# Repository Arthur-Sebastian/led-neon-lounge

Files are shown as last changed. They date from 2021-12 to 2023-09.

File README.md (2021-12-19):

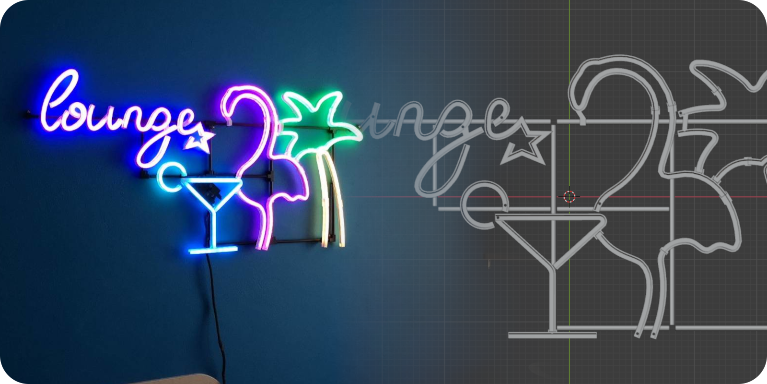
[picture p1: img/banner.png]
Banner image

# LED Lounge Neon!
An RGB LED neon project using 3d printed parts and custom AVR-based controller board with included software.

## PCB
Printed circuit board design (one-layer) files can be found inside ['/pcb'](/pcb). It was created in KiCad open-source
EDA.
The design includes all the parts names,
package formats, and source schematic. It can all be found by opening ['pcb.pro'](/pcb/pcb.pro). file.

## AVR source code and binary
The controller board uses a popular MCU, an ATmega168p. Software source can be found inside ['/src'](/src).
Compile using the included shell script, or create a makefile for yourself. The binary file ['/src/bin/out.bin'](/src/bin/out.bin)
can be directly uploaded to a matching MCU by using the 'upload.sh' script - it assumes your serial-usb converter is connected to
/dev/ttyUSB0 and that your MCU has a USART capable bootloader. Modify if needed.

## 3D Models for printing
Can be found inside ['/resource_3d'](/resource_3d). Those are all Blender files. 
All necessary STL exports are already made and contained within stl_* folders. 
Slice using your favourite tool, and print! 
(All models are optimised to fit a PRUSA Mini or bigger - min. work area of 175 x 175 x 175mm).

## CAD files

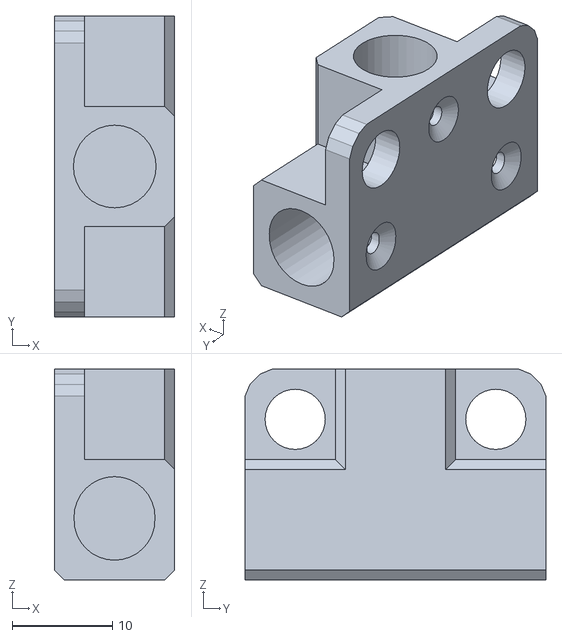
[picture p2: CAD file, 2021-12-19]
resource_3d/stl_framing/frame_T.stl
12.0 x 30.0 x 21.0

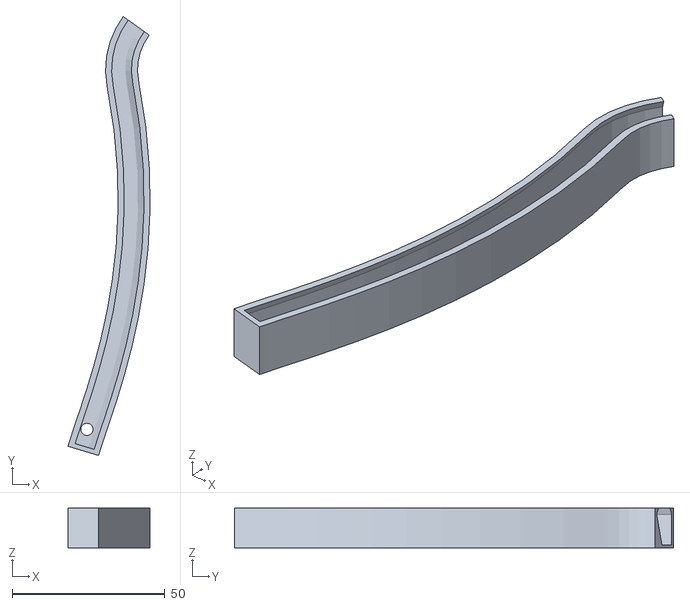
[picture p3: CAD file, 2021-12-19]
resource_3d/stl_shapes/flamingo_5.stl
26.9 x 143.9 x 13.0

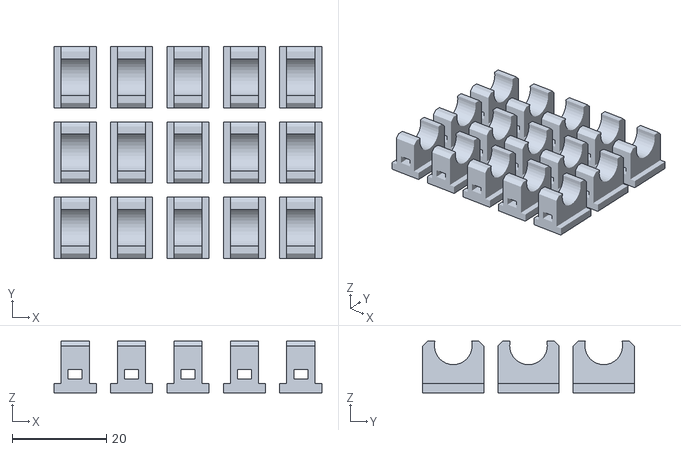
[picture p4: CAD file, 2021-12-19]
resource_3d/stl_framing/clamp.stl
57.0 x 45.0 x 11.0

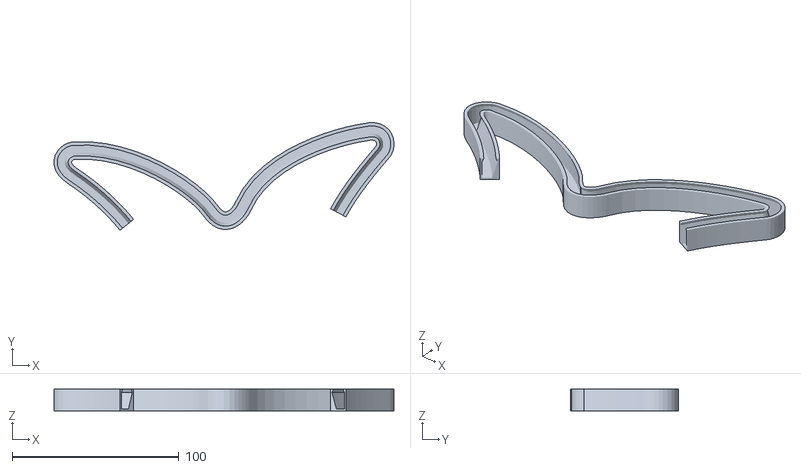
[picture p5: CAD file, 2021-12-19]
resource_3d/stl_shapes/palm_2.stl
204.1 x 64.6 x 13.0

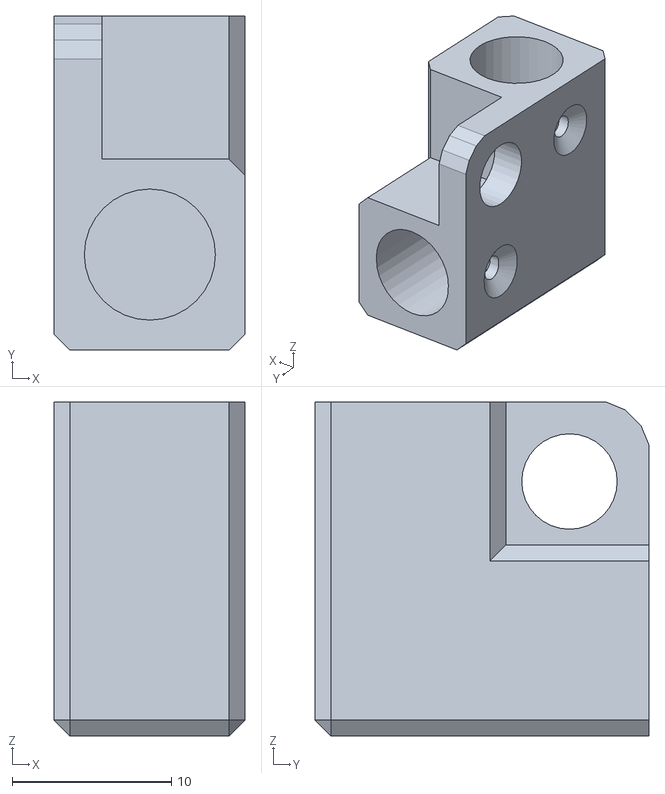
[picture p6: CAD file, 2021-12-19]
resource_3d/stl_framing/frame_L.stl
12.0 x 21.0 x 21.0

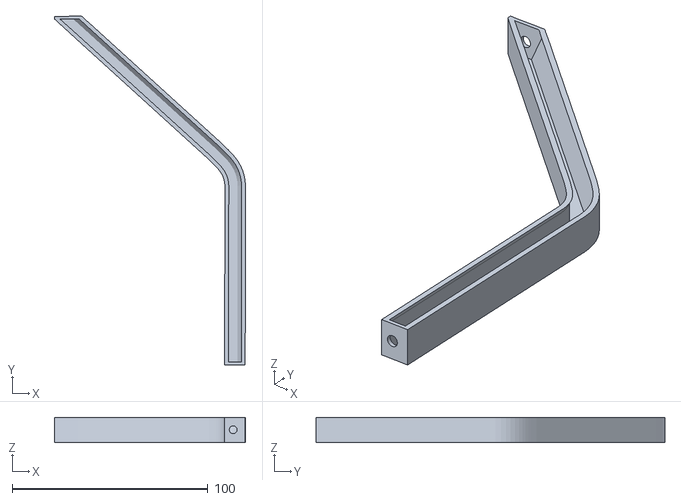
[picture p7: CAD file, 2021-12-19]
resource_3d/stl_shapes/glass_2.stl
97.5 x 178.0 x 13.0

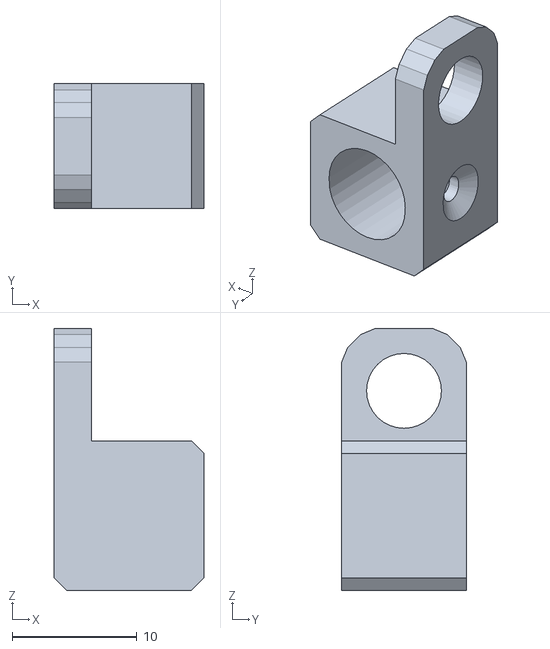
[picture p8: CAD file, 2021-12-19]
resource_3d/stl_framing/frame_E.stl
12.0 x 10.0 x 21.0

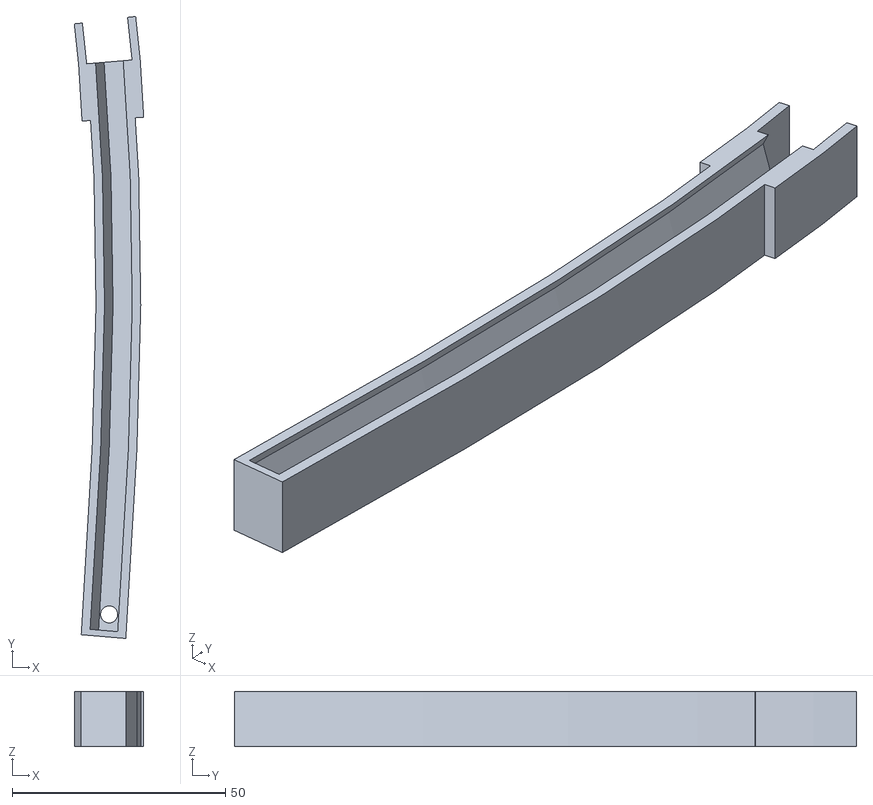
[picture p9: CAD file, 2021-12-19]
resource_3d/stl_shapes/palm_5.stl
16.3 x 145.9 x 13.0

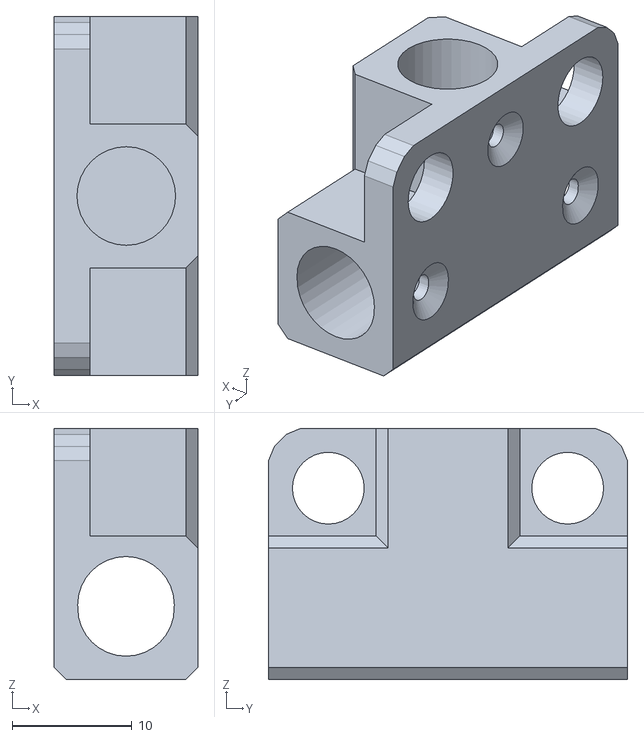
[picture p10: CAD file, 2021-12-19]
resource_3d/stl_framing/frame_P.stl
12.0 x 30.0 x 21.0

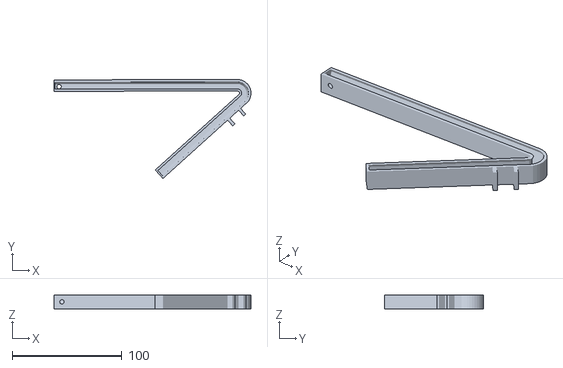
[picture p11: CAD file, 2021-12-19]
resource_3d/stl_shapes/glass_1.stl
179.5 x 90.2 x 13.0

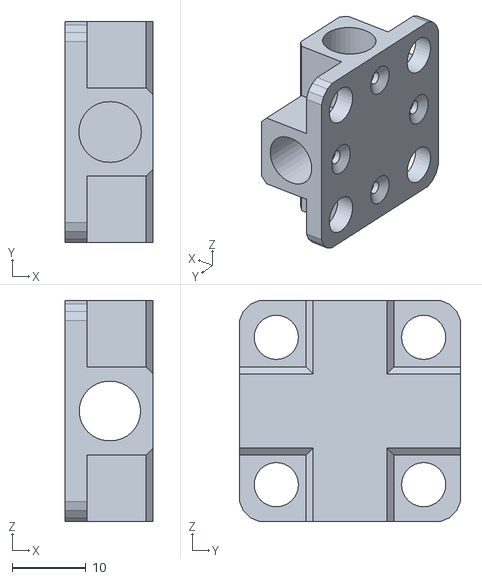
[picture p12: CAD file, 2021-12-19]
resource_3d/stl_framing/frame_X.stl
12.0 x 30.0 x 30.0

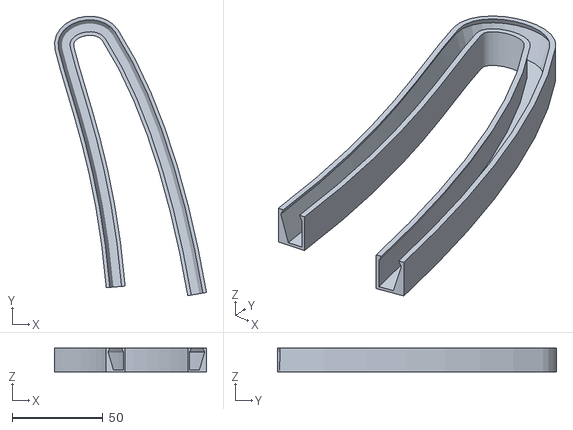
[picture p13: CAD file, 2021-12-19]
resource_3d/stl_shapes/palm_4.stl
83.9 x 154.2 x 13.0

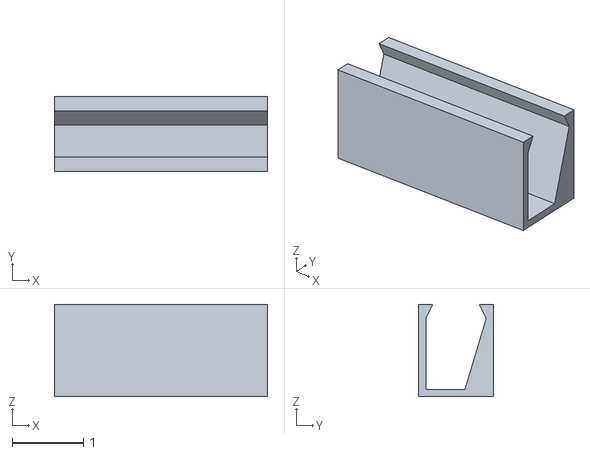
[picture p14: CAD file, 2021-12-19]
resource_3d/stl_framing/frametest.stl
3.00 x 1.05 x 1.30

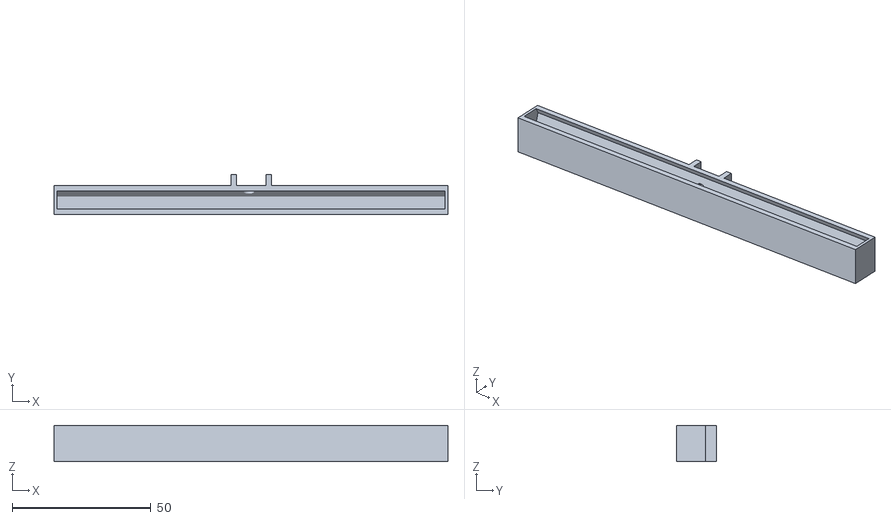
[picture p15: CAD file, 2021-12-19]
resource_3d/stl_shapes/glass_3.stl
142.0 x 14.5 x 13.0

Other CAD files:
resource_3d/stl_shapes/flamingo_2.stl
resource_3d/stl_shapes/garnish_1.stl
resource_3d/stl_shapes/flamingo_1.stl
resource_3d/stl_shapes/palm_3.stl
resource_3d/mainmodel.blend
resource_3d/stl_shapes/flamingo_3.stl
resource_3d/stl_shapes/flamingo_4.stl
resource_3d/stl_shapes/flamingo_6.stl
resource_3d/stl_shapes/lounge_1.stl
resource_3d/stl_shapes/lounge_2.stl
resource_3d/stl_shapes/lounge_3.stl
resource_3d/stl_shapes/lounge_4.stl
resource_3d/stl_shapes/palm_1.stl
resource_3d/stl_shapes/palm_6.stl

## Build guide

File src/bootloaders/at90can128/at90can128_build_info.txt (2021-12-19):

Optiboot_flash build output for at90can128 
https://github.com/MCUdude/optiboot_flash 
Build date and time: 15.05.2019 23:29 
Compiler: avr-gcc 5.4.0
 
F_CPU:		UART NUMBER:	LED PIN:	LED FLASHES:	EEPROM SUPPORT:	FLASH PG COPY:	DESIRED BAUD:	ACTUAL BAUD:	ERROR:	COMPILED SIZE:	OUTPUT FILE:
24000000L	UART0		B5		2		Yes		No		1000000		1000000		0.0%	636 bytes	optiboot_flash_at90can128_UART0_1000000_24000000L_BIGBOOT.hex
24000000L	UART0		B5		2		Yes		No		500000		500000		0.0%	636 bytes	optiboot_flash_at90can128_UART0_500000_24000000L_BIGBOOT.hex
24000000L	UART0		B5		2		Yes		No		250000		250000		0.0%	638 bytes	optiboot_flash_at90can128_UART0_250000_24000000L_BIGBOOT.hex
24000000L	UART0		B5		2		Yes		No		230400		230769		0.1%	638 bytes	optiboot_flash_at90can128_UART0_230400_24000000L_BIGBOOT.hex
24000000L	UART0		B5		2		Yes		No		115200		115384		0.1%	638 bytes	optiboot_flash_at90can128_UART0_115200_24000000L_BIGBOOT.hex
24000000L	UART0		B5		2		Yes		No		57600		57692		0.1%	638 bytes	optiboot_flash_at90can128_UART0_57600_24000000L_BIGBOOT.hex
24000000L	UART0		B5		2		Yes		No		38400		38461		0.1%	638 bytes	optiboot_flash_at90can128_UART0_38400_24000000L_BIGBOOT.hex
24000000L	UART0		B5		2		Yes		No		19200		19230		0.1%	638 bytes	optiboot_flash_at90can128_UART0_19200_24000000L_BIGBOOT.hex
20000000L	UART0		B5		2		Yes		No		500000		500000		0.0%	638 bytes	optiboot_flash_at90can128_UART0_500000_20000000L_BIGBOOT.hex
20000000L	UART0		B5		2		Yes		No		250000		250000		0.0%	638 bytes	optiboot_flash_at90can128_UART0_250000_20000000L_BIGBOOT.hex
20000000L	UART0		B5		2		Yes		No		115200		113636		-1.3%	638 bytes	optiboot_flash_at90can128_UART0_115200_20000000L_BIGBOOT.hex
20000000L	UART0		B5		2		Yes		No		19200		19230		0.1%	638 bytes	optiboot_flash_at90can128_UART0_19200_20000000L_BIGBOOT.hex
18432000L	UART0		B5		2		Yes		No		230400		230400		0.0%	638 bytes	optiboot_flash_at90can128_UART0_230400_18432000L_BIGBOOT.hex
18432000L	UART0		B5		2		Yes		No		115200		115200		0.0%	638 bytes	optiboot_flash_at90can128_UART0_115200_18432000L_BIGBOOT.hex
18432000L	UART0		B5		2		Yes		No		57600		57600		0.0%	638 bytes	optiboot_flash_at90can128_UART0_57600_18432000L_BIGBOOT.hex
18432000L	UART0		B5		2		Yes		No		38400		38400		0.0%	638 bytes	optiboot_flash_at90can128_UART0_38400_18432000L_BIGBOOT.hex
18432000L	UART0		B5		2		Yes		No		19200		19200		0.0%	638 bytes	optiboot_flash_at90can128_UART0_19200_18432000L_BIGBOOT.hex
18432000L	UART0		B5		2		Yes		No		9600		9600		0.0%	638 bytes	optiboot_flash_at90can128_UART0_9600_18432000L_BIGBOOT.hex
16000000L	UART0		B5		2		Yes		No		1000000		1000000		0.0%	638 bytes	optiboot_flash_at90can128_UART0_1000000_16000000L_BIGBOOT.hex
16000000L	UART0		B5		2		Yes		No		500000		500000		0.0%	638 bytes	optiboot_flash_at90can128_UART0_500000_16000000L_BIGBOOT.hex
16000000L	UART0		B5		2		Yes		No		250000		250000		0.0%	638 bytes	optiboot_flash_at90can128_UART0_250000_16000000L_BIGBOOT.hex
16000000L	UART0		B5		2		Yes		No		115200		117647		2.1%	638 bytes	optiboot_flash_at90can128_UART0_115200_16000000L_BIGBOOT.hex
16000000L	UART0		B5		2		Yes		No		38400		38461		0.1%	638 bytes	optiboot_flash_at90can128_UART0_38400_16000000L_BIGBOOT.hex
16000000L	UART0		B5		2		Yes		No		19200		19230		0.1%	638 bytes	optiboot_flash_at90can128_UART0_19200_16000000L_BIGBOOT.hex
16000000L	UART0		B5		2		Yes		No		9600		9615		0.1%	638 bytes	optiboot_flash_at90can128_UART0_9600_16000000L_BIGBOOT.hex
14745600L	UART0		B5		2		Yes		No		230400		230400		0.0%	638 bytes	optiboot_flash_at90can128_UART0_230400_14745600L_BIGBOOT.hex
14745600L	UART0		B5		2		Yes		No		115200		115200		0.0%	638 bytes	optiboot_flash_at90can128_UART0_115200_14745600L_BIGBOOT.hex
14745600L	UART0		B5		2		Yes		No		57600		57600		0.0%	638 bytes	optiboot_flash_at90can128_UART0_57600_14745600L_BIGBOOT.hex
14745600L	UART0		B5		2		Yes		No		38400		38400		0.0%	638 bytes	optiboot_flash_at90can128_UART0_38400_14745600L_BIGBOOT.hex
14745600L	UART0		B5		2		Yes		No		19200		19200		0.0%	638 bytes	optiboot_flash_at90can128_UART0_19200_14745600L_BIGBOOT.hex
14745600L	UART0		B5		2		Yes		No		9600		9600		0.0%	638 bytes	optiboot_flash_at90can128_UART0_9600_14745600L_BIGBOOT.hex
12000000L	UART0		B5		2		Yes		No		500000		500000		0.0%	636 bytes	optiboot_flash_at90can128_UART0_500000_12000000L_BIGBOOT.hex
12000000L	UART0		B5		2		Yes		No		250000		250000		0.0%	636 bytes	optiboot_flash_at90can128_UART0_250000_12000000L_BIGBOOT.hex
12000000L	UART0		B5		2		Yes		No		57600		57692		0.1%	638 bytes	optiboot_flash_at90can128_UART0_57600_12000000L_BIGBOOT.hex
12000000L	UART0		B5		2		Yes		No		19200		19230		0.1%	638 bytes	optiboot_flash_at90can128_UART0_19200_12000000L_BIGBOOT.hex
12000000L	UART0		B5		2		Yes		No		9600		9615		0.1%	638 bytes	optiboot_flash_at90can128_UART0_9600_12000000L_BIGBOOT.hex
11059200L	UART0		B5		2		Yes		No		230400		230400		0.0%	636 bytes	optiboot_flash_at90can128_UART0_230400_11059200L_BIGBOOT.hex
11059200L	UART0		B5		2		Yes		No		115200		115200		0.0%	638 bytes	optiboot_flash_at90can128_UART0_115200_11059200L_BIGBOOT.hex
11059200L	UART0		B5		2		Yes		No		57600		57600		0.0%	638 bytes	optiboot_flash_at90can128_UART0_57600_11059200L_BIGBOOT.hex
11059200L	UART0		B5		2		Yes		No		38400		38400		0.0%	638 bytes	optiboot_flash_at90can128_UART0_38400_11059200L_BIGBOOT.hex
11059200L	UART0		B5		2		Yes		No		19200		19200		0.0%	638 bytes	optiboot_flash_at90can128_UART0_19200_11059200L_BIGBOOT.hex
11059200L	UART0		B5		2		Yes		No		9600		9600		0.0%	638 bytes	optiboot_flash_at90can128_UART0_9600_11059200L_BIGBOOT.hex
8000000L	UART0		B5		2		Yes		No		1000000		1000000		0.0%	636 bytes	optiboot_flash_at90can128_UART0_1000000_8000000L_BIGBOOT.hex
8000000L	UART0		B5		2		Yes		No		500000		500000		0.0%	638 bytes	optiboot_flash_at90can128_UART0_500000_8000000L_BIGBOOT.hex
8000000L	UART0		B5		2		Yes		No		250000		250000		0.0%	638 bytes	optiboot_flash_at90can128_UART0_250000_8000000L_BIGBOOT.hex
8000000L	UART0		B5		2		Yes		No		115200		111111		-3.5%	638 bytes	optiboot_flash_at90can128_UART0_115200_8000000L_BIGBOOT.hex
8000000L	UART0		B5		2		Yes		No		57600		58823		2.1%	638 bytes	optiboot_flash_at90can128_UART0_57600_8000000L_BIGBOOT.hex
8000000L	UART0		B5		2		Yes		No		38400		38461		0.1%	638 bytes	optiboot_flash_at90can128_UART0_38400_8000000L_BIGBOOT.hex
8000000L	UART0		B5		2		Yes		No		19200		19230		0.1%	638 bytes	optiboot_flash_at90can128_UART0_19200_8000000L_BIGBOOT.hex
8000000L	UART0		B5		2		Yes		No		9600		9615		0.1%	638 bytes	optiboot_flash_at90can128_UART0_9600_8000000L_BIGBOOT.hex
7372800L	UART0		B5		2		Yes		No		230400		230400		0.0%	638 bytes	optiboot_flash_at90can128_UART0_230400_7372800L_BIGBOOT.hex
7372800L	UART0		B5		2		Yes		No		115200		115200		0.0%	638 bytes	optiboot_flash_at90can128_UART0_115200_7372800L_BIGBOOT.hex
7372800L	UART0		B5		2		Yes		No		57600		57600		0.0%	638 bytes	optiboot_flash_at90can128_UART0_57600_7372800L_BIGBOOT.hex
7372800L	UART0		B5		2		Yes		No		38400		38400		0.0%	638 bytes	optiboot_flash_at90can128_UART0_38400_7372800L_BIGBOOT.hex
7372800L	UART0		B5		2		Yes		No		19200		19200		0.0%	638 bytes	optiboot_flash_at90can128_UART0_19200_7372800L_BIGBOOT.hex
7372800L	UART0		B5		2		Yes		No		9600		9600		0.0%	638 bytes	optiboot_flash_at90can128_UART0_9600_7372800L_BIGBOOT.hex
4000000L	UART0		B5		2		Yes		No		500000		500000		0.0%	636 bytes	optiboot_flash_at90can128_UART0_500000_4000000L_BIGBOOT.hex
4000000L	UART0		B5		2		Yes		No		250000		250000		0.0%	638 bytes	optiboot_flash_at90can128_UART0_250000_4000000L_BIGBOOT.hex
4000000L	UART0		B5		2		Yes		No		19200		19230		0.1%	638 bytes	optiboot_flash_at90can128_UART0_19200_4000000L_BIGBOOT.hex
4000000L	UART0		B5		2		Yes		No		9600		9615		0.1%	638 bytes	optiboot_flash_at90can128_UART0_9600_4000000L_BIGBOOT.hex
3686400L	UART0		B5		2		Yes		No		230400		230400		0.0%	638 bytes	optiboot_flash_at90can128_UART0_230400_3686400L_BIGBOOT.hex
3686400L	UART0		B5		2		Yes		No		115200		115200		0.0%	638 bytes	optiboot_flash_at90can128_UART0_115200_3686400L_BIGBOOT.hex
3686400L	UART0		B5		2		Yes		No		57600		57600		0.0%	638 bytes	optiboot_flash_at90can128_UART0_57600_3686400L_BIGBOOT.hex
3686400L	UART0		B5		2		Yes		No		38400		38400		0.0%	638 bytes	optiboot_flash_at90can128_UART0_38400_3686400L_BIGBOOT.hex
3686400L	UART0		B5		2		Yes		No		19200		19200		0.0%	638 bytes	optiboot_flash_at90can128_UART0_19200_3686400L_BIGBOOT.hex
3686400L	UART0		B5		2		Yes		No		9600		9600		0.0%	638 bytes	optiboot_flash_at90can128_UART0_9600_3686400L_BIGBOOT.hex
2000000L	UART0		B5		2		Yes		No		250000		250000		0.0%	636 bytes	optiboot_flash_at90can128_UART0_250000_2000000L_BIGBOOT.hex
2000000L	UART0		B5		2		Yes		No		19200		19230		0.1%	638 bytes	optiboot_flash_at90can128_UART0_19200_2000000L_BIGBOOT.hex
2000000L	UART0		B5		2		Yes		No		9600		9615		0.1%	638 bytes	optiboot_flash_at90can128_UART0_9600_2000000L_BIGBOOT.hex
1843200L	UART0		B5		2		Yes		No		230400		230400		0.0%	636 bytes	optiboot_flash_at90can128_UART0_230400_1843200L_BIGBOOT.hex
1843200L	UART0		B5		2		Yes		No		115200		115200		0.0%	638 bytes	optiboot_flash_at90can128_UART0_115200_1843200L_BIGBOOT.hex
1843200L	UART0		B5		2		Yes		No		57600		57600		0.0%	638 bytes	optiboot_flash_at90can128_UART0_57600_1843200L_BIGBOOT.hex
1843200L	UART0		B5		2		Yes		No		38400		38400		0.0%	636 bytes	optiboot_flash_at90can128_UART0_38400_1843200L_BIGBOOT.hex
1843200L	UART0		B5		2		Yes		No		19200		19200		0.0%	638 bytes	optiboot_flash_at90can128_UART0_19200_1843200L_BIGBOOT.hex
1843200L	UART0		B5		2		Yes		No		9600		9600		0.0%	638 bytes	optiboot_flash_at90can128_UART0_9600_1843200L_BIGBOOT.hex
1000000L	UART0		B5		2		Yes		No		9600		9615		0.1%	638 bytes	optiboot_flash_at90can128_UART0_9600_1000000L_BIGBOOT.hex

Optiboot_flash build output for at90can128 
https://github.com/MCUdude/optiboot_flash 
Build date and time: 15.05.2019 23:29 
Compiler: avr-gcc 5.4.0
 
F_CPU:		UART NUMBER:	LED PIN:	LED FLASHES:	EEPROM SUPPORT:	FLASH PG COPY:	DESIRED BAUD:	ACTUAL BAUD:	ERROR:	COMPILED SIZE:	OUTPUT FILE:
24000000L	UART1		B5		2		Yes		No		1000000		1000000		0.0%	636 bytes	optiboot_flash_at90can128_UART1_1000000_24000000L_BIGBOOT.hex
24000000L	UART1		B5		2		Yes		No		500000		500000		0.0%	636 bytes	optiboot_flash_at90can128_UART1_500000_24000000L_BIGBOOT.hex
24000000L	UART1		B5		2		Yes		No		250000		250000		0.0%	638 bytes	optiboot_flash_at90can128_UART1_250000_24000000L_BIGBOOT.hex
24000000L	UART1		B5		2		Yes		No		230400		230769		0.1%	638 bytes	optiboot_flash_at90can128_UART1_230400_24000000L_BIGBOOT.hex
24000000L	UART1		B5		2		Yes		No		115200		115384		0.1%	638 bytes	optiboot_flash_at90can128_UART1_115200_24000000L_BIGBOOT.hex
24000000L	UART1		B5		2		Yes		No		57600		57692		0.1%	638 bytes	optiboot_flash_at90can128_UART1_57600_24000000L_BIGBOOT.hex
24000000L	UART1		B5		2		Yes		No		38400		38461		0.1%	638 bytes	optiboot_flash_at90can128_UART1_38400_24000000L_BIGBOOT.hex
24000000L	UART1		B5		2		Yes		No		19200		19230		0.1%	638 bytes	optiboot_flash_at90can128_UART1_19200_24000000L_BIGBOOT.hex
20000000L	UART1		B5		2		Yes		No		500000		500000		0.0%	638 bytes	optiboot_flash_at90can128_UART1_500000_20000000L_BIGBOOT.hex
20000000L	UART1		B5		2		Yes		No		250000		250000		0.0%	638 bytes	optiboot_flash_at90can128_UART1_250000_20000000L_BIGBOOT.hex
20000000L	UART1		B5		2		Yes		No		115200		113636		-1.3%	638 bytes	optiboot_flash_at90can128_UART1_115200_20000000L_BIGBOOT.hex
20000000L	UART1		B5		2		Yes		No		19200		19230		0.1%	638 bytes	optiboot_flash_at90can128_UART1_19200_20000000L_BIGBOOT.hex
18432000L	UART1		B5		2		Yes		No		230400		230400		0.0%	638 bytes	optiboot_flash_at90can128_UART1_230400_18432000L_BIGBOOT.hex
18432000L	UART1		B5		2		Yes		No		115200		115200		0.0%	638 bytes	optiboot_flash_at90can128_UART1_115200_18432000L_BIGBOOT.hex
18432000L	UART1		B5		2		Yes		No		57600		57600		0.0%	638 bytes	optiboot_flash_at90can128_UART1_57600_18432000L_BIGBOOT.hex
18432000L	UART1		B5		2		Yes		No		38400		38400		0.0%	638 bytes	optiboot_flash_at90can128_UART1_38400_18432000L_BIGBOOT.hex
18432000L	UART1		B5		2		Yes		No		19200		19200		0.0%	638 bytes	optiboot_flash_at90can128_UART1_19200_18432000L_BIGBOOT.hex
18432000L	UART1		B5		2		Yes		No		9600		9600		0.0%	638 bytes	optiboot_flash_at90can128_UART1_9600_18432000L_BIGBOOT.hex
16000000L	UART1		B5		2		Yes		No		1000000		1000000		0.0%	638 bytes	optiboot_flash_at90can128_UART1_1000000_16000000L_BIGBOOT.hex
16000000L	UART1		B5		2		Yes		No		500000		500000		0.0%	638 bytes	optiboot_flash_at90can128_UART1_500000_16000000L_BIGBOOT.hex
16000000L	UART1		B5		2		Yes		No		250000		250000		0.0%	638 bytes	optiboot_flash_at90can128_UART1_250000_16000000L_BIGBOOT.hex
16000000L	UART1		B5		2		Yes		No		115200		117647		2.1%	638 bytes	optiboot_flash_at90can128_UART1_115200_16000000L_BIGBOOT.hex
16000000L	UART1		B5		2		Yes		No		38400		38461		0.1%	638 bytes	optiboot_flash_at90can128_UART1_38400_16000000L_BIGBOOT.hex
16000000L	UART1		B5		2		Yes		No		19200		19230		0.1%	638 bytes	optiboot_flash_at90can128_UART1_19200_16000000L_BIGBOOT.hex
16000000L	UART1		B5		2		Yes		No		9600		9615		0.1%	638 bytes	optiboot_flash_at90can128_UART1_9600_16000000L_BIGBOOT.hex
14745600L	UART1		B5		2		Yes		No		230400		230400		0.0%	638 bytes	optiboot_flash_at90can128_UART1_230400_14745600L_BIGBOOT.hex
14745600L	UART1		B5		2		Yes		No		115200		115200		0.0%	638 bytes	optiboot_flash_at90can128_UART1_115200_14745600L_BIGBOOT.hex
14745600L	UART1		B5		2		Yes		No		57600		57600		0.0%	638 bytes	optiboot_flash_at90can128_UART1_57600_14745600L_BIGBOOT.hex
14745600L	UART1		B5		2		Yes		No		38400		38400		0.0%	638 bytes	optiboot_flash_at90can128_UART1_38400_14745600L_BIGBOOT.hex
14745600L	UART1		B5		2		Yes		No		19200		19200		0.0%	638 bytes	optiboot_flash_at90can128_UART1_19200_14745600L_BIGBOOT.hex
14745600L	UART1		B5		2		Yes		No		9600		9600		0.0%	638 bytes	optiboot_flash_at90can128_UART1_9600_14745600L_BIGBOOT.hex
12000000L	UART1		B5		2		Yes		No		500000		500000		0.0%	636 bytes	optiboot_flash_at90can128_UART1_500000_12000000L_BIGBOOT.hex
12000000L	UART1		B5		2		Yes		No		250000		250000		0.0%	636 bytes	optiboot_flash_at90can128_UART1_250000_12000000L_BIGBOOT.hex
12000000L	UART1		B5		2		Yes		No		57600		57692		0.1%	638 bytes	optiboot_flash_at90can128_UART1_57600_12000000L_BIGBOOT.hex
12000000L	UART1		B5		2		Yes		No		19200		19230		0.1%	638 bytes	optiboot_flash_at90can128_UART1_19200_12000000L_BIGBOOT.hex
12000000L	UART1		B5		2		Yes		No		9600		9615		0.1%	638 bytes	optiboot_flash_at90can128_UART1_9600_12000000L_BIGBOOT.hex
11059200L	UART1		B5		2		Yes		No		230400		230400		0.0%	636 bytes	optiboot_flash_at90can128_UART1_230400_11059200L_BIGBOOT.hex
11059200L	UART1		B5		2		Yes		No		115200		115200		0.0%	638 bytes	optiboot_flash_at90can128_UART1_115200_11059200L_BIGBOOT.hex
11059200L	UART1		B5		2		Yes		No		57600		57600		0.0%	638 bytes	optiboot_flash_at90can128_UART1_57600_11059200L_BIGBOOT.hex
11059200L	UART1		B5		2		Yes		No		38400		38400		0.0%	638 bytes	optiboot_flash_at90can128_UART1_38400_11059200L_BIGBOOT.hex
11059200L	UART1		B5		2		Yes		No		19200		19200		0.0%	638 bytes	optiboot_flash_at90can128_UART1_19200_11059200L_BIGBOOT.hex
11059200L	UART1		B5		2		Yes		No		9600		9600		0.0%	638 bytes	optiboot_flash_at90can128_UART1_9600_11059200L_BIGBOOT.hex
8000000L	UART1		B5		2		Yes		No		1000000		1000000		0.0%	636 bytes	optiboot_flash_at90can128_UART1_1000000_8000000L_BIGBOOT.hex
8000000L	UART1		B5		2		Yes		No		500000		500000		0.0%	638 bytes	optiboot_flash_at90can128_UART1_500000_8000000L_BIGBOOT.hex
8000000L	UART1		B5		2		Yes		No		250000		250000		0.0%	638 bytes	optiboot_flash_at90can128_UART1_250000_8000000L_BIGBOOT.hex
8000000L	UART1		B5		2		Yes		No		115200		111111		-3.5%	638 bytes	optiboot_flash_at90can128_UART1_115200_8000000L_BIGBOOT.hex
8000000L	UART1		B5		2		Yes		No		57600		58823		2.1%	638 bytes	optiboot_flash_at90can128_UART1_57600_8000000L_BIGBOOT.hex
8000000L	UART1		B5		2		Yes		No		38400		38461		0.1%	638 bytes	optiboot_flash_at90can128_UART1_38400_8000000L_BIGBOOT.hex
8000000L	UART1		B5		2		Yes		No		19200		19230		0.1%	638 bytes	optiboot_flash_at90can128_UART1_19200_8000000L_BIGBOOT.hex
8000000L	UART1		B5		2		Yes		No		9600		9615		0.1%	638 bytes	optiboot_flash_at90can128_UART1_9600_8000000L_BIGBOOT.hex
7372800L	UART1		B5		2		Yes		No		230400		230400		0.0%	638 bytes	optiboot_flash_at90can128_UART1_230400_7372800L_BIGBOOT.hex
7372800L	UART1		B5		2		Yes		No		115200		115200		0.0%	638 bytes	optiboot_flash_at90can128_UART1_115200_7372800L_BIGBOOT.hex
7372800L	UART1		B5		2		Yes		No		57600		57600		0.0%	638 bytes	optiboot_flash_at90can128_UART1_57600_7372800L_BIGBOOT.hex
7372800L	UART1		B5		2		Yes		No		38400		38400		0.0%	638 bytes	optiboot_flash_at90can128_UART1_38400_7372800L_BIGBOOT.hex
7372800L	UART1		B5		2		Yes		No		19200		19200		0.0%	638 bytes	optiboot_flash_at90can128_UART1_19200_7372800L_BIGBOOT.hex
7372800L	UART1		B5		2		Yes		No		9600		9600		0.0%	638 bytes	optiboot_flash_at90can128_UART1_9600_7372800L_BIGBOOT.hex
4000000L	UART1		B5		2		Yes		No		500000		500000		0.0%	636 bytes	optiboot_flash_at90can128_UART1_500000_4000000L_BIGBOOT.hex
4000000L	UART1		B5		2		Yes		No		250000		250000		0.0%	638 bytes	optiboot_flash_at90can128_UART1_250000_4000000L_BIGBOOT.hex
4000000L	UART1		B5		2		Yes		No		19200		19230		0.1%	638 bytes	optiboot_flash_at90can128_UART1_19200_4000000L_BIGBOOT.hex
4000000L	UART1		B5		2		Yes		No		9600		9615		0.1%	638 bytes	optiboot_flash_at90can128_UART1_9600_4000000L_BIGBOOT.hex
3686400L	UART1		B5		2		Yes		No		230400		230400		0.0%	638 bytes	optiboot_flash_at90can128_UART1_230400_3686400L_BIGBOOT.hex
3686400L	UART1		B5		2		Yes		No		115200		115200		0.0%	638 bytes	optiboot_flash_at90can128_UART1_115200_3686400L_BIGBOOT.hex
3686400L	UART1		B5		2		Yes		No		57600		57600		0.0%	638 bytes	optiboot_flash_at90can128_UART1_57600_3686400L_BIGBOOT.hex
3686400L	UART1		B5		2		Yes		No		38400		38400		0.0%	638 bytes	optiboot_flash_at90can128_UART1_38400_3686400L_BIGBOOT.hex
3686400L	UART1		B5		2		Yes		No		19200		19200		0.0%	638 bytes	optiboot_flash_at90can128_UART1_19200_3686400L_BIGBOOT.hex
3686400L	UART1		B5		2		Yes		No		9600		9600		0.0%	638 bytes	optiboot_flash_at90can128_UART1_9600_3686400L_BIGBOOT.hex
2000000L	UART1		B5		2		Yes		No		250000		250000		0.0%	636 bytes	optiboot_flash_at90can128_UART1_250000_2000000L_BIGBOOT.hex
2000000L	UART1		B5		2		Yes		No		19200		19230		0.1%	638 bytes	optiboot_flash_at90can128_UART1_19200_2000000L_BIGBOOT.hex
2000000L	UART1		B5		2		Yes		No		9600		9615		0.1%	638 bytes	optiboot_flash_at90can128_UART1_9600_2000000L_BIGBOOT.hex
1843200L	UART1		B5		2		Yes		No		230400		230400		0.0%	636 bytes	optiboot_flash_at90can128_UART1_230400_1843200L_BIGBOOT.hex
1843200L	UART1		B5		2		Yes		No		115200		115200		0.0%	638 bytes	optiboot_flash_at90can128_UART1_115200_1843200L_BIGBOOT.hex
1843200L	UART1		B5		2		Yes		No		57600		57600		0.0%	638 bytes	optiboot_flash_at90can128_UART1_57600_1843200L_BIGBOOT.hex
1843200L	UART1		B5		2		Yes		No		38400		38400		0.0%	636 bytes	optiboot_flash_at90can128_UART1_38400_1843200L_BIGBOOT.hex
1843200L	UART1		B5		2		Yes		No		19200		19200		0.0%	638 bytes	optiboot_flash_at90can128_UART1_19200_1843200L_BIGBOOT.hex
1843200L	UART1		B5		2		Yes		No		9600		9600		0.0%	638 bytes	optiboot_flash_at90can128_UART1_9600_1843200L_BIGBOOT.hex
1000000L	UART1		B5		2		Yes		No		9600		9615		0.1%	638 bytes	optiboot_flash_at90can128_UART1_9600_1000000L_BIGBOOT.hex

Optiboot_flash build output for at90can128 
https://github.com/MCUdude/optiboot_flash 
Build date and time: 18.05.2019 20:26 
Compiler: avr-gcc 5.4.0
 
F_CPU:		UART NUMBER:	LED PIN:	LED FLASHES:	EEPROM SUPPORT:	FLASH PG COPY:	DESIRED BAUD:	ACTUAL BAUD:	ERROR:	COMPILED SIZE:	OUTPUT FILE:
18432000L	UART0		B5		2		Yes		No		460800		460800		0.0%	638 bytes	optiboot_flash_at90can128_UART0_460800_18432000L_BIGBOOT.hex
14745600L	UART0		B5		2		Yes		No		460800		460800		0.0%	638 bytes	optiboot_flash_at90can128_UART0_460800_14745600L_BIGBOOT.hex
11059200L	UART0		B5		2		Yes		No		460800		460800		0.0%	636 bytes	optiboot_flash_at90can128_UART0_460800_11059200L_BIGBOOT.hex
7372800L	UART0		B5		2		Yes		No		460800		460800		0.0%	638 bytes	optiboot_flash_at90can128_UART0_460800_7372800L_BIGBOOT.hex
3686400L	UART0		B5		2		Yes		No		460800		460800		0.0%	636 bytes	optiboot_flash_at90can128_UART0_460800_3686400L_BIGBOOT.hex

Optiboot_flash build output for at90can128 
https://github.com/MCUdude/optiboot_flash 
Build date and time: 18.05.2019 20:27 
Compiler: avr-gcc 5.4.0
 
F_CPU:		UART NUMBER:	LED PIN:	LED FLASHES:	EEPROM SUPPORT:	FLASH PG COPY:	DESIRED BAUD:	ACTUAL BAUD:	ERROR:	COMPILED SIZE:	OUTPUT FILE:
18432000L	UART1		B5		2		Yes		No		460800		460800		0.0%	638 bytes	optiboot_flash_at90can128_UART1_460800_18432000L_BIGBOOT.hex
14745600L	UART1		B5		2		Yes		No		460800		460800		0.0%	638 bytes	optiboot_flash_at90can128_UART1_460800_14745600L_BIGBOOT.hex
11059200L	UART1		B5		2		Yes		No		460800		460800		0.0%	636 bytes	optiboot_flash_at90can128_UART1_460800_11059200L_BIGBOOT.hex
7372800L	UART1		B5		2		Yes		No		460800		460800		0.0%	638 bytes	optiboot_flash_at90can128_UART1_460800_7372800L_BIGBOOT.hex
3686400L	UART1		B5		2		Yes		No		460800		460800		0.0%	636 bytes	optiboot_flash_at90can128_UART1_460800_3686400L_BIGBOOT.hex

Optiboot_flash build output for at90can128 
https://github.com/MCUdude/optiboot_flash 
Build date and time: 03.08.2019 01:05 
Compiler: avr-gcc 5.4.0
 
F_CPU:		UART NUMBER:	LED PIN:	LED FLASHES:	EEPROM SUPPORT:	FLASH PG COPY:	DESIRED BAUD:	ACTUAL BAUD:	ERROR:	COMPILED SIZE:	OUTPUT FILE:
22118400L	UART0		B5		2		Yes		No		460800		460800		0.0%	636 bytes	optiboot_flash_at90can128_UART0_460800_22118400L_BIGBOOT.hex
22118400L	UART0		B5		2		Yes		No		230400		230400		0.0%	638 bytes	optiboot_flash_at90can128_UART0_230400_22118400L_BIGBOOT.hex
22118400L	UART0		B5		2		Yes		No		115200		115200		0.0%	638 bytes	optiboot_flash_at90can128_UART0_115200_22118400L_BIGBOOT.hex
22118400L	UART0		B5		2		Yes		No		57600		57600		0.0%	638 bytes	optiboot_flash_at90can128_UART0_57600_22118400L_BIGBOOT.hex
22118400L	UART0		B5		2		Yes		No		38400		38400		0.0%	638 bytes	optiboot_flash_at90can128_UART0_38400_22118400L_BIGBOOT.hex
22118400L	UART0		B5		2		Yes		No		19200		19200		0.0%	638 bytes	optiboot_flash_at90can128_UART0_19200_22118400L_BIGBOOT.hex

Optiboot_flash build output for at90can128 
https://github.com/MCUdude/optiboot_flash 
Build date and time: 03.08.2019 01:05 
Compiler: avr-gcc 5.4.0
 
F_CPU:		UART NUMBER:	LED PIN:	LED FLASHES:	EEPROM SUPPORT:	FLASH PG COPY:	DESIRED BAUD:	ACTUAL BAUD:	ERROR:	COMPILED SIZE:	OUTPUT FILE:
22118400L	UART1		B5		2		Yes		No		460800		460800		0.0%	636 bytes	optiboot_flash_at90can128_UART1_460800_22118400L_BIGBOOT.hex
22118400L	UART1		B5		2		Yes		No		230400		230400		0.0%	638 bytes	optiboot_flash_at90can128_UART1_230400_22118400L_BIGBOOT.hex
22118400L	UART1		B5		2		Yes		No		115200		115200		0.0%	638 bytes	optiboot_flash_at90can128_UART1_115200_22118400L_BIGBOOT.hex
22118400L	UART1		B5		2		Yes		No		57600		57600		0.0%	638 bytes	optiboot_flash_at90can128_UART1_57600_22118400L_BIGBOOT.hex
22118400L	UART1		B5		2		Yes		No		38400		38400		0.0%	638 bytes	optiboot_flash_at90can128_UART1_38400_22118400L_BIGBOOT.hex
22118400L	UART1		B5		2		Yes		No		19200		19200		0.0%	638 bytes	optiboot_flash_at90can128_UART1_19200_22118400L_BIGBOOT.hex

Optiboot_flash build output for at90can128 
https://github.com/MCUdude/optiboot_flash 
Build date and time: 04.11.2019 19:39 
Compiler: avr-gcc 7.3.0
 
F_CPU:		UART NUMBER:	LED PIN:	LED FLASHES:	EEPROM SUPPORT:	FLASH PG COPY:	DESIRED BAUD:	ACTUAL BAUD:	ERROR:	COMPILED SIZE:	OUTPUT FILE:
24000000L	UART0		B5		2		Yes		No		1000000		1000000		0.0%	640 bytes	optiboot_flash_at90can128_UART0_1000000_24000000L_B5_BIGBOOT.hex
24000000L	UART0		B5		2		Yes		No		500000		500000		0.0%	640 bytes	optiboot_flash_at90can128_UART0_500000_24000000L_B5_BIGBOOT.hex
24000000L	UART0		B5		2		Yes		No		250000		250000		0.0%	642 bytes	optiboot_flash_at90can128_UART0_250000_24000000L_B5_BIGBOOT.hex
24000000L	UART0		B5		2		Yes		No		230400		230769		0.1%	642 bytes	optiboot_flash_at90can128_UART0_230400_24000000L_B5_BIGBOOT.hex
24000000L	UART0		B5		2		Yes		No		115200		115384		0.1%	642 bytes	optiboot_flash_at90can128_UART0_115200_24000000L_B5_BIGBOOT.hex
24000000L	UART0		B5		2		Yes		No		57600		57692		0.1%	642 bytes	optiboot_flash_at90can128_UART0_57600_24000000L_B5_BIGBOOT.hex
24000000L	UART0		B5		2		Yes		No		38400		38461		0.1%	642 bytes	optiboot_flash_at90can128_UART0_38400_24000000L_B5_BIGBOOT.hex
24000000L	UART0		B5		2		Yes		No		19200		19230		0.1%	642 bytes	optiboot_flash_at90can128_UART0_19200_24000000L_B5_BIGBOOT.hex
22118400L	UART0		B5		2		Yes		No		460800		460800		0.0%	640 bytes	optiboot_flash_at90can128_UART0_460800_22118400L_B5_BIGBOOT.hex
22118400L	UART0		B5		2		Yes		No		230400		230400		0.0%	642 bytes	optiboot_flash_at90can128_UART0_230400_22118400L_B5_BIGBOOT.hex
22118400L	UART0		B5		2		Yes		No		115200		115200		0.0%	642 bytes	optiboot_flash_at90can128_UART0_115200_22118400L_B5_BIGBOOT.hex
22118400L	UART0		B5		2		Yes		No		57600		57600		0.0%	642 bytes	optiboot_flash_at90can128_UART0_57600_22118400L_B5_BIGBOOT.hex
22118400L	UART0		B5		2		Yes		No		38400		38400		0.0%	642 bytes	optiboot_flash_at90can128_UART0_38400_22118400L_B5_BIGBOOT.hex
22118400L	UART0		B5		2		Yes		No		19200		19200		0.0%	642 bytes	optiboot_flash_at90can128_UART0_19200_22118400L_B5_BIGBOOT.hex
20000000L	UART0		B5		2		Yes		No		500000		500000		0.0%	642 bytes	optiboot_flash_at90can128_UART0_500000_20000000L_B5_BIGBOOT.hex
20000000L	UART0		B5		2		Yes		No		250000		250000		0.0%	642 bytes	optiboot_flash_at90can128_UART0_250000_20000000L_B5_BIGBOOT.hex
20000000L	UART0		B5		2		Yes		No		115200		113636		-1.3%	642 bytes	optiboot_flash_at90can128_UART0_115200_20000000L_B5_BIGBOOT.hex
20000000L	UART0		B5		2		Yes		No		19200		19230		0.1%	642 bytes	optiboot_flash_at90can128_UART0_19200_20000000L_B5_BIGBOOT.hex
18432000L	UART0		B5		2		Yes		No		460800		460800		0.0%	642 bytes	optiboot_flash_at90can128_UART0_460800_18432000L_B5_BIGBOOT.hex
18432000L	UART0		B5		2		Yes		No		230400		230400		0.0%	642 bytes	optiboot_flash_at90can128_UART0_230400_18432000L_B5_BIGBOOT.hex
18432000L	UART0		B5		2		Yes		No		115200		115200		0.0%	642 bytes	optiboot_flash_at90can128_UART0_115200_18432000L_B5_BIGBOOT.hex
18432000L	UART0		B5		2		Yes		No		57600		57600		0.0%	642 bytes	optiboot_flash_at90can128_UART0_57600_18432000L_B5_BIGBOOT.hex
18432000L	UART0		B5		2		Yes		No		38400		38400		0.0%	642 bytes	optiboot_flash_at90can128_UART0_38400_18432000L_B5_BIGBOOT.hex
18432000L	UART0		B5		2		Yes		No		19200		19200		0.0%	642 bytes	optiboot_flash_at90can128_UART0_19200_18432000L_B5_BIGBOOT.hex
18432000L	UART0		B5		2		Yes		No		9600		9600		0.0%	642 bytes	optiboot_flash_at90can128_UART0_9600_18432000L_B5_BIGBOOT.hex
16000000L	UART0		B5		2		Yes		No		1000000		1000000		0.0%	642 bytes	optiboot_flash_at90can128_UART0_1000000_16000000L_B5_BIGBOOT.hex
16000000L	UART0		B5		2		Yes		No		500000		500000		0.0%	642 bytes	optiboot_flash_at90can128_UART0_500000_16000000L_B5_BIGBOOT.hex
16000000L	UART0		B5		2		Yes		No		250000		250000		0.0%	642 bytes	optiboot_flash_at90can128_UART0_250000_16000000L_B5_BIGBOOT.hex
16000000L	UART0		B5		2		Yes		No		115200		117647		2.1%	642 bytes	optiboot_flash_at90can128_UART0_115200_16000000L_B5_BIGBOOT.hex
16000000L	UART0		B5		2		Yes		No		38400		38461		0.1%	642 bytes	optiboot_flash_at90can128_UART0_38400_16000000L_B5_BIGBOOT.hex
16000000L	UART0		B5		2		Yes		No		19200		19230		0.1%	642 bytes	optiboot_flash_at90can128_UART0_19200_16000000L_B5_BIGBOOT.hex
16000000L	UART0		B5		2		Yes		No		9600		9615		0.1%	642 bytes	optiboot_flash_at90can128_UART0_9600_16000000L_B5_BIGBOOT.hex
14745600L	UART0		B5		2		Yes		No		460800		460800		0.0%	642 bytes	optiboot_flash_at90can128_UART0_460800_14745600L_B5_BIGBOOT.hex
14745600L	UART0		B5		2		Yes		No		230400		230400		0.0%	642 bytes	optiboot_flash_at90can128_UART0_230400_14745600L_B5_BIGBOOT.hex
14745600L	UART0		B5		2		Yes		No		115200		115200		0.0%	642 bytes	optiboot_flash_at90can128_UART0_115200_14745600L_B5_BIGBOOT.hex
14745600L	UART0		B5		2		Yes		No		57600		57600		0.0%	642 bytes	optiboot_flash_at90can128_UART0_57600_14745600L_B5_BIGBOOT.hex
14745600L	UART0		B5		2		Yes		No		38400		38400		0.0%	642 bytes	optiboot_flash_at90can128_UART0_38400_14745600L_B5_BIGBOOT.hex
14745600L	UART0		B5		2		Yes		No		19200		19200		0.0%	642 bytes	optiboot_flash_at90can128_UART0_19200_14745600L_B5_BIGBOOT.hex
14745600L	UART0		B5		2		Yes		No		9600		9600		0.0%	642 bytes	optiboot_flash_at90can128_UART0_9600_14745600L_B5_BIGBOOT.hex
12000000L	UART0		B5		2		Yes		No		500000		500000		0.0%	640 bytes	optiboot_flash_at90can128_UART0_500000_12000000L_B5_BIGBOOT.hex
12000000L	UART0		B5		2		Yes		No		250000		250000		0.0%	640 bytes	optiboot_flash_at90can128_UART0_250000_12000000L_B5_BIGBOOT.hex
12000000L	UART0		B5		2		Yes		No		57600		57692		0.1%	642 bytes	optiboot_flash_at90can128_UART0_57600_12000000L_B5_BIGBOOT.hex
12000000L	UART0		B5		2		Yes		No		19200		19230		0.1%	642 bytes	optiboot_flash_at90can128_UART0_19200_12000000L_B5_BIGBOOT.hex
12000000L	UART0		B5		2		Yes		No		9600		9615		0.1%	642 bytes	optiboot_flash_at90can128_UART0_9600_12000000L_B5_BIGBOOT.hex
11059200L	UART0		B5		2		Yes		No		460800		460800		0.0%	640 bytes	optiboot_flash_at90can128_UART0_460800_11059200L_B5_BIGBOOT.hex
11059200L	UART0		B5		2		Yes		No		230400		230400		0.0%	640 bytes	optiboot_flash_at90can128_UART0_230400_11059200L_B5_BIGBOOT.hex
11059200L	UART0		B5		2		Yes		No		115200		115200		0.0%	642 bytes	optiboot_flash_at90can128_UART0_115200_11059200L_B5_BIGBOOT.hex
11059200L	UART0		B5		2		Yes		No		57600		57600		0.0%	642 bytes	optiboot_flash_at90can128_UART0_57600_11059200L_B5_BIGBOOT.hex
11059200L	UART0		B5		2		Yes		No		38400		38400		0.0%	642 bytes	optiboot_flash_at90can128_UART0_38400_11059200L_B5_BIGBOOT.hex
11059200L	UART0		B5		2		Yes		No		19200		19200		0.0%	642 bytes	optiboot_flash_at90can128_UART0_19200_11059200L_B5_BIGBOOT.hex
11059200L	UART0		B5		2		Yes		No		9600		9600		0.0%	642 bytes	optiboot_flash_at90can128_UART0_9600_11059200L_B5_BIGBOOT.hex
8000000L	UART0		B5		2		Yes		No		1000000		1000000		0.0%	640 bytes	optiboot_flash_at90can128_UART0_1000000_8000000L_B5_BIGBOOT.hex
8000000L	UART0		B5		2		Yes		No		500000		500000		0.0%	642 bytes	optiboot_flash_at90can128_UART0_500000_8000000L_B5_BIGBOOT.hex
8000000L	UART0		B5		2		Yes		No		250000		250000		0.0%	642 bytes	optiboot_flash_at90can128_UART0_250000_8000000L_B5_BIGBOOT.hex
8000000L	UART0		B5		2		Yes		No		115200		111111		-3.5%	642 bytes	optiboot_flash_at90can128_UART0_115200_8000000L_B5_BIGBOOT.hex
8000000L	UART0		B5		2		Yes		No		57600		58823		2.1%	642 bytes	optiboot_flash_at90can128_UART0_57600_8000000L_B5_BIGBOOT.hex
8000000L	UART0		B5		2		Yes		No		38400		38461		0.1%	642 bytes	optiboot_flash_at90can128_UART0_38400_8000000L_B5_BIGBOOT.hex
8000000L	UART0		B5		2		Yes		No		19200		19230		0.1%	642 bytes	optiboot_flash_at90can128_UART0_19200_8000000L_B5_BIGBOOT.hex
8000000L	UART0		B5		2		Yes		No		9600		9615		0.1%	642 bytes	optiboot_flash_at90can128_UART0_9600_8000000L_B5_BIGBOOT.hex
7372800L	UART0		B5		2		Yes		No		460800		460800		0.0%	642 bytes	optiboot_flash_at90can128_UART0_460800_7372800L_B5_BIGBOOT.hex
7372800L	UART0		B5		2		Yes		No		230400		230400		0.0%	642 bytes	optiboot_flash_at90can128_UART0_230400_7372800L_B5_BIGBOOT.hex
7372800L	UART0		B5		2		Yes		No		115200		115200		0.0%	642 bytes	optiboot_flash_at90can128_UART0_115200_7372800L_B5_BIGBOOT.hex
7372800L	UART0		B5		2		Yes		No		57600		57600		0.0%	642 bytes	optiboot_flash_at90can128_UART0_57600_7372800L_B5_BIGBOOT.hex
7372800L	UART0		B5		2		Yes		No		38400		38400		0.0%	642 bytes	optiboot_flash_at90can128_UART0_38400_7372800L_B5_BIGBOOT.hex
7372800L	UART0		B5		2		Yes		No		19200		19200		0.0%	642 bytes	optiboot_flash_at90can128_UART0_19200_7372800L_B5_BIGBOOT.hex
7372800L	UART0		B5		2		Yes		No		9600		9600		0.0%	642 bytes	optiboot_flash_at90can128_UART0_9600_7372800L_B5_BIGBOOT.hex
4000000L	UART0		B5		2		Yes		No		500000		500000		0.0%	640 bytes	optiboot_flash_at90can128_UART0_500000_4000000L_B5_BIGBOOT.hex
4000000L	UART0		B5		2		Yes		No		250000		250000		0.0%	642 bytes	optiboot_flash_at90can128_UART0_250000_4000000L_B5_BIGBOOT.hex
4000000L	UART0		B5		2		Yes		No		19200		19230		0.1%	642 bytes	optiboot_flash_at90can128_UART0_19200_4000000L_B5_BIGBOOT.hex
4000000L	UART0		B5		2		Yes		No		9600		9615		0.1%	642 bytes	optiboot_flash_at90can128_UART0_9600_4000000L_B5_BIGBOOT.hex
3686400L	UART0		B5		2		Yes		No		460800		460800		0.0%	640 bytes	optiboot_flash_at90can128_UART0_460800_3686400L_B5_BIGBOOT.hex
3686400L	UART0		B5		2		Yes		No		230400		230400		0.0%	642 bytes	optiboot_flash_at90can128_UART0_230400_3686400L_B5_BIGBOOT.hex
3686400L	UART0		B5		2		Yes		No		115200		115200		0.0%	642 bytes	optiboot_flash_at90can128_UART0_115200_3686400L_B5_BIGBOOT.hex
3686400L	UART0		B5		2		Yes		No		57600		57600		0.0%	642 bytes	optiboot_flash_at90can128_UART0_57600_3686400L_B5_BIGBOOT.hex
3686400L	UART0		B5		2		Yes		No		38400		38400		0.0%	642 bytes	optiboot_flash_at90can128_UART0_38400_3686400L_B5_BIGBOOT.hex
3686400L	UART0		B5		2		Yes		No		19200		19200		0.0%	642 bytes	optiboot_flash_at90can128_UART0_19200_3686400L_B5_BIGBOOT.hex
3686400L	UART0		B5		2		Yes		No		9600		9600		0.0%	642 bytes	optiboot_flash_at90can128_UART0_9600_3686400L_B5_BIGBOOT.hex
2000000L	UART0		B5		2		Yes		No		250000		250000		0.0%	640 bytes	optiboot_flash_at90can128_UART0_250000_2000000L_B5_BIGBOOT.hex
2000000L	UART0		B5		2		Yes		No		19200		19230		0.1%	642 bytes	optiboot_flash_at90can128_UART0_19200_2000000L_B5_BIGBOOT.hex
2000000L	UART0		B5		2		Yes		No		9600		9615		0.1%	642 bytes	optiboot_flash_at90can128_UART0_9600_2000000L_B5_BIGBOOT.hex
1843200L	UART0		B5		2		Yes		No		230400		230400		0.0%	640 bytes	optiboot_flash_at90can128_UART0_230400_1843200L_B5_BIGBOOT.hex
1843200L	UART0		B5		2		Yes		No		115200		115200		0.0%	642 bytes	optiboot_flash_at90can128_UART0_115200_1843200L_B5_BIGBOOT.hex
1843200L	UART0		B5		2		Yes		No		57600		57600		0.0%	642 bytes	optiboot_flash_at90can128_UART0_57600_1843200L_B5_BIGBOOT.hex
1843200L	UART0		B5		2		Yes		No		38400		38400		0.0%	640 bytes	optiboot_flash_at90can128_UART0_38400_1843200L_B5_BIGBOOT.hex
1843200L	UART0		B5		2		Yes		No		19200		19200		0.0%	642 bytes	optiboot_flash_at90can128_UART0_19200_1843200L_B5_BIGBOOT.hex
1843200L	UART0		B5		2		Yes		No		9600		9600		0.0%	642 bytes	optiboot_flash_at90can128_UART0_9600_1843200L_B5_BIGBOOT.hex
1000000L	UART0		B5		2		Yes		No		9600		9615		0.1%	642 bytes	optiboot_flash_at90can128_UART0_9600_1000000L_B5_BIGBOOT.hex

Optiboot_flash build output for at90can128 
https://github.com/MCUdude/optiboot_flash 
Build date and time: 04.11.2019 19:40 
Compiler: avr-gcc 7.3.0
 
F_CPU:		UART NUMBER:	LED PIN:	LED FLASHES:	EEPROM SUPPORT:	FLASH PG COPY:	DESIRED BAUD:	ACTUAL BAUD:	ERROR:	COMPILED SIZE:	OUTPUT FILE:
24000000L	UART1		B5		2		Yes		No		1000000		1000000		0.0%	640 bytes	optiboot_flash_at90can128_UART1_1000000_24000000L_B5_BIGBOOT.hex
24000000L	UART1		B5		2		Yes		No		500000		500000		0.0%	640 bytes	optiboot_flash_at90can128_UART1_500000_24000000L_B5_BIGBOOT.hex
24000000L	UART1		B5		2		Yes		No		250000		250000		0.0%	642 bytes	optiboot_flash_at90can128_UART1_250000_24000000L_B5_BIGBOOT.hex
24000000L	UART1		B5		2		Yes		No		230400		230769		0.1%	642 bytes	optiboot_flash_at90can128_UART1_230400_24000000L_B5_BIGBOOT.hex
24000000L	UART1		B5		2		Yes		No		115200		115384		0.1%	642 bytes	optiboot_flash_at90can128_UART1_115200_24000000L_B5_BIGBOOT.hex
24000000L	UART1		B5		2		Yes		No		57600		57692		0.1%	642 bytes	optiboot_flash_at90can128_UART1_57600_24000000L_B5_BIGBOOT.hex
24000000L	UART1		B5		2		Yes		No		38400		38461		0.1%	642 bytes	optiboot_flash_at90can128_UART1_38400_24000000L_B5_BIGBOOT.hex
24000000L	UART1		B5		2		Yes		No		19200		19230		0.1%	642 bytes	optiboot_flash_at90can128_UART1_19200_24000000L_B5_BIGBOOT.hex
22118400L	UART1		B5		2		Yes		No		460800		460800		0.0%	640 bytes	optiboot_flash_at90can128_UART1_460800_22118400L_B5_BIGBOOT.hex
22118400L	UART1		B5		2		Yes		No		230400		230400		0.0%	642 bytes	optiboot_flash_at90can128_UART1_230400_22118400L_B5_BIGBOOT.hex
22118400L	UART1		B5		2		Yes		No		115200		115200		0.0%	642 bytes	optiboot_flash_at90can128_UART1_115200_22118400L_B5_BIGBOOT.hex
22118400L	UART1		B5		2		Yes		No		57600		57600		0.0%	642 bytes	optiboot_flash_at90can128_UART1_57600_22118400L_B5_BIGBOOT.hex
22118400L	UART1		B5		2		Yes		No		38400		38400		0.0%	642 bytes	optiboot_flash_at90can128_UART1_38400_22118400L_B5_BIGBOOT.hex
22118400L	UART1		B5		2		Yes		No		19200		19200		0.0%	642 bytes	optiboot_flash_at90can128_UART1_19200_22118400L_B5_BIGBOOT.hex
20000000L	UART1		B5		2		Yes		No		500000		500000		0.0%	642 bytes	optiboot_flash_at90can128_UART1_500000_20000000L_B5_BIGBOOT.hex
20000000L	UART1		B5		2		Yes		No		250000		250000		0.0%	642 bytes	optiboot_flash_at90can128_UART1_250000_20000000L_B5_BIGBOOT.hex
20000000L	UART1		B5		2		Yes		No		115200		113636		-1.3%	642 bytes	optiboot_flash_at90can128_UART1_115200_20000000L_B5_BIGBOOT.hex
20000000L	UART1		B5		2		Yes		No		19200		19230		0.1%	642 bytes	optiboot_flash_at90can128_UART1_19200_20000000L_B5_BIGBOOT.hex
18432000L	UART1		B5		2		Yes		No		460800		460800		0.0%	642 bytes	optiboot_flash_at90can128_UART1_460800_18432000L_B5_BIGBOOT.hex
18432000L	UART1		B5		2		Yes		No		230400		230400		0.0%	642 bytes	optiboot_flash_at90can128_UART1_230400_18432000L_B5_BIGBOOT.hex
18432000L	UART1		B5		2		Yes		No		115200		115200		0.0%	642 bytes	optiboot_flash_at90can128_UART1_115200_18432000L_B5_BIGBOOT.hex
18432000L	UART1		B5		2		Yes		No		57600		57600		0.0%	642 bytes	optiboot_flash_at90can128_UART1_57600_18432000L_B5_BIGBOOT.hex
18432000L	UART1		B5		2		Yes		No		38400		38400		0.0%	642 bytes	optiboot_flash_at90can128_UART1_38400_18432000L_B5_BIGBOOT.hex
18432000L	UART1		B5		2		Yes		No		19200		19200		0.0%	642 bytes	optiboot_flash_at90can128_UART1_19200_18432000L_B5_BIGBOOT.hex
18432000L	UART1		B5		2		Yes		No		9600		9600		0.0%	642 bytes	optiboot_flash_at90can128_UART1_9600_18432000L_B5_BIGBOOT.hex
16000000L	UART1		B5		2		Yes		No		1000000		1000000		0.0%	642 bytes	optiboot_flash_at90can128_UART1_1000000_16000000L_B5_BIGBOOT.hex
16000000L	UART1		B5		2		Yes		No		500000		500000		0.0%	642 bytes	optiboot_flash_at90can128_UART1_500000_16000000L_B5_BIGBOOT.hex
16000000L	UART1		B5		2		Yes		No		250000		250000		0.0%	642 bytes	optiboot_flash_at90can128_UART1_250000_16000000L_B5_BIGBOOT.hex
16000000L	UART1		B5		2		Yes		No		115200		117647		2.1%	642 bytes	optiboot_flash_at90can128_UART1_115200_16000000L_B5_BIGBOOT.hex
16000000L	UART1		B5		2		Yes		No		38400		38461		0.1%	642 bytes	optiboot_flash_at90can128_UART1_38400_16000000L_B5_BIGBOOT.hex
16000000L	UART1		B5		2		Yes		No		19200		19230		0.1%	642 bytes	optiboot_flash_at90can128_UART1_19200_16000000L_B5_BIGBOOT.hex
16000000L	UART1		B5		2		Yes		No		9600		9615		0.1%	642 bytes	optiboot_flash_at90can128_UART1_9600_16000000L_B5_BIGBOOT.hex
14745600L	UART1		B5		2		Yes		No		460800		460800		0.0%	642 bytes	optiboot_flash_at90can128_UART1_460800_14745600L_B5_BIGBOOT.hex
14745600L	UART1		B5		2		Yes		No		230400		230400		0.0%	642 bytes	optiboot_flash_at90can128_UART1_230400_14745600L_B5_BIGBOOT.hex
14745600L	UART1		B5		2		Yes		No		115200		115200		0.0%	642 bytes	optiboot_flash_at90can128_UART1_115200_14745600L_B5_BIGBOOT.hex
14745600L	UART1		B5		2		Yes		No		57600		57600		0.0%	642 bytes	optiboot_flash_at90can128_UART1_57600_14745600L_B5_BIGBOOT.hex
14745600L	UART1		B5		2		Yes		No		38400		38400		0.0%	642 bytes	optiboot_flash_at90can128_UART1_38400_14745600L_B5_BIGBOOT.hex
14745600L	UART1		B5		2		Yes		No		19200		19200		0.0%	642 bytes	optiboot_flash_at90can128_UART1_19200_14745600L_B5_BIGBOOT.hex
14745600L	UART1		B5		2		Yes		No		9600		9600		0.0%	642 bytes	optiboot_flash_at90can128_UART1_9600_14745600L_B5_BIGBOOT.hex
12000000L	UART1		B5		2		Yes		No		500000		500000		0.0%	640 bytes	optiboot_flash_at90can128_UART1_500000_12000000L_B5_BIGBOOT.hex
12000000L	UART1		B5		2		Yes		No		250000		250000		0.0%	640 bytes	optiboot_flash_at90can128_UART1_250000_12000000L_B5_BIGBOOT.hex
12000000L	UART1		B5		2		Yes		No		57600		57692		0.1%	642 bytes	optiboot_flash_at90can128_UART1_57600_12000000L_B5_BIGBOOT.hex
12000000L	UART1		B5		2		Yes		No		19200		19230		0.1%	642 bytes	optiboot_flash_at90can128_UART1_19200_12000000L_B5_BIGBOOT.hex
12000000L	UART1		B5		2		Yes		No		9600		9615		0.1%	642 bytes	optiboot_flash_at90can128_UART1_9600_12000000L_B5_BIGBOOT.hex
11059200L	UART1		B5		2		Yes		No		460800		460800		0.0%	640 bytes	optiboot_flash_at90can128_UART1_460800_11059200L_B5_BIGBOOT.hex
11059200L	UART1		B5		2		Yes		No		230400		230400		0.0%	640 bytes	optiboot_flash_at90can128_UART1_230400_11059200L_B5_BIGBOOT.hex
11059200L	UART1		B5		2		Yes		No		115200		115200		0.0%	642 bytes	optiboot_flash_at90can128_UART1_115200_11059200L_B5_BIGBOOT.hex
11059200L	UART1		B5		2		Yes		No		57600		57600		0.0%	642 bytes	optiboot_flash_at90can128_UART1_57600_11059200L_B5_BIGBOOT.hex
11059200L	UART1		B5		2		Yes		No		38400		38400		0.0%	642 bytes	optiboot_flash_at90can128_UART1_38400_11059200L_B5_BIGBOOT.hex
11059200L	UART1		B5		2		Yes		No		19200		19200		0.0%	642 bytes	optiboot_flash_at90can128_UART1_19200_11059200L_B5_BIGBOOT.hex
11059200L	UART1		B5		2		Yes		No		9600		9600		0.0%	642 bytes	optiboot_flash_at90can128_UART1_9600_11059200L_B5_BIGBOOT.hex
8000000L	UART1		B5		2		Yes		No		1000000		1000000		0.0%	640 bytes	optiboot_flash_at90can128_UART1_1000000_8000000L_B5_BIGBOOT.hex
8000000L	UART1		B5		2		Yes		No		500000		500000		0.0%	642 bytes	optiboot_flash_at90can128_UART1_500000_8000000L_B5_BIGBOOT.hex
8000000L	UART1		B5		2		Yes		No		250000		250000		0.0%	642 bytes	optiboot_flash_at90can128_UART1_250000_8000000L_B5_BIGBOOT.hex
8000000L	UART1		B5		2		Yes		No		115200		111111		-3.5%	642 bytes	optiboot_flash_at90can128_UART1_115200_8000000L_B5_BIGBOOT.hex
8000000L	UART1		B5		2		Yes		No		57600		58823		2.1%	642 bytes	optiboot_flash_at90can128_UART1_57600_8000000L_B5_BIGBOOT.hex
8000000L	UART1		B5		2		Yes		No		38400		38461		0.1%	642 bytes	optiboot_flash_at90can128_UART1_38400_8000000L_B5_BIGBOOT.hex
8000000L	UART1		B5		2		Yes		No		19200		19230		0.1%	642 bytes	optiboot_flash_at90can128_UART1_19200_8000000L_B5_BIGBOOT.hex
8000000L	UART1		B5		2		Yes		No		9600		9615		0.1%	642 bytes	optiboot_flash_at90can128_UART1_9600_8000000L_B5_BIGBOOT.hex
7372800L	UART1		B5		2		Yes		No		460800		460800		0.0%	642 bytes	optiboot_flash_at90can128_UART1_460800_7372800L_B5_BIGBOOT.hex
7372800L	UART1		B5		2		Yes		No		230400		230400		0.0%	642 bytes	optiboot_flash_at90can128_UART1_230400_7372800L_B5_BIGBOOT.hex
7372800L	UART1		B5		2		Yes		No		115200		115200		0.0%	642 bytes	optiboot_flash_at90can128_UART1_115200_7372800L_B5_BIGBOOT.hex
7372800L	UART1		B5		2		Yes		No		57600		57600		0.0%	642 bytes	optiboot_flash_at90can128_UART1_57600_7372800L_B5_BIGBOOT.hex
7372800L	UART1		B5		2		Yes		No		38400		38400		0.0%	642 bytes	optiboot_flash_at90can128_UART1_38400_7372800L_B5_BIGBOOT.hex
7372800L	UART1		B5		2		Yes		No		19200		19200		0.0%	642 bytes	optiboot_flash_at90can128_UART1_19200_7372800L_B5_BIGBOOT.hex
7372800L	UART1		B5		2		Yes		No		9600		9600		0.0%	642 bytes	optiboot_flash_at90can128_UART1_9600_7372800L_B5_BIGBOOT.hex
4000000L	UART1		B5		2		Yes		No		500000		500000		0.0%	640 bytes	optiboot_flash_at90can128_UART1_500000_4000000L_B5_BIGBOOT.hex
4000000L	UART1		B5		2		Yes		No		250000		250000		0.0%	642 bytes	optiboot_flash_at90can128_UART1_250000_4000000L_B5_BIGBOOT.hex
4000000L	UART1		B5		2		Yes		No		19200		19230		0.1%	642 bytes	optiboot_flash_at90can128_UART1_19200_4000000L_B5_BIGBOOT.hex
4000000L	UART1		B5		2		Yes		No		9600		9615		0.1%	642 bytes	optiboot_flash_at90can128_UART1_9600_4000000L_B5_BIGBOOT.hex
3686400L	UART1		B5		2		Yes		No		460800		460800		0.0%	640 bytes	optiboot_flash_at90can128_UART1_460800_3686400L_B5_BIGBOOT.hex
3686400L	UART1		B5		2		Yes		No		230400		230400		0.0%	642 bytes	optiboot_flash_at90can128_UART1_230400_3686400L_B5_BIGBOOT.hex
3686400L	UART1		B5		2		Yes		No		115200		115200		0.0%	642 bytes	optiboot_flash_at90can128_UART1_115200_3686400L_B5_BIGBOOT.hex
3686400L	UART1		B5		2		Yes		No		57600		57600		0.0%	642 bytes	optiboot_flash_at90can128_UART1_57600_3686400L_B5_BIGBOOT.hex
3686400L	UART1		B5		2		Yes		No		38400		38400		0.0%	642 bytes	optiboot_flash_at90can128_UART1_38400_3686400L_B5_BIGBOOT.hex
3686400L	UART1		B5		2		Yes		No		19200		19200		0.0%	642 bytes	optiboot_flash_at90can128_UART1_19200_3686400L_B5_BIGBOOT.hex
3686400L	UART1		B5		2		Yes		No		9600		9600		0.0%	642 bytes	optiboot_flash_at90can128_UART1_9600_3686400L_B5_BIGBOOT.hex
2000000L	UART1		B5		2		Yes		No		250000		250000		0.0%	640 bytes	optiboot_flash_at90can128_UART1_250000_2000000L_B5_BIGBOOT.hex
2000000L	UART1		B5		2		Yes		No		19200		19230		0.1%	642 bytes	optiboot_flash_at90can128_UART1_19200_2000000L_B5_BIGBOOT.hex
2000000L	UART1		B5		2		Yes		No		9600		9615		0.1%	642 bytes	optiboot_flash_at90can128_UART1_9600_2000000L_B5_BIGBOOT.hex
1843200L	UART1		B5		2		Yes		No		230400		230400		0.0%	640 bytes	optiboot_flash_at90can128_UART1_230400_1843200L_B5_BIGBOOT.hex
1843200L	UART1		B5		2		Yes		No		115200		115200		0.0%	642 bytes	optiboot_flash_at90can128_UART1_115200_1843200L_B5_BIGBOOT.hex
1843200L	UART1		B5		2		Yes		No		57600		57600		0.0%	642 bytes	optiboot_flash_at90can128_UART1_57600_1843200L_B5_BIGBOOT.hex
1843200L	UART1		B5		2		Yes		No		38400		38400		0.0%	640 bytes	optiboot_flash_at90can128_UART1_38400_1843200L_B5_BIGBOOT.hex
1843200L	UART1		B5		2		Yes		No		19200		19200		0.0%	642 bytes	optiboot_flash_at90can128_UART1_19200_1843200L_B5_BIGBOOT.hex
1843200L	UART1		B5		2		Yes		No		9600		9600		0.0%	642 bytes	optiboot_flash_at90can128_UART1_9600_1843200L_B5_BIGBOOT.hex
1000000L	UART1		B5		2		Yes		No		9600		9615		0.1%	642 bytes	optiboot_flash_at90can128_UART1_9600_1000000L_B5_BIGBOOT.hex

Optiboot_flash build output for at90can128 
https://github.com/MCUdude/optiboot_flash 
Build date and time: 09.11.2019 21:25 
Compiler: avr-gcc 7.3.0
 
F_CPU:		UART NUMBER:	LED PIN:	LED FLASHES:	EEPROM SUPPORT:	FLASH PG COPY:	DESIRED BAUD:	ACTUAL BAUD:	ERROR:	COMPILED SIZE:	OUTPUT FILE:
12000000L	UART0		B5		2		Yes		No		115200		115384		0.1%	642 bytes	optiboot_flash_at90can128_UART0_115200_12000000L_B5_BIGBOOT.hex

Optiboot_flash build output for at90can128 
https://github.com/MCUdude/optiboot_flash 
Build date and time: 09.11.2019 21:25 
Compiler: avr-gcc 7.3.0
 
F_CPU:		UART NUMBER:	LED PIN:	LED FLASHES:	EEPROM SUPPORT:	FLASH PG COPY:	DESIRED BAUD:	ACTUAL BAUD:	ERROR:	COMPILED SIZE:	OUTPUT FILE:
12000000L	UART1		B5		2		Yes		No		115200		115384		0.1%	642 bytes	optiboot_flash_at90can128_UART1_115200_12000000L_B5_BIGBOOT.hex

Optiboot_flash build output for at90can128 
https://github.com/MCUdude/optiboot_flash 
Build date and time: 11.04.2020 15:36 
Compiler: avr-gcc 7.3.0
 
F_CPU:		UART NUMBER:	LED PIN:	LED FLASHES:	EEPROM SUPPORT:	FLASH PG COPY:	DESIRED BAUD:	ACTUAL BAUD:	ERROR:	COMPILED SIZE:	OUTPUT FILE:
24000000L	UART0		B5		2		Yes		No		1000000		1000000		0.0%	650 bytes	optiboot_flash_at90can128_UART0_1000000_24000000L_B5_BIGBOOT.hex
24000000L	UART0		B5		2		Yes		No		500000		500000		0.0%	650 bytes	optiboot_flash_at90can128_UART0_500000_24000000L_B5_BIGBOOT.hex
24000000L	UART0		B5		2		Yes		No		250000		250000		0.0%	652 bytes	optiboot_flash_at90can128_UART0_250000_24000000L_B5_BIGBOOT.hex
24000000L	UART0		B5		2		Yes		No		230400		230769		0.1%	652 bytes	optiboot_flash_at90can128_UART0_230400_24000000L_B5_BIGBOOT.hex
24000000L	UART0		B5		2		Yes		No		115200		115384		0.1%	652 bytes	optiboot_flash_at90can128_UART0_115200_24000000L_B5_BIGBOOT.hex
24000000L	UART0		B5		2		Yes		No		57600		57692		0.1%	652 bytes	optiboot_flash_at90can128_UART0_57600_24000000L_B5_BIGBOOT.hex
24000000L	UART0		B5		2		Yes		No		38400		38461		0.1%	652 bytes	optiboot_flash_at90can128_UART0_38400_24000000L_B5_BIGBOOT.hex
24000000L	UART0		B5		2		Yes		No		19200		19230		0.1%	652 bytes	optiboot_flash_at90can128_UART0_19200_24000000L_B5_BIGBOOT.hex
22118400L	UART0		B5		2		Yes		No		460800		460800		0.0%	650 bytes	optiboot_flash_at90can128_UART0_460800_22118400L_B5_BIGBOOT.hex
22118400L	UART0		B5		2		Yes		No		230400		230400		0.0%	652 bytes	optiboot_flash_at90can128_UART0_230400_22118400L_B5_BIGBOOT.hex
22118400L	UART0		B5		2		Yes		No		115200		115200		0.0%	652 bytes	optiboot_flash_at90can128_UART0_115200_22118400L_B5_BIGBOOT.hex
22118400L	UART0		B5		2		Yes		No		57600		57600		0.0%	652 bytes	optiboot_flash_at90can128_UART0_57600_22118400L_B5_BIGBOOT.hex
22118400L	UART0		B5		2		Yes		No		38400		38400		0.0%	652 bytes	optiboot_flash_at90can128_UART0_38400_22118400L_B5_BIGBOOT.hex
22118400L	UART0		B5		2		Yes		No		19200		19200		0.0%	652 bytes	optiboot_flash_at90can128_UART0_19200_22118400L_B5_BIGBOOT.hex
20000000L	UART0		B5		2		Yes		No		500000		500000		0.0%	652 bytes	optiboot_flash_at90can128_UART0_500000_20000000L_B5_BIGBOOT.hex
20000000L	UART0		B5		2		Yes		No		250000		250000		0.0%	652 bytes	optiboot_flash_at90can128_UART0_250000_20000000L_B5_BIGBOOT.hex
20000000L	UART0		B5		2		Yes		No		115200		113636		-1.3%	652 bytes	optiboot_flash_at90can128_UART0_115200_20000000L_B5_BIGBOOT.hex
20000000L	UART0		B5		2		Yes		No		19200		19230		0.1%	652 bytes	optiboot_flash_at90can128_UART0_19200_20000000L_B5_BIGBOOT.hex
18432000L	UART0		B5		2		Yes		No		460800		460800		0.0%	652 bytes	optiboot_flash_at90can128_UART0_460800_18432000L_B5_BIGBOOT.hex
18432000L	UART0		B5		2		Yes		No		230400		230400		0.0%	652 bytes	optiboot_flash_at90can128_UART0_230400_18432000L_B5_BIGBOOT.hex
18432000L	UART0		B5		2		Yes		No		115200		115200		0.0%	652 bytes	optiboot_flash_at90can128_UART0_115200_18432000L_B5_BIGBOOT.hex
18432000L	UART0		B5		2		Yes		No		57600		57600		0.0%	652 bytes	optiboot_flash_at90can128_UART0_57600_18432000L_B5_BIGBOOT.hex
18432000L	UART0		B5		2		Yes		No		38400		38400		0.0%	652 bytes	optiboot_flash_at90can128_UART0_38400_18432000L_B5_BIGBOOT.hex
18432000L	UART0		B5		2		Yes		No		19200		19200		0.0%	652 bytes	optiboot_flash_at90can128_UART0_19200_18432000L_B5_BIGBOOT.hex
18432000L	UART0		B5		2		Yes		No		9600		9600		0.0%	652 bytes	optiboot_flash_at90can128_UART0_9600_18432000L_B5_BIGBOOT.hex
16000000L	UART0		B5		2		Yes		No		1000000		1000000		0.0%	652 bytes	optiboot_flash_at90can128_UART0_1000000_16000000L_B5_BIGBOOT.hex
16000000L	UART0		B5		2		Yes		No		500000		500000		0.0%	652 bytes	optiboot_flash_at90can128_UART0_500000_16000000L_B5_BIGBOOT.hex
16000000L	UART0		B5		2		Yes		No		250000		250000		0.0%	652 bytes	optiboot_flash_at90can128_UART0_250000_16000000L_B5_BIGBOOT.hex
16000000L	UART0		B5		2		Yes		No		115200		117647		2.1%	652 bytes	optiboot_flash_at90can128_UART0_115200_16000000L_B5_BIGBOOT.hex
16000000L	UART0		B5		2		Yes		No		38400		38461		0.1%	652 bytes	optiboot_flash_at90can128_UART0_38400_16000000L_B5_BIGBOOT.hex
16000000L	UART0		B5		2		Yes		No		19200		19230		0.1%	652 bytes	optiboot_flash_at90can128_UART0_19200_16000000L_B5_BIGBOOT.hex
16000000L	UART0		B5		2		Yes		No		9600		9615		0.1%	652 bytes	optiboot_flash_at90can128_UART0_9600_16000000L_B5_BIGBOOT.hex
14745600L	UART0		B5		2		Yes		No		460800		460800		0.0%	652 bytes	optiboot_flash_at90can128_UART0_460800_14745600L_B5_BIGBOOT.hex
14745600L	UART0		B5		2		Yes		No		230400		230400		0.0%	652 bytes	optiboot_flash_at90can128_UART0_230400_14745600L_B5_BIGBOOT.hex
14745600L	UART0		B5		2		Yes		No		115200		115200		0.0%	652 bytes	optiboot_flash_at90can128_UART0_115200_14745600L_B5_BIGBOOT.hex
14745600L	UART0		B5		2		Yes		No		57600		57600		0.0%	652 bytes	optiboot_flash_at90can128_UART0_57600_14745600L_B5_BIGBOOT.hex
14745600L	UART0		B5		2		Yes		No		38400		38400		0.0%	652 bytes	optiboot_flash_at90can128_UART0_38400_14745600L_B5_BIGBOOT.hex
14745600L	UART0		B5		2		Yes		No		19200		19200		0.0%	652 bytes	optiboot_flash_at90can128_UART0_19200_14745600L_B5_BIGBOOT.hex
14745600L	UART0		B5		2		Yes		No		9600		9600		0.0%	652 bytes	optiboot_flash_at90can128_UART0_9600_14745600L_B5_BIGBOOT.hex
12000000L	UART0		B5		2		Yes		No		500000		500000		0.0%	650 bytes	optiboot_flash_at90can128_UART0_500000_12000000L_B5_BIGBOOT.hex
12000000L	UART0		B5		2		Yes		No		250000		250000		0.0%	650 bytes	optiboot_flash_at90can128_UART0_250000_12000000L_B5_BIGBOOT.hex
12000000L	UART0		B5		2		Yes		No		115200		115384		0.1%	652 bytes	optiboot_flash_at90can128_UART0_115200_12000000L_B5_BIGBOOT.hex
12000000L	UART0		B5		2		Yes		No		57600		57692		0.1%	652 bytes	optiboot_flash_at90can128_UART0_57600_12000000L_B5_BIGBOOT.hex
12000000L	UART0		B5		2		Yes		No		19200		19230		0.1%	652 bytes	optiboot_flash_at90can128_UART0_19200_12000000L_B5_BIGBOOT.hex
12000000L	UART0		B5		2		Yes		No		9600		9615		0.1%	652 bytes	optiboot_flash_at90can128_UART0_9600_12000000L_B5_BIGBOOT.hex
11059200L	UART0		B5		2		Yes		No		460800		460800		0.0%	650 bytes	optiboot_flash_at90can128_UART0_460800_11059200L_B5_BIGBOOT.hex
11059200L	UART0		B5		2		Yes		No		230400		230400		0.0%	650 bytes	optiboot_flash_at90can128_UART0_230400_11059200L_B5_BIGBOOT.hex
11059200L	UART0		B5		2		Yes		No		115200		115200		0.0%	652 bytes	optiboot_flash_at90can128_UART0_115200_11059200L_B5_BIGBOOT.hex
11059200L	UART0		B5		2		Yes		No		57600		57600		0.0%	652 bytes	optiboot_flash_at90can128_UART0_57600_11059200L_B5_BIGBOOT.hex
11059200L	UART0		B5		2		Yes		No		38400		38400		0.0%	652 bytes	optiboot_flash_at90can128_UART0_38400_11059200L_B5_BIGBOOT.hex
11059200L	UART0		B5		2		Yes		No		19200		19200		0.0%	652 bytes	optiboot_flash_at90can128_UART0_19200_11059200L_B5_BIGBOOT.hex
11059200L	UART0		B5		2		Yes		No		9600		9600		0.0%	652 bytes	optiboot_flash_at90can128_UART0_9600_11059200L_B5_BIGBOOT.hex
8000000L	UART0		B5		2		Yes		No		1000000		1000000		0.0%	650 bytes	optiboot_flash_at90can128_UART0_1000000_8000000L_B5_BIGBOOT.hex
8000000L	UART0		B5		2		Yes		No		500000		500000		0.0%	652 bytes	optiboot_flash_at90can128_UART0_500000_8000000L_B5_BIGBOOT.hex
8000000L	UART0		B5		2		Yes		No		250000		250000		0.0%	652 bytes	optiboot_flash_at90can128_UART0_250000_8000000L_B5_BIGBOOT.hex
8000000L	UART0		B5		2		Yes		No		115200		111111		-3.5%	652 bytes	optiboot_flash_at90can128_UART0_115200_8000000L_B5_BIGBOOT.hex
8000000L	UART0		B5		2		Yes		No		57600		58823		2.1%	652 bytes	optiboot_flash_at90can128_UART0_57600_8000000L_B5_BIGBOOT.hex
8000000L	UART0		B5		2		Yes		No		38400		38461		0.1%	652 bytes	optiboot_flash_at90can128_UART0_38400_8000000L_B5_BIGBOOT.hex
8000000L	UART0		B5		2		Yes		No		19200		19230		0.1%	652 bytes	optiboot_flash_at90can128_UART0_19200_8000000L_B5_BIGBOOT.hex
8000000L	UART0		B5		2		Yes		No		9600		9615		0.1%	652 bytes	optiboot_flash_at90can128_UART0_9600_8000000L_B5_BIGBOOT.hex
7372800L	UART0		B5		2		Yes		No		460800		460800		0.0%	652 bytes	optiboot_flash_at90can128_UART0_460800_7372800L_B5_BIGBOOT.hex
7372800L	UART0		B5		2		Yes		No		230400		230400		0.0%	652 bytes	optiboot_flash_at90can128_UART0_230400_7372800L_B5_BIGBOOT.hex
7372800L	UART0		B5		2		Yes		No		115200		115200		0.0%	652 bytes	optiboot_flash_at90can128_UART0_115200_7372800L_B5_BIGBOOT.hex
7372800L	UART0		B5		2		Yes		No		57600		57600		0.0%	652 bytes	optiboot_flash_at90can128_UART0_57600_7372800L_B5_BIGBOOT.hex
7372800L	UART0		B5		2		Yes		No		38400		38400		0.0%	652 bytes	optiboot_flash_at90can128_UART0_38400_7372800L_B5_BIGBOOT.hex
7372800L	UART0		B5		2		Yes		No		19200		19200		0.0%	652 bytes	optiboot_flash_at90can128_UART0_19200_7372800L_B5_BIGBOOT.hex
7372800L	UART0		B5		2		Yes		No		9600		9600		0.0%	652 bytes	optiboot_flash_at90can128_UART0_9600_7372800L_B5_BIGBOOT.hex
4000000L	UART0		B5		2		Yes		No		500000		500000		0.0%	650 bytes	optiboot_flash_at90can128_UART0_500000_4000000L_B5_BIGBOOT.hex
4000000L	UART0		B5		2		Yes		No		250000		250000		0.0%	652 bytes	optiboot_flash_at90can128_UART0_250000_4000000L_B5_BIGBOOT.hex
4000000L	UART0		B5		2		Yes		No		19200		19230		0.1%	652 bytes	optiboot_flash_at90can128_UART0_19200_4000000L_B5_BIGBOOT.hex
4000000L	UART0		B5		2		Yes		No		9600		9615		0.1%	652 bytes	optiboot_flash_at90can128_UART0_9600_4000000L_B5_BIGBOOT.hex
3686400L	UART0		B5		2		Yes		No		460800		460800		0.0%	650 bytes	optiboot_flash_at90can128_UART0_460800_3686400L_B5_BIGBOOT.hex
3686400L	UART0		B5		2		Yes		No		230400		230400		0.0%	652 bytes	optiboot_flash_at90can128_UART0_230400_3686400L_B5_BIGBOOT.hex
3686400L	UART0		B5		2		Yes		No		115200		115200		0.0%	652 bytes	optiboot_flash_at90can128_UART0_115200_3686400L_B5_BIGBOOT.hex
3686400L	UART0		B5		2		Yes		No		57600		57600		0.0%	652 bytes	optiboot_flash_at90can128_UART0_57600_3686400L_B5_BIGBOOT.hex
3686400L	UART0		B5		2		Yes		No		38400		38400		0.0%	652 bytes	optiboot_flash_at90can128_UART0_38400_3686400L_B5_BIGBOOT.hex
3686400L	UART0		B5		2		Yes		No		19200		19200		0.0%	652 bytes	optiboot_flash_at90can128_UART0_19200_3686400L_B5_BIGBOOT.hex
3686400L	UART0		B5		2		Yes		No		9600		9600		0.0%	652 bytes	optiboot_flash_at90can128_UART0_9600_3686400L_B5_BIGBOOT.hex
2000000L	UART0		B5		2		Yes		No		250000		250000		0.0%	650 bytes	optiboot_flash_at90can128_UART0_250000_2000000L_B5_BIGBOOT.hex
2000000L	UART0		B5		2		Yes		No		19200		19230		0.1%	652 bytes	optiboot_flash_at90can128_UART0_19200_2000000L_B5_BIGBOOT.hex
2000000L	UART0		B5		2		Yes		No		9600		9615		0.1%	652 bytes	optiboot_flash_at90can128_UART0_9600_2000000L_B5_BIGBOOT.hex
1843200L	UART0		B5		2		Yes		No		230400		230400		0.0%	650 bytes	optiboot_flash_at90can128_UART0_230400_1843200L_B5_BIGBOOT.hex
1843200L	UART0		B5		2		Yes		No		115200		115200		0.0%	652 bytes	optiboot_flash_at90can128_UART0_115200_1843200L_B5_BIGBOOT.hex
1843200L	UART0		B5		2		Yes		No		57600		57600		0.0%	652 bytes	optiboot_flash_at90can128_UART0_57600_1843200L_B5_BIGBOOT.hex
1843200L	UART0		B5		2		Yes		No		38400		38400		0.0%	650 bytes	optiboot_flash_at90can128_UART0_38400_1843200L_B5_BIGBOOT.hex
1843200L	UART0		B5		2		Yes		No		19200		19200		0.0%	652 bytes	optiboot_flash_at90can128_UART0_19200_1843200L_B5_BIGBOOT.hex
1843200L	UART0		B5		2		Yes		No		9600		9600		0.0%	652 bytes	optiboot_flash_at90can128_UART0_9600_1843200L_B5_BIGBOOT.hex
1000000L	UART0		B5		2		Yes		No		9600		9615		0.1%	652 bytes	optiboot_flash_at90can128_UART0_9600_1000000L_B5_BIGBOOT.hex

Optiboot_flash build output for at90can128 
https://github.com/MCUdude/optiboot_flash 
Build date and time: 11.04.2020 15:36 
Compiler: avr-gcc 7.3.0
 
F_CPU:		UART NUMBER:	LED PIN:	LED FLASHES:	EEPROM SUPPORT:	FLASH PG COPY:	DESIRED BAUD:	ACTUAL BAUD:	ERROR:	COMPILED SIZE:	OUTPUT FILE:
24000000L	UART1		B5		2		Yes		No		1000000		1000000		0.0%	650 bytes	optiboot_flash_at90can128_UART1_1000000_24000000L_B5_BIGBOOT.hex
24000000L	UART1		B5		2		Yes		No		500000		500000		0.0%	650 bytes	optiboot_flash_at90can128_UART1_500000_24000000L_B5_BIGBOOT.hex
24000000L	UART1		B5		2		Yes		No		250000		250000		0.0%	652 bytes	optiboot_flash_at90can128_UART1_250000_24000000L_B5_BIGBOOT.hex
24000000L	UART1		B5		2		Yes		No		230400		230769		0.1%	652 bytes	optiboot_flash_at90can128_UART1_230400_24000000L_B5_BIGBOOT.hex
24000000L	UART1		B5		2		Yes		No		115200		115384		0.1%	652 bytes	optiboot_flash_at90can128_UART1_115200_24000000L_B5_BIGBOOT.hex
24000000L	UART1		B5		2		Yes		No		57600		57692		0.1%	652 bytes	optiboot_flash_at90can128_UART1_57600_24000000L_B5_BIGBOOT.hex
24000000L	UART1		B5		2		Yes		No		38400		38461		0.1%	652 bytes	optiboot_flash_at90can128_UART1_38400_24000000L_B5_BIGBOOT.hex
24000000L	UART1		B5		2		Yes		No		19200		19230		0.1%	652 bytes	optiboot_flash_at90can128_UART1_19200_24000000L_B5_BIGBOOT.hex
22118400L	UART1		B5		2		Yes		No		460800		460800		0.0%	650 bytes	optiboot_flash_at90can128_UART1_460800_22118400L_B5_BIGBOOT.hex
22118400L	UART1		B5		2		Yes		No		230400		230400		0.0%	652 bytes	optiboot_flash_at90can128_UART1_230400_22118400L_B5_BIGBOOT.hex
22118400L	UART1		B5		2		Yes		No		115200		115200		0.0%	652 bytes	optiboot_flash_at90can128_UART1_115200_22118400L_B5_BIGBOOT.hex
22118400L	UART1		B5		2		Yes		No		57600		57600		0.0%	652 bytes	optiboot_flash_at90can128_UART1_57600_22118400L_B5_BIGBOOT.hex
22118400L	UART1		B5		2		Yes		No		38400		38400		0.0%	652 bytes	optiboot_flash_at90can128_UART1_38400_22118400L_B5_BIGBOOT.hex
22118400L	UART1		B5		2		Yes		No		19200		19200		0.0%	652 bytes	optiboot_flash_at90can128_UART1_19200_22118400L_B5_BIGBOOT.hex
20000000L	UART1		B5		2		Yes		No		500000		500000		0.0%	652 bytes	optiboot_flash_at90can128_UART1_500000_20000000L_B5_BIGBOOT.hex
20000000L	UART1		B5		2		Yes		No		250000		250000		0.0%	652 bytes	optiboot_flash_at90can128_UART1_250000_20000000L_B5_BIGBOOT.hex
20000000L	UART1		B5		2		Yes		No		115200		113636		-1.3%	652 bytes	optiboot_flash_at90can128_UART1_115200_20000000L_B5_BIGBOOT.hex
20000000L	UART1		B5		2		Yes		No		19200		19230		0.1%	652 bytes	optiboot_flash_at90can128_UART1_19200_20000000L_B5_BIGBOOT.hex
18432000L	UART1		B5		2		Yes		No		460800		460800		0.0%	652 bytes	optiboot_flash_at90can128_UART1_460800_18432000L_B5_BIGBOOT.hex
18432000L	UART1		B5		2		Yes		No		230400		230400		0.0%	652 bytes	optiboot_flash_at90can128_UART1_230400_18432000L_B5_BIGBOOT.hex
18432000L	UART1		B5		2		Yes		No		115200		115200		0.0%	652 bytes	optiboot_flash_at90can128_UART1_115200_18432000L_B5_BIGBOOT.hex
18432000L	UART1		B5		2		Yes		No		57600		57600		0.0%	652 bytes	optiboot_flash_at90can128_UART1_57600_18432000L_B5_BIGBOOT.hex
18432000L	UART1		B5		2		Yes		No		38400		38400		0.0%	652 bytes	optiboot_flash_at90can128_UART1_38400_18432000L_B5_BIGBOOT.hex
18432000L	UART1		B5		2		Yes		No		19200		19200		0.0%	652 bytes	optiboot_flash_at90can128_UART1_19200_18432000L_B5_BIGBOOT.hex
18432000L	UART1		B5		2		Yes		No		9600		9600		0.0%	652 bytes	optiboot_flash_at90can128_UART1_9600_18432000L_B5_BIGBOOT.hex
16000000L	UART1		B5		2		Yes		No		1000000		1000000		0.0%	652 bytes	optiboot_flash_at90can128_UART1_1000000_16000000L_B5_BIGBOOT.hex
16000000L	UART1		B5		2		Yes		No		500000		500000		0.0%	652 bytes	optiboot_flash_at90can128_UART1_500000_16000000L_B5_BIGBOOT.hex
16000000L	UART1		B5		2		Yes		No		250000		250000		0.0%	652 bytes	optiboot_flash_at90can128_UART1_250000_16000000L_B5_BIGBOOT.hex
16000000L	UART1		B5		2		Yes		No		115200		117647		2.1%	652 bytes	optiboot_flash_at90can128_UART1_115200_16000000L_B5_BIGBOOT.hex
16000000L	UART1		B5		2		Yes		No		38400		38461		0.1%	652 bytes	optiboot_flash_at90can128_UART1_38400_16000000L_B5_BIGBOOT.hex
16000000L	UART1		B5		2		Yes		No		19200		19230		0.1%	652 bytes	optiboot_flash_at90can128_UART1_19200_16000000L_B5_BIGBOOT.hex
16000000L	UART1		B5		2		Yes		No		9600		9615		0.1%	652 bytes	optiboot_flash_at90can128_UART1_9600_16000000L_B5_BIGBOOT.hex
14745600L	UART1		B5		2		Yes		No		460800		460800		0.0%	652 bytes	optiboot_flash_at90can128_UART1_460800_14745600L_B5_BIGBOOT.hex
14745600L	UART1		B5		2		Yes		No		230400		230400		0.0%	652 bytes	optiboot_flash_at90can128_UART1_230400_14745600L_B5_BIGBOOT.hex
14745600L	UART1		B5		2		Yes		No		115200		115200		0.0%	652 bytes	optiboot_flash_at90can128_UART1_115200_14745600L_B5_BIGBOOT.hex
14745600L	UART1		B5		2		Yes		No		57600		57600		0.0%	652 bytes	optiboot_flash_at90can128_UART1_57600_14745600L_B5_BIGBOOT.hex
14745600L	UART1		B5		2		Yes		No		38400		38400		0.0%	652 bytes	optiboot_flash_at90can128_UART1_38400_14745600L_B5_BIGBOOT.hex
14745600L	UART1		B5		2		Yes		No		19200		19200		0.0%	652 bytes	optiboot_flash_at90can128_UART1_19200_14745600L_B5_BIGBOOT.hex
14745600L	UART1		B5		2		Yes		No		9600		9600		0.0%	652 bytes	optiboot_flash_at90can128_UART1_9600_14745600L_B5_BIGBOOT.hex
12000000L	UART1		B5		2		Yes		No		500000		500000		0.0%	650 bytes	optiboot_flash_at90can128_UART1_500000_12000000L_B5_BIGBOOT.hex
12000000L	UART1		B5		2		Yes		No		250000		250000		0.0%	650 bytes	optiboot_flash_at90can128_UART1_250000_12000000L_B5_BIGBOOT.hex
12000000L	UART1		B5		2		Yes		No		115200		115384		0.1%	652 bytes	optiboot_flash_at90can128_UART1_115200_12000000L_B5_BIGBOOT.hex
12000000L	UART1		B5		2		Yes		No		57600		57692		0.1%	652 bytes	optiboot_flash_at90can128_UART1_57600_12000000L_B5_BIGBOOT.hex
12000000L	UART1		B5		2		Yes		No		19200		19230		0.1%	652 bytes	optiboot_flash_at90can128_UART1_19200_12000000L_B5_BIGBOOT.hex
12000000L	UART1		B5		2		Yes		No		9600		9615		0.1%	652 bytes	optiboot_flash_at90can128_UART1_9600_12000000L_B5_BIGBOOT.hex
11059200L	UART1		B5		2		Yes		No		460800		460800		0.0%	650 bytes	optiboot_flash_at90can128_UART1_460800_11059200L_B5_BIGBOOT.hex
11059200L	UART1		B5		2		Yes		No		230400		230400		0.0%	650 bytes	optiboot_flash_at90can128_UART1_230400_11059200L_B5_BIGBOOT.hex
11059200L	UART1		B5		2		Yes		No		115200		115200		0.0%	652 bytes	optiboot_flash_at90can128_UART1_115200_11059200L_B5_BIGBOOT.hex
11059200L	UART1		B5		2		Yes		No		57600		57600		0.0%	652 bytes	optiboot_flash_at90can128_UART1_57600_11059200L_B5_BIGBOOT.hex
11059200L	UART1		B5		2		Yes		No		38400		38400		0.0%	652 bytes	optiboot_flash_at90can128_UART1_38400_11059200L_B5_BIGBOOT.hex
11059200L	UART1		B5		2		Yes		No		19200		19200		0.0%	652 bytes	optiboot_flash_at90can128_UART1_19200_11059200L_B5_BIGBOOT.hex
11059200L	UART1		B5		2		Yes		No		9600		9600		0.0%	652 bytes	optiboot_flash_at90can128_UART1_9600_11059200L_B5_BIGBOOT.hex
8000000L	UART1		B5		2		Yes		No		1000000		1000000		0.0%	650 bytes	optiboot_flash_at90can128_UART1_1000000_8000000L_B5_BIGBOOT.hex
8000000L	UART1		B5		2		Yes		No		500000		500000		0.0%	652 bytes	optiboot_flash_at90can128_UART1_500000_8000000L_B5_BIGBOOT.hex
8000000L	UART1		B5		2		Yes		No		250000		250000		0.0%	652 bytes	optiboot_flash_at90can128_UART1_250000_8000000L_B5_BIGBOOT.hex
8000000L	UART1		B5		2		Yes		No		115200		111111		-3.5%	652 bytes	optiboot_flash_at90can128_UART1_115200_8000000L_B5_BIGBOOT.hex
8000000L	UART1		B5		2		Yes		No		57600		58823		2.1%	652 bytes	optiboot_flash_at90can128_UART1_57600_8000000L_B5_BIGBOOT.hex
8000000L	UART1		B5		2		Yes		No		38400		38461		0.1%	652 bytes	optiboot_flash_at90can128_UART1_38400_8000000L_B5_BIGBOOT.hex
8000000L	UART1		B5		2		Yes		No		19200		19230		0.1%	652 bytes	optiboot_flash_at90can128_UART1_19200_8000000L_B5_BIGBOOT.hex
8000000L	UART1		B5		2		Yes		No		9600		9615		0.1%	652 bytes	optiboot_flash_at90can128_UART1_9600_8000000L_B5_BIGBOOT.hex
7372800L	UART1		B5		2		Yes		No		460800		460800		0.0%	652 bytes	optiboot_flash_at90can128_UART1_460800_7372800L_B5_BIGBOOT.hex
7372800L	UART1		B5		2		Yes		No		230400		230400		0.0%	652 bytes	optiboot_flash_at90can128_UART1_230400_7372800L_B5_BIGBOOT.hex
7372800L	UART1		B5		2		Yes		No		115200		115200		0.0%	652 bytes	optiboot_flash_at90can128_UART1_115200_7372800L_B5_BIGBOOT.hex
7372800L	UART1		B5		2		Yes		No		57600		57600		0.0%	652 bytes	optiboot_flash_at90can128_UART1_57600_7372800L_B5_BIGBOOT.hex
7372800L	UART1		B5		2		Yes		No		38400		38400		0.0%	652 bytes	optiboot_flash_at90can128_UART1_38400_7372800L_B5_BIGBOOT.hex
7372800L	UART1		B5		2		Yes		No		19200		19200		0.0%	652 bytes	optiboot_flash_at90can128_UART1_19200_7372800L_B5_BIGBOOT.hex
7372800L	UART1		B5		2		Yes		No		9600		9600		0.0%	652 bytes	optiboot_flash_at90can128_UART1_9600_7372800L_B5_BIGBOOT.hex
4000000L	UART1		B5		2		Yes		No		500000		500000		0.0%	650 bytes	optiboot_flash_at90can128_UART1_500000_4000000L_B5_BIGBOOT.hex
4000000L	UART1		B5		2		Yes		No		250000		250000		0.0%	652 bytes	optiboot_flash_at90can128_UART1_250000_4000000L_B5_BIGBOOT.hex
4000000L	UART1		B5		2		Yes		No		19200		19230		0.1%	652 bytes	optiboot_flash_at90can128_UART1_19200_4000000L_B5_BIGBOOT.hex
4000000L	UART1		B5		2		Yes		No		9600		9615		0.1%	652 bytes	optiboot_flash_at90can128_UART1_9600_4000000L_B5_BIGBOOT.hex
3686400L	UART1		B5		2		Yes		No		460800		460800		0.0%	650 bytes	optiboot_flash_at90can128_UART1_460800_3686400L_B5_BIGBOOT.hex
3686400L	UART1		B5		2		Yes		No		230400		230400		0.0%	652 bytes	optiboot_flash_at90can128_UART1_230400_3686400L_B5_BIGBOOT.hex
3686400L	UART1		B5		2		Yes		No		115200		115200		0.0%	652 bytes	optiboot_flash_at90can128_UART1_115200_3686400L_B5_BIGBOOT.hex
3686400L	UART1		B5		2		Yes		No		57600		57600		0.0%	652 bytes	optiboot_flash_at90can128_UART1_57600_3686400L_B5_BIGBOOT.hex
3686400L	UART1		B5		2		Yes		No		38400		38400		0.0%	652 bytes	optiboot_flash_at90can128_UART1_38400_3686400L_B5_BIGBOOT.hex
3686400L	UART1		B5		2		Yes		No		19200		19200		0.0%	652 bytes	optiboot_flash_at90can128_UART1_19200_3686400L_B5_BIGBOOT.hex
3686400L	UART1		B5		2		Yes		No		9600		9600		0.0%	652 bytes	optiboot_flash_at90can128_UART1_9600_3686400L_B5_BIGBOOT.hex
2000000L	UART1		B5		2		Yes		No		250000		250000		0.0%	650 bytes	optiboot_flash_at90can128_UART1_250000_2000000L_B5_BIGBOOT.hex
2000000L	UART1		B5		2		Yes		No		19200		19230		0.1%	652 bytes	optiboot_flash_at90can128_UART1_19200_2000000L_B5_BIGBOOT.hex
2000000L	UART1		B5		2		Yes		No		9600		9615		0.1%	652 bytes	optiboot_flash_at90can128_UART1_9600_2000000L_B5_BIGBOOT.hex
1843200L	UART1		B5		2		Yes		No		230400		230400		0.0%	650 bytes	optiboot_flash_at90can128_UART1_230400_1843200L_B5_BIGBOOT.hex
1843200L	UART1		B5		2		Yes		No		115200		115200		0.0%	652 bytes	optiboot_flash_at90can128_UART1_115200_1843200L_B5_BIGBOOT.hex
1843200L	UART1		B5		2		Yes		No		57600		57600		0.0%	652 bytes	optiboot_flash_at90can128_UART1_57600_1843200L_B5_BIGBOOT.hex
1843200L	UART1		B5		2		Yes		No		38400		38400		0.0%	650 bytes	optiboot_flash_at90can128_UART1_38400_1843200L_B5_BIGBOOT.hex
1843200L	UART1		B5		2		Yes		No		19200		19200		0.0%	652 bytes	optiboot_flash_at90can128_UART1_19200_1843200L_B5_BIGBOOT.hex
1843200L	UART1		B5		2		Yes		No		9600		9600		0.0%	652 bytes	optiboot_flash_at90can128_UART1_9600_1843200L_B5_BIGBOOT.hex
1000000L	UART1		B5		2		Yes		No		9600		9615		0.1%	652 bytes	optiboot_flash_at90can128_UART1_9600_1000000L_B5_BIGBOOT.hex

Optiboot_flash build output for at90can128 
https://github.com/MCUdude/optiboot_flash 
Build date and time: 27.05.2020 07:53 
Compiler: avr-gcc 7.3.0
 
F_CPU:		UART NUMBER:	LED PIN:	LED FLASHES:	EEPROM SUPPORT:	FLASH PG COPY:	DESIRED BAUD:	ACTUAL BAUD:	ERROR:	COMPILED SIZE:	OUTPUT FILE:
1000000L	UART0		B5		2		Yes		No		9600		9615		0.1%	642 bytes	optiboot_flash_at90can128_UART0_9600_1000000L_B5_BIGBOOT.hex

Optiboot_flash build output for at90can128 
https://github.com/MCUdude/optiboot_flash 
Build date and time: 27.05.2020 07:53 
Compiler: avr-gcc 7.3.0
 
F_CPU:		UART NUMBER:	LED PIN:	LED FLASHES:	EEPROM SUPPORT:	FLASH PG COPY:	DESIRED BAUD:	ACTUAL BAUD:	ERROR:	COMPILED SIZE:	OUTPUT FILE:
1000000L	UART1		B5		2		Yes		No		9600		9615		0.1%	642 bytes	optiboot_flash_at90can128_UART1_9600_1000000L_B5_BIGBOOT.hex

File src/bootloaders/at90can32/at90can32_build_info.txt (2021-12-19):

Optiboot_flash build output for at90can32 
https://github.com/MCUdude/optiboot_flash 
Build date and time: 15.05.2019 23:28 
Compiler: avr-gcc 5.4.0
 
F_CPU:		UART NUMBER:	LED PIN:	LED FLASHES:	EEPROM SUPPORT:	FLASH PG COPY:	DESIRED BAUD:	ACTUAL BAUD:	ERROR:	COMPILED SIZE:	OUTPUT FILE:
24000000L	UART0		B0		2		Yes		No		1000000		1000000		0.0%	636 bytes	optiboot_flash_at90can32_UART0_1000000_24000000L_BIGBOOT.hex
24000000L	UART0		B0		2		Yes		No		500000		500000		0.0%	636 bytes	optiboot_flash_at90can32_UART0_500000_24000000L_BIGBOOT.hex
24000000L	UART0		B0		2		Yes		No		250000		250000		0.0%	638 bytes	optiboot_flash_at90can32_UART0_250000_24000000L_BIGBOOT.hex
24000000L	UART0		B0		2		Yes		No		230400		230769		0.1%	638 bytes	optiboot_flash_at90can32_UART0_230400_24000000L_BIGBOOT.hex
24000000L	UART0		B0		2		Yes		No		115200		115384		0.1%	638 bytes	optiboot_flash_at90can32_UART0_115200_24000000L_BIGBOOT.hex
24000000L	UART0		B0		2		Yes		No		57600		57692		0.1%	638 bytes	optiboot_flash_at90can32_UART0_57600_24000000L_BIGBOOT.hex
24000000L	UART0		B0		2		Yes		No		38400		38461		0.1%	638 bytes	optiboot_flash_at90can32_UART0_38400_24000000L_BIGBOOT.hex
24000000L	UART0		B0		2		Yes		No		19200		19230		0.1%	638 bytes	optiboot_flash_at90can32_UART0_19200_24000000L_BIGBOOT.hex
20000000L	UART0		B0		2		Yes		No		500000		500000		0.0%	638 bytes	optiboot_flash_at90can32_UART0_500000_20000000L_BIGBOOT.hex
20000000L	UART0		B0		2		Yes		No		250000		250000		0.0%	638 bytes	optiboot_flash_at90can32_UART0_250000_20000000L_BIGBOOT.hex
20000000L	UART0		B0		2		Yes		No		115200		113636		-1.3%	638 bytes	optiboot_flash_at90can32_UART0_115200_20000000L_BIGBOOT.hex
20000000L	UART0		B0		2		Yes		No		19200		19230		0.1%	638 bytes	optiboot_flash_at90can32_UART0_19200_20000000L_BIGBOOT.hex
18432000L	UART0		B0		2		Yes		No		230400		230400		0.0%	638 bytes	optiboot_flash_at90can32_UART0_230400_18432000L_BIGBOOT.hex
18432000L	UART0		B0		2		Yes		No		115200		115200		0.0%	638 bytes	optiboot_flash_at90can32_UART0_115200_18432000L_BIGBOOT.hex
18432000L	UART0		B0		2		Yes		No		57600		57600		0.0%	638 bytes	optiboot_flash_at90can32_UART0_57600_18432000L_BIGBOOT.hex
18432000L	UART0		B0		2		Yes		No		38400		38400		0.0%	638 bytes	optiboot_flash_at90can32_UART0_38400_18432000L_BIGBOOT.hex
18432000L	UART0		B0		2		Yes		No		19200		19200		0.0%	638 bytes	optiboot_flash_at90can32_UART0_19200_18432000L_BIGBOOT.hex
18432000L	UART0		B0		2		Yes		No		9600		9600		0.0%	638 bytes	optiboot_flash_at90can32_UART0_9600_18432000L_BIGBOOT.hex
16000000L	UART0		B0		2		Yes		No		1000000		1000000		0.0%	638 bytes	optiboot_flash_at90can32_UART0_1000000_16000000L_BIGBOOT.hex
16000000L	UART0		B0		2		Yes		No		500000		500000		0.0%	638 bytes	optiboot_flash_at90can32_UART0_500000_16000000L_BIGBOOT.hex
16000000L	UART0		B0		2		Yes		No		250000		250000		0.0%	638 bytes	optiboot_flash_at90can32_UART0_250000_16000000L_BIGBOOT.hex
16000000L	UART0		B0		2		Yes		No		115200		117647		2.1%	638 bytes	optiboot_flash_at90can32_UART0_115200_16000000L_BIGBOOT.hex
16000000L	UART0		B0		2		Yes		No		38400		38461		0.1%	638 bytes	optiboot_flash_at90can32_UART0_38400_16000000L_BIGBOOT.hex
16000000L	UART0		B0		2		Yes		No		19200		19230		0.1%	638 bytes	optiboot_flash_at90can32_UART0_19200_16000000L_BIGBOOT.hex
16000000L	UART0		B0		2		Yes		No		9600		9615		0.1%	638 bytes	optiboot_flash_at90can32_UART0_9600_16000000L_BIGBOOT.hex
14745600L	UART0		B0		2		Yes		No		230400		230400		0.0%	638 bytes	optiboot_flash_at90can32_UART0_230400_14745600L_BIGBOOT.hex
14745600L	UART0		B0		2		Yes		No		115200		115200		0.0%	638 bytes	optiboot_flash_at90can32_UART0_115200_14745600L_BIGBOOT.hex
14745600L	UART0		B0		2		Yes		No		57600		57600		0.0%	638 bytes	optiboot_flash_at90can32_UART0_57600_14745600L_BIGBOOT.hex
14745600L	UART0		B0		2		Yes		No		38400		38400		0.0%	638 bytes	optiboot_flash_at90can32_UART0_38400_14745600L_BIGBOOT.hex
14745600L	UART0		B0		2		Yes		No		19200		19200		0.0%	638 bytes	optiboot_flash_at90can32_UART0_19200_14745600L_BIGBOOT.hex
14745600L	UART0		B0		2		Yes		No		9600		9600		0.0%	638 bytes	optiboot_flash_at90can32_UART0_9600_14745600L_BIGBOOT.hex
12000000L	UART0		B0		2		Yes		No		500000		500000		0.0%	636 bytes	optiboot_flash_at90can32_UART0_500000_12000000L_BIGBOOT.hex
12000000L	UART0		B0		2		Yes		No		250000		250000		0.0%	636 bytes	optiboot_flash_at90can32_UART0_250000_12000000L_BIGBOOT.hex
12000000L	UART0		B0		2		Yes		No		57600		57692		0.1%	638 bytes	optiboot_flash_at90can32_UART0_57600_12000000L_BIGBOOT.hex
12000000L	UART0		B0		2		Yes		No		19200		19230		0.1%	638 bytes	optiboot_flash_at90can32_UART0_19200_12000000L_BIGBOOT.hex
12000000L	UART0		B0		2		Yes		No		9600		9615		0.1%	638 bytes	optiboot_flash_at90can32_UART0_9600_12000000L_BIGBOOT.hex
11059200L	UART0		B0		2		Yes		No		230400		230400		0.0%	636 bytes	optiboot_flash_at90can32_UART0_230400_11059200L_BIGBOOT.hex
11059200L	UART0		B0		2		Yes		No		115200		115200		0.0%	638 bytes	optiboot_flash_at90can32_UART0_115200_11059200L_BIGBOOT.hex
11059200L	UART0		B0		2		Yes		No		57600		57600		0.0%	638 bytes	optiboot_flash_at90can32_UART0_57600_11059200L_BIGBOOT.hex
11059200L	UART0		B0		2		Yes		No		38400		38400		0.0%	638 bytes	optiboot_flash_at90can32_UART0_38400_11059200L_BIGBOOT.hex
11059200L	UART0		B0		2		Yes		No		19200		19200		0.0%	638 bytes	optiboot_flash_at90can32_UART0_19200_11059200L_BIGBOOT.hex
11059200L	UART0		B0		2		Yes		No		9600		9600		0.0%	638 bytes	optiboot_flash_at90can32_UART0_9600_11059200L_BIGBOOT.hex
8000000L	UART0		B0		2		Yes		No		1000000		1000000		0.0%	636 bytes	optiboot_flash_at90can32_UART0_1000000_8000000L_BIGBOOT.hex
8000000L	UART0		B0		2		Yes		No		500000		500000		0.0%	638 bytes	optiboot_flash_at90can32_UART0_500000_8000000L_BIGBOOT.hex
8000000L	UART0		B0		2		Yes		No		250000		250000		0.0%	638 bytes	optiboot_flash_at90can32_UART0_250000_8000000L_BIGBOOT.hex
8000000L	UART0		B0		2		Yes		No		115200		111111		-3.5%	638 bytes	optiboot_flash_at90can32_UART0_115200_8000000L_BIGBOOT.hex
8000000L	UART0		B0		2		Yes		No		57600		58823		2.1%	638 bytes	optiboot_flash_at90can32_UART0_57600_8000000L_BIGBOOT.hex
8000000L	UART0		B0		2		Yes		No		38400		38461		0.1%	638 bytes	optiboot_flash_at90can32_UART0_38400_8000000L_BIGBOOT.hex
8000000L	UART0		B0		2		Yes		No		19200		19230		0.1%	638 bytes	optiboot_flash_at90can32_UART0_19200_8000000L_BIGBOOT.hex
8000000L	UART0		B0		2		Yes		No		9600		9615		0.1%	638 bytes	optiboot_flash_at90can32_UART0_9600_8000000L_BIGBOOT.hex
7372800L	UART0		B0		2		Yes		No		230400		230400		0.0%	638 bytes	optiboot_flash_at90can32_UART0_230400_7372800L_BIGBOOT.hex
7372800L	UART0		B0		2		Yes		No		115200		115200		0.0%	638 bytes	optiboot_flash_at90can32_UART0_115200_7372800L_BIGBOOT.hex
7372800L	UART0		B0		2		Yes		No		57600		57600		0.0%	638 bytes	optiboot_flash_at90can32_UART0_57600_7372800L_BIGBOOT.hex
7372800L	UART0		B0		2		Yes		No		38400		38400		0.0%	638 bytes	optiboot_flash_at90can32_UART0_38400_7372800L_BIGBOOT.hex
7372800L	UART0		B0		2		Yes		No		19200		19200		0.0%	638 bytes	optiboot_flash_at90can32_UART0_19200_7372800L_BIGBOOT.hex
7372800L	UART0		B0		2		Yes		No		9600		9600		0.0%	638 bytes	optiboot_flash_at90can32_UART0_9600_7372800L_BIGBOOT.hex
4000000L	UART0		B0		2		Yes		No		500000		500000		0.0%	636 bytes	optiboot_flash_at90can32_UART0_500000_4000000L_BIGBOOT.hex
4000000L	UART0		B0		2		Yes		No		250000		250000		0.0%	638 bytes	optiboot_flash_at90can32_UART0_250000_4000000L_BIGBOOT.hex
4000000L	UART0		B0		2		Yes		No		19200		19230		0.1%	638 bytes	optiboot_flash_at90can32_UART0_19200_4000000L_BIGBOOT.hex
4000000L	UART0		B0		2		Yes		No		9600		9615		0.1%	638 bytes	optiboot_flash_at90can32_UART0_9600_4000000L_BIGBOOT.hex
3686400L	UART0		B0		2		Yes		No		230400		230400		0.0%	638 bytes	optiboot_flash_at90can32_UART0_230400_3686400L_BIGBOOT.hex
3686400L	UART0		B0		2		Yes		No		115200		115200		0.0%	638 bytes	optiboot_flash_at90can32_UART0_115200_3686400L_BIGBOOT.hex
3686400L	UART0		B0		2		Yes		No		57600		57600		0.0%	638 bytes	optiboot_flash_at90can32_UART0_57600_3686400L_BIGBOOT.hex
3686400L	UART0		B0		2		Yes		No		38400		38400		0.0%	638 bytes	optiboot_flash_at90can32_UART0_38400_3686400L_BIGBOOT.hex
3686400L	UART0		B0		2		Yes		No		19200		19200		0.0%	638 bytes	optiboot_flash_at90can32_UART0_19200_3686400L_BIGBOOT.hex
3686400L	UART0		B0		2		Yes		No		9600		9600		0.0%	638 bytes	optiboot_flash_at90can32_UART0_9600_3686400L_BIGBOOT.hex
2000000L	UART0		B0		2		Yes		No		250000		250000		0.0%	636 bytes	optiboot_flash_at90can32_UART0_250000_2000000L_BIGBOOT.hex
2000000L	UART0		B0		2		Yes		No		19200		19230		0.1%	638 bytes	optiboot_flash_at90can32_UART0_19200_2000000L_BIGBOOT.hex
2000000L	UART0		B0		2		Yes		No		9600		9615		0.1%	638 bytes	optiboot_flash_at90can32_UART0_9600_2000000L_BIGBOOT.hex
1843200L	UART0		B0		2		Yes		No		230400		230400		0.0%	636 bytes	optiboot_flash_at90can32_UART0_230400_1843200L_BIGBOOT.hex
1843200L	UART0		B0		2		Yes		No		115200		115200		0.0%	638 bytes	optiboot_flash_at90can32_UART0_115200_1843200L_BIGBOOT.hex
1843200L	UART0		B0		2		Yes		No		57600		57600		0.0%	638 bytes	optiboot_flash_at90can32_UART0_57600_1843200L_BIGBOOT.hex
1843200L	UART0		B0		2		Yes		No		38400		38400		0.0%	636 bytes	optiboot_flash_at90can32_UART0_38400_1843200L_BIGBOOT.hex
1843200L	UART0		B0		2		Yes		No		19200		19200		0.0%	638 bytes	optiboot_flash_at90can32_UART0_19200_1843200L_BIGBOOT.hex
1843200L	UART0		B0		2		Yes		No		9600		9600		0.0%	638 bytes	optiboot_flash_at90can32_UART0_9600_1843200L_BIGBOOT.hex
1000000L	UART0		B0		2		Yes		No		9600		9615		0.1%	638 bytes	optiboot_flash_at90can32_UART0_9600_1000000L_BIGBOOT.hex

Optiboot_flash build output for at90can32 
https://github.com/MCUdude/optiboot_flash 
Build date and time: 15.05.2019 23:28 
Compiler: avr-gcc 5.4.0
 
F_CPU:		UART NUMBER:	LED PIN:	LED FLASHES:	EEPROM SUPPORT:	FLASH PG COPY:	DESIRED BAUD:	ACTUAL BAUD:	ERROR:	COMPILED SIZE:	OUTPUT FILE:
24000000L	UART1		B0		2		Yes		No		1000000		1000000		0.0%	636 bytes	optiboot_flash_at90can32_UART1_1000000_24000000L_BIGBOOT.hex
24000000L	UART1		B0		2		Yes		No		500000		500000		0.0%	636 bytes	optiboot_flash_at90can32_UART1_500000_24000000L_BIGBOOT.hex
24000000L	UART1		B0		2		Yes		No		250000		250000		0.0%	638 bytes	optiboot_flash_at90can32_UART1_250000_24000000L_BIGBOOT.hex
24000000L	UART1		B0		2		Yes		No		230400		230769		0.1%	638 bytes	optiboot_flash_at90can32_UART1_230400_24000000L_BIGBOOT.hex
24000000L	UART1		B0		2		Yes		No		115200		115384		0.1%	638 bytes	optiboot_flash_at90can32_UART1_115200_24000000L_BIGBOOT.hex
24000000L	UART1		B0		2		Yes		No		57600		57692		0.1%	638 bytes	optiboot_flash_at90can32_UART1_57600_24000000L_BIGBOOT.hex
24000000L	UART1		B0		2		Yes		No		38400		38461		0.1%	638 bytes	optiboot_flash_at90can32_UART1_38400_24000000L_BIGBOOT.hex
24000000L	UART1		B0		2		Yes		No		19200		19230		0.1%	638 bytes	optiboot_flash_at90can32_UART1_19200_24000000L_BIGBOOT.hex
20000000L	UART1		B0		2		Yes		No		500000		500000		0.0%	638 bytes	optiboot_flash_at90can32_UART1_500000_20000000L_BIGBOOT.hex
20000000L	UART1		B0		2		Yes		No		250000		250000		0.0%	638 bytes	optiboot_flash_at90can32_UART1_250000_20000000L_BIGBOOT.hex
20000000L	UART1		B0		2		Yes		No		115200		113636		-1.3%	638 bytes	optiboot_flash_at90can32_UART1_115200_20000000L_BIGBOOT.hex
20000000L	UART1		B0		2		Yes		No		19200		19230		0.1%	638 bytes	optiboot_flash_at90can32_UART1_19200_20000000L_BIGBOOT.hex
18432000L	UART1		B0		2		Yes		No		230400		230400		0.0%	638 bytes	optiboot_flash_at90can32_UART1_230400_18432000L_BIGBOOT.hex
18432000L	UART1		B0		2		Yes		No		115200		115200		0.0%	638 bytes	optiboot_flash_at90can32_UART1_115200_18432000L_BIGBOOT.hex
18432000L	UART1		B0		2		Yes		No		57600		57600		0.0%	638 bytes	optiboot_flash_at90can32_UART1_57600_18432000L_BIGBOOT.hex
18432000L	UART1		B0		2		Yes		No		38400		38400		0.0%	638 bytes	optiboot_flash_at90can32_UART1_38400_18432000L_BIGBOOT.hex
18432000L	UART1		B0		2		Yes		No		19200		19200		0.0%	638 bytes	optiboot_flash_at90can32_UART1_19200_18432000L_BIGBOOT.hex
18432000L	UART1		B0		2		Yes		No		9600		9600		0.0%	638 bytes	optiboot_flash_at90can32_UART1_9600_18432000L_BIGBOOT.hex
16000000L	UART1		B0		2		Yes		No		1000000		1000000		0.0%	638 bytes	optiboot_flash_at90can32_UART1_1000000_16000000L_BIGBOOT.hex
16000000L	UART1		B0		2		Yes		No		500000		500000		0.0%	638 bytes	optiboot_flash_at90can32_UART1_500000_16000000L_BIGBOOT.hex
16000000L	UART1		B0		2		Yes		No		250000		250000		0.0%	638 bytes	optiboot_flash_at90can32_UART1_250000_16000000L_BIGBOOT.hex
16000000L	UART1		B0		2		Yes		No		115200		117647		2.1%	638 bytes	optiboot_flash_at90can32_UART1_115200_16000000L_BIGBOOT.hex
16000000L	UART1		B0		2		Yes		No		38400		38461		0.1%	638 bytes	optiboot_flash_at90can32_UART1_38400_16000000L_BIGBOOT.hex
16000000L	UART1		B0		2		Yes		No		19200		19230		0.1%	638 bytes	optiboot_flash_at90can32_UART1_19200_16000000L_BIGBOOT.hex
16000000L	UART1		B0		2		Yes		No		9600		9615		0.1%	638 bytes	optiboot_flash_at90can32_UART1_9600_16000000L_BIGBOOT.hex
14745600L	UART1		B0		2		Yes		No		230400		230400		0.0%	638 bytes	optiboot_flash_at90can32_UART1_230400_14745600L_BIGBOOT.hex
14745600L	UART1		B0		2		Yes		No		115200		115200		0.0%	638 bytes	optiboot_flash_at90can32_UART1_115200_14745600L_BIGBOOT.hex
14745600L	UART1		B0		2		Yes		No		57600		57600		0.0%	638 bytes	optiboot_flash_at90can32_UART1_57600_14745600L_BIGBOOT.hex
14745600L	UART1		B0		2		Yes		No		38400		38400		0.0%	638 bytes	optiboot_flash_at90can32_UART1_38400_14745600L_BIGBOOT.hex
14745600L	UART1		B0		2		Yes		No		19200		19200		0.0%	638 bytes	optiboot_flash_at90can32_UART1_19200_14745600L_BIGBOOT.hex
14745600L	UART1		B0		2		Yes		No		9600		9600		0.0%	638 bytes	optiboot_flash_at90can32_UART1_9600_14745600L_BIGBOOT.hex
12000000L	UART1		B0		2		Yes		No		500000		500000		0.0%	636 bytes	optiboot_flash_at90can32_UART1_500000_12000000L_BIGBOOT.hex
12000000L	UART1		B0		2		Yes		No		250000		250000		0.0%	636 bytes	optiboot_flash_at90can32_UART1_250000_12000000L_BIGBOOT.hex
12000000L	UART1		B0		2		Yes		No		57600		57692		0.1%	638 bytes	optiboot_flash_at90can32_UART1_57600_12000000L_BIGBOOT.hex
12000000L	UART1		B0		2		Yes		No		19200		19230		0.1%	638 bytes	optiboot_flash_at90can32_UART1_19200_12000000L_BIGBOOT.hex
12000000L	UART1		B0		2		Yes		No		9600		9615		0.1%	638 bytes	optiboot_flash_at90can32_UART1_9600_12000000L_BIGBOOT.hex
11059200L	UART1		B0		2		Yes		No		230400		230400		0.0%	636 bytes	optiboot_flash_at90can32_UART1_230400_11059200L_BIGBOOT.hex
11059200L	UART1		B0		2		Yes		No		115200		115200		0.0%	638 bytes	optiboot_flash_at90can32_UART1_115200_11059200L_BIGBOOT.hex
11059200L	UART1		B0		2		Yes		No		57600		57600		0.0%	638 bytes	optiboot_flash_at90can32_UART1_57600_11059200L_BIGBOOT.hex
11059200L	UART1		B0		2		Yes		No		38400		38400		0.0%	638 bytes	optiboot_flash_at90can32_UART1_38400_11059200L_BIGBOOT.hex
11059200L	UART1		B0		2		Yes		No		19200		19200		0.0%	638 bytes	optiboot_flash_at90can32_UART1_19200_11059200L_BIGBOOT.hex
11059200L	UART1		B0		2		Yes		No		9600		9600		0.0%	638 bytes	optiboot_flash_at90can32_UART1_9600_11059200L_BIGBOOT.hex
8000000L	UART1		B0		2		Yes		No		1000000		1000000		0.0%	636 bytes	optiboot_flash_at90can32_UART1_1000000_8000000L_BIGBOOT.hex
8000000L	UART1		B0		2		Yes		No		500000		500000		0.0%	638 bytes	optiboot_flash_at90can32_UART1_500000_8000000L_BIGBOOT.hex
8000000L	UART1		B0		2		Yes		No		250000		250000		0.0%	638 bytes	optiboot_flash_at90can32_UART1_250000_8000000L_BIGBOOT.hex
8000000L	UART1		B0		2		Yes		No		115200		111111		-3.5%	638 bytes	optiboot_flash_at90can32_UART1_115200_8000000L_BIGBOOT.hex
8000000L	UART1		B0		2		Yes		No		57600		58823		2.1%	638 bytes	optiboot_flash_at90can32_UART1_57600_8000000L_BIGBOOT.hex
8000000L	UART1		B0		2		Yes		No		38400		38461		0.1%	638 bytes	optiboot_flash_at90can32_UART1_38400_8000000L_BIGBOOT.hex
8000000L	UART1		B0		2		Yes		No		19200		19230		0.1%	638 bytes	optiboot_flash_at90can32_UART1_19200_8000000L_BIGBOOT.hex
8000000L	UART1		B0		2		Yes		No		9600		9615		0.1%	638 bytes	optiboot_flash_at90can32_UART1_9600_8000000L_BIGBOOT.hex
7372800L	UART1		B0		2		Yes		No		230400		230400		0.0%	638 bytes	optiboot_flash_at90can32_UART1_230400_7372800L_BIGBOOT.hex
7372800L	UART1		B0		2		Yes		No		115200		115200		0.0%	638 bytes	optiboot_flash_at90can32_UART1_115200_7372800L_BIGBOOT.hex
7372800L	UART1		B0		2		Yes		No		57600		57600		0.0%	638 bytes	optiboot_flash_at90can32_UART1_57600_7372800L_BIGBOOT.hex
7372800L	UART1		B0		2		Yes		No		38400		38400		0.0%	638 bytes	optiboot_flash_at90can32_UART1_38400_7372800L_BIGBOOT.hex
7372800L	UART1		B0		2		Yes		No		19200		19200		0.0%	638 bytes	optiboot_flash_at90can32_UART1_19200_7372800L_BIGBOOT.hex
7372800L	UART1		B0		2		Yes		No		9600		9600		0.0%	638 bytes	optiboot_flash_at90can32_UART1_9600_7372800L_BIGBOOT.hex
4000000L	UART1		B0		2		Yes		No		500000		500000		0.0%	636 bytes	optiboot_flash_at90can32_UART1_500000_4000000L_BIGBOOT.hex
4000000L	UART1		B0		2		Yes		No		250000		250000		0.0%	638 bytes	optiboot_flash_at90can32_UART1_250000_4000000L_BIGBOOT.hex
4000000L	UART1		B0		2		Yes		No		19200		19230		0.1%	638 bytes	optiboot_flash_at90can32_UART1_19200_4000000L_BIGBOOT.hex
4000000L	UART1		B0		2		Yes		No		9600		9615		0.1%	638 bytes	optiboot_flash_at90can32_UART1_9600_4000000L_BIGBOOT.hex
3686400L	UART1		B0		2		Yes		No		230400		230400		0.0%	638 bytes	optiboot_flash_at90can32_UART1_230400_3686400L_BIGBOOT.hex
3686400L	UART1		B0		2		Yes		No		115200		115200		0.0%	638 bytes	optiboot_flash_at90can32_UART1_115200_3686400L_BIGBOOT.hex
3686400L	UART1		B0		2		Yes		No		57600		57600		0.0%	638 bytes	optiboot_flash_at90can32_UART1_57600_3686400L_BIGBOOT.hex
3686400L	UART1		B0		2		Yes		No		38400		38400		0.0%	638 bytes	optiboot_flash_at90can32_UART1_38400_3686400L_BIGBOOT.hex
3686400L	UART1		B0		2		Yes		No		19200		19200		0.0%	638 bytes	optiboot_flash_at90can32_UART1_19200_3686400L_BIGBOOT.hex
3686400L	UART1		B0		2		Yes		No		9600		9600		0.0%	638 bytes	optiboot_flash_at90can32_UART1_9600_3686400L_BIGBOOT.hex
2000000L	UART1		B0		2		Yes		No		250000		250000		0.0%	636 bytes	optiboot_flash_at90can32_UART1_250000_2000000L_BIGBOOT.hex
2000000L	UART1		B0		2		Yes		No		19200		19230		0.1%	638 bytes	optiboot_flash_at90can32_UART1_19200_2000000L_BIGBOOT.hex
2000000L	UART1		B0		2		Yes		No		9600		9615		0.1%	638 bytes	optiboot_flash_at90can32_UART1_9600_2000000L_BIGBOOT.hex
1843200L	UART1		B0		2		Yes		No		230400		230400		0.0%	636 bytes	optiboot_flash_at90can32_UART1_230400_1843200L_BIGBOOT.hex
1843200L	UART1		B0		2		Yes		No		115200		115200		0.0%	638 bytes	optiboot_flash_at90can32_UART1_115200_1843200L_BIGBOOT.hex
1843200L	UART1		B0		2		Yes		No		57600		57600		0.0%	638 bytes	optiboot_flash_at90can32_UART1_57600_1843200L_BIGBOOT.hex
1843200L	UART1		B0		2		Yes		No		38400		38400		0.0%	636 bytes	optiboot_flash_at90can32_UART1_38400_1843200L_BIGBOOT.hex
1843200L	UART1		B0		2		Yes		No		19200		19200		0.0%	638 bytes	optiboot_flash_at90can32_UART1_19200_1843200L_BIGBOOT.hex
1843200L	UART1		B0		2		Yes		No		9600		9600		0.0%	638 bytes	optiboot_flash_at90can32_UART1_9600_1843200L_BIGBOOT.hex
1000000L	UART1		B0		2		Yes		No		9600		9615		0.1%	638 bytes	optiboot_flash_at90can32_UART1_9600_1000000L_BIGBOOT.hex

Optiboot_flash build output for at90can32 
https://github.com/MCUdude/optiboot_flash 
Build date and time: 18.05.2019 20:26 
Compiler: avr-gcc 5.4.0
 
F_CPU:		UART NUMBER:	LED PIN:	LED FLASHES:	EEPROM SUPPORT:	FLASH PG COPY:	DESIRED BAUD:	ACTUAL BAUD:	ERROR:	COMPILED SIZE:	OUTPUT FILE:
18432000L	UART0		B0		2		Yes		No		460800		460800		0.0%	638 bytes	optiboot_flash_at90can32_UART0_460800_18432000L_BIGBOOT.hex
14745600L	UART0		B0		2		Yes		No		460800		460800		0.0%	638 bytes	optiboot_flash_at90can32_UART0_460800_14745600L_BIGBOOT.hex
11059200L	UART0		B0		2		Yes		No		460800		460800		0.0%	636 bytes	optiboot_flash_at90can32_UART0_460800_11059200L_BIGBOOT.hex
7372800L	UART0		B0		2		Yes		No		460800		460800		0.0%	638 bytes	optiboot_flash_at90can32_UART0_460800_7372800L_BIGBOOT.hex
3686400L	UART0		B0		2		Yes		No		460800		460800		0.0%	636 bytes	optiboot_flash_at90can32_UART0_460800_3686400L_BIGBOOT.hex

Optiboot_flash build output for at90can32 
https://github.com/MCUdude/optiboot_flash 
Build date and time: 18.05.2019 20:26 
Compiler: avr-gcc 5.4.0
 
F_CPU:		UART NUMBER:	LED PIN:	LED FLASHES:	EEPROM SUPPORT:	FLASH PG COPY:	DESIRED BAUD:	ACTUAL BAUD:	ERROR:	COMPILED SIZE:	OUTPUT FILE:
18432000L	UART1		B0		2		Yes		No		460800		460800		0.0%	638 bytes	optiboot_flash_at90can32_UART1_460800_18432000L_BIGBOOT.hex
14745600L	UART1		B0		2		Yes		No		460800		460800		0.0%	638 bytes	optiboot_flash_at90can32_UART1_460800_14745600L_BIGBOOT.hex
11059200L	UART1		B0		2		Yes		No		460800		460800		0.0%	636 bytes	optiboot_flash_at90can32_UART1_460800_11059200L_BIGBOOT.hex
7372800L	UART1		B0		2		Yes		No		460800		460800		0.0%	638 bytes	optiboot_flash_at90can32_UART1_460800_7372800L_BIGBOOT.hex
3686400L	UART1		B0		2		Yes		No		460800		460800		0.0%	636 bytes	optiboot_flash_at90can32_UART1_460800_3686400L_BIGBOOT.hex

Optiboot_flash build output for at90can32 
https://github.com/MCUdude/optiboot_flash 
Build date and time: 03.08.2019 01:04 
Compiler: avr-gcc 5.4.0
 
F_CPU:		UART NUMBER:	LED PIN:	LED FLASHES:	EEPROM SUPPORT:	FLASH PG COPY:	DESIRED BAUD:	ACTUAL BAUD:	ERROR:	COMPILED SIZE:	OUTPUT FILE:
22118400L	UART0		B0		2		Yes		No		460800		460800		0.0%	636 bytes	optiboot_flash_at90can32_UART0_460800_22118400L_BIGBOOT.hex
22118400L	UART0		B0		2		Yes		No		230400		230400		0.0%	638 bytes	optiboot_flash_at90can32_UART0_230400_22118400L_BIGBOOT.hex
22118400L	UART0		B0		2		Yes		No		115200		115200		0.0%	638 bytes	optiboot_flash_at90can32_UART0_115200_22118400L_BIGBOOT.hex
22118400L	UART0		B0		2		Yes		No		57600		57600		0.0%	638 bytes	optiboot_flash_at90can32_UART0_57600_22118400L_BIGBOOT.hex
22118400L	UART0		B0		2		Yes		No		38400		38400		0.0%	638 bytes	optiboot_flash_at90can32_UART0_38400_22118400L_BIGBOOT.hex
22118400L	UART0		B0		2		Yes		No		19200		19200		0.0%	638 bytes	optiboot_flash_at90can32_UART0_19200_22118400L_BIGBOOT.hex

Optiboot_flash build output for at90can32 
https://github.com/MCUdude/optiboot_flash 
Build date and time: 03.08.2019 01:04 
Compiler: avr-gcc 5.4.0
 
F_CPU:		UART NUMBER:	LED PIN:	LED FLASHES:	EEPROM SUPPORT:	FLASH PG COPY:	DESIRED BAUD:	ACTUAL BAUD:	ERROR:	COMPILED SIZE:	OUTPUT FILE:
22118400L	UART1		B0		2		Yes		No		460800		460800		0.0%	636 bytes	optiboot_flash_at90can32_UART1_460800_22118400L_BIGBOOT.hex
22118400L	UART1		B0		2		Yes		No		230400		230400		0.0%	638 bytes	optiboot_flash_at90can32_UART1_230400_22118400L_BIGBOOT.hex
22118400L	UART1		B0		2		Yes		No		115200		115200		0.0%	638 bytes	optiboot_flash_at90can32_UART1_115200_22118400L_BIGBOOT.hex
22118400L	UART1		B0		2		Yes		No		57600		57600		0.0%	638 bytes	optiboot_flash_at90can32_UART1_57600_22118400L_BIGBOOT.hex
22118400L	UART1		B0		2		Yes		No		38400		38400		0.0%	638 bytes	optiboot_flash_at90can32_UART1_38400_22118400L_BIGBOOT.hex
22118400L	UART1		B0		2		Yes		No		19200		19200		0.0%	638 bytes	optiboot_flash_at90can32_UART1_19200_22118400L_BIGBOOT.hex

Optiboot_flash build output for at90can32 
https://github.com/MCUdude/optiboot_flash 
Build date and time: 04.11.2019 19:35 
Compiler: avr-gcc 7.3.0
 
F_CPU:		UART NUMBER:	LED PIN:	LED FLASHES:	EEPROM SUPPORT:	FLASH PG COPY:	DESIRED BAUD:	ACTUAL BAUD:	ERROR:	COMPILED SIZE:	OUTPUT FILE:
24000000L	UART0		B5		2		Yes		No		1000000		1000000		0.0%	640 bytes	optiboot_flash_at90can32_UART0_1000000_24000000L_B5_BIGBOOT.hex
24000000L	UART0		B5		2		Yes		No		500000		500000		0.0%	640 bytes	optiboot_flash_at90can32_UART0_500000_24000000L_B5_BIGBOOT.hex
24000000L	UART0		B5		2		Yes		No		250000		250000		0.0%	642 bytes	optiboot_flash_at90can32_UART0_250000_24000000L_B5_BIGBOOT.hex
24000000L	UART0		B5		2		Yes		No		230400		230769		0.1%	642 bytes	optiboot_flash_at90can32_UART0_230400_24000000L_B5_BIGBOOT.hex
24000000L	UART0		B5		2		Yes		No		115200		115384		0.1%	642 bytes	optiboot_flash_at90can32_UART0_115200_24000000L_B5_BIGBOOT.hex
24000000L	UART0		B5		2		Yes		No		57600		57692		0.1%	642 bytes	optiboot_flash_at90can32_UART0_57600_24000000L_B5_BIGBOOT.hex
24000000L	UART0		B5		2		Yes		No		38400		38461		0.1%	642 bytes	optiboot_flash_at90can32_UART0_38400_24000000L_B5_BIGBOOT.hex
24000000L	UART0		B5		2		Yes		No		19200		19230		0.1%	642 bytes	optiboot_flash_at90can32_UART0_19200_24000000L_B5_BIGBOOT.hex
22118400L	UART0		B5		2		Yes		No		460800		460800		0.0%	640 bytes	optiboot_flash_at90can32_UART0_460800_22118400L_B5_BIGBOOT.hex
22118400L	UART0		B5		2		Yes		No		230400		230400		0.0%	642 bytes	optiboot_flash_at90can32_UART0_230400_22118400L_B5_BIGBOOT.hex
22118400L	UART0		B5		2		Yes		No		115200		115200		0.0%	642 bytes	optiboot_flash_at90can32_UART0_115200_22118400L_B5_BIGBOOT.hex
22118400L	UART0		B5		2		Yes		No		57600		57600		0.0%	642 bytes	optiboot_flash_at90can32_UART0_57600_22118400L_B5_BIGBOOT.hex
22118400L	UART0		B5		2		Yes		No		38400		38400		0.0%	642 bytes	optiboot_flash_at90can32_UART0_38400_22118400L_B5_BIGBOOT.hex
22118400L	UART0		B5		2		Yes		No		19200		19200		0.0%	642 bytes	optiboot_flash_at90can32_UART0_19200_22118400L_B5_BIGBOOT.hex
20000000L	UART0		B5		2		Yes		No		500000		500000		0.0%	642 bytes	optiboot_flash_at90can32_UART0_500000_20000000L_B5_BIGBOOT.hex
20000000L	UART0		B5		2		Yes		No		250000		250000		0.0%	642 bytes	optiboot_flash_at90can32_UART0_250000_20000000L_B5_BIGBOOT.hex
20000000L	UART0		B5		2		Yes		No		115200		113636		-1.3%	642 bytes	optiboot_flash_at90can32_UART0_115200_20000000L_B5_BIGBOOT.hex
20000000L	UART0		B5		2		Yes		No		19200		19230		0.1%	642 bytes	optiboot_flash_at90can32_UART0_19200_20000000L_B5_BIGBOOT.hex
18432000L	UART0		B5		2		Yes		No		460800		460800		0.0%	642 bytes	optiboot_flash_at90can32_UART0_460800_18432000L_B5_BIGBOOT.hex
18432000L	UART0		B5		2		Yes		No		230400		230400		0.0%	642 bytes	optiboot_flash_at90can32_UART0_230400_18432000L_B5_BIGBOOT.hex
18432000L	UART0		B5		2		Yes		No		115200		115200		0.0%	642 bytes	optiboot_flash_at90can32_UART0_115200_18432000L_B5_BIGBOOT.hex
18432000L	UART0		B5		2		Yes		No		57600		57600		0.0%	642 bytes	optiboot_flash_at90can32_UART0_57600_18432000L_B5_BIGBOOT.hex
18432000L	UART0		B5		2		Yes		No		38400		38400		0.0%	642 bytes	optiboot_flash_at90can32_UART0_38400_18432000L_B5_BIGBOOT.hex
18432000L	UART0		B5		2		Yes		No		19200		19200		0.0%	642 bytes	optiboot_flash_at90can32_UART0_19200_18432000L_B5_BIGBOOT.hex
18432000L	UART0		B5		2		Yes		No		9600		9600		0.0%	642 bytes	optiboot_flash_at90can32_UART0_9600_18432000L_B5_BIGBOOT.hex
16000000L	UART0		B5		2		Yes		No		1000000		1000000		0.0%	642 bytes	optiboot_flash_at90can32_UART0_1000000_16000000L_B5_BIGBOOT.hex
16000000L	UART0		B5		2		Yes		No		500000		500000		0.0%	642 bytes	optiboot_flash_at90can32_UART0_500000_16000000L_B5_BIGBOOT.hex
16000000L	UART0		B5		2		Yes		No		250000		250000		0.0%	642 bytes	optiboot_flash_at90can32_UART0_250000_16000000L_B5_BIGBOOT.hex
16000000L	UART0		B5		2		Yes		No		115200		117647		2.1%	642 bytes	optiboot_flash_at90can32_UART0_115200_16000000L_B5_BIGBOOT.hex
16000000L	UART0		B5		2		Yes		No		38400		38461		0.1%	642 bytes	optiboot_flash_at90can32_UART0_38400_16000000L_B5_BIGBOOT.hex
16000000L	UART0		B5		2		Yes		No		19200		19230		0.1%	642 bytes	optiboot_flash_at90can32_UART0_19200_16000000L_B5_BIGBOOT.hex
16000000L	UART0		B5		2		Yes		No		9600		9615		0.1%	642 bytes	optiboot_flash_at90can32_UART0_9600_16000000L_B5_BIGBOOT.hex
14745600L	UART0		B5		2		Yes		No		460800		460800		0.0%	642 bytes	optiboot_flash_at90can32_UART0_460800_14745600L_B5_BIGBOOT.hex
14745600L	UART0		B5		2		Yes		No		230400		230400		0.0%	642 bytes	optiboot_flash_at90can32_UART0_230400_14745600L_B5_BIGBOOT.hex
14745600L	UART0		B5		2		Yes		No		115200		115200		0.0%	642 bytes	optiboot_flash_at90can32_UART0_115200_14745600L_B5_BIGBOOT.hex
14745600L	UART0		B5		2		Yes		No		57600		57600		0.0%	642 bytes	optiboot_flash_at90can32_UART0_57600_14745600L_B5_BIGBOOT.hex
14745600L	UART0		B5		2		Yes		No		38400		38400		0.0%	642 bytes	optiboot_flash_at90can32_UART0_38400_14745600L_B5_BIGBOOT.hex
14745600L	UART0		B5		2		Yes		No		19200		19200		0.0%	642 bytes	optiboot_flash_at90can32_UART0_19200_14745600L_B5_BIGBOOT.hex
14745600L	UART0		B5		2		Yes		No		9600		9600		0.0%	642 bytes	optiboot_flash_at90can32_UART0_9600_14745600L_B5_BIGBOOT.hex
12000000L	UART0		B5		2		Yes		No		500000		500000		0.0%	640 bytes	optiboot_flash_at90can32_UART0_500000_12000000L_B5_BIGBOOT.hex
12000000L	UART0		B5		2		Yes		No		250000		250000		0.0%	640 bytes	optiboot_flash_at90can32_UART0_250000_12000000L_B5_BIGBOOT.hex
12000000L	UART0		B5		2		Yes		No		57600		57692		0.1%	642 bytes	optiboot_flash_at90can32_UART0_57600_12000000L_B5_BIGBOOT.hex
12000000L	UART0		B5		2		Yes		No		19200		19230		0.1%	642 bytes	optiboot_flash_at90can32_UART0_19200_12000000L_B5_BIGBOOT.hex
12000000L	UART0		B5		2		Yes		No		9600		9615		0.1%	642 bytes	optiboot_flash_at90can32_UART0_9600_12000000L_B5_BIGBOOT.hex
11059200L	UART0		B5		2		Yes		No		460800		460800		0.0%	640 bytes	optiboot_flash_at90can32_UART0_460800_11059200L_B5_BIGBOOT.hex
11059200L	UART0		B5		2		Yes		No		230400		230400		0.0%	640 bytes	optiboot_flash_at90can32_UART0_230400_11059200L_B5_BIGBOOT.hex
11059200L	UART0		B5		2		Yes		No		115200		115200		0.0%	642 bytes	optiboot_flash_at90can32_UART0_115200_11059200L_B5_BIGBOOT.hex
11059200L	UART0		B5		2		Yes		No		57600		57600		0.0%	642 bytes	optiboot_flash_at90can32_UART0_57600_11059200L_B5_BIGBOOT.hex
11059200L	UART0		B5		2		Yes		No		38400		38400		0.0%	642 bytes	optiboot_flash_at90can32_UART0_38400_11059200L_B5_BIGBOOT.hex
11059200L	UART0		B5		2		Yes		No		19200		19200		0.0%	642 bytes	optiboot_flash_at90can32_UART0_19200_11059200L_B5_BIGBOOT.hex
11059200L	UART0		B5		2		Yes		No		9600		9600		0.0%	642 bytes	optiboot_flash_at90can32_UART0_9600_11059200L_B5_BIGBOOT.hex
8000000L	UART0		B5		2		Yes		No		1000000		1000000		0.0%	640 bytes	optiboot_flash_at90can32_UART0_1000000_8000000L_B5_BIGBOOT.hex
8000000L	UART0		B5		2		Yes		No		500000		500000		0.0%	642 bytes	optiboot_flash_at90can32_UART0_500000_8000000L_B5_BIGBOOT.hex
8000000L	UART0		B5		2		Yes		No		250000		250000		0.0%	642 bytes	optiboot_flash_at90can32_UART0_250000_8000000L_B5_BIGBOOT.hex
8000000L	UART0		B5		2		Yes		No		115200		111111		-3.5%	642 bytes	optiboot_flash_at90can32_UART0_115200_8000000L_B5_BIGBOOT.hex
8000000L	UART0		B5		2		Yes		No		57600		58823		2.1%	642 bytes	optiboot_flash_at90can32_UART0_57600_8000000L_B5_BIGBOOT.hex
8000000L	UART0		B5		2		Yes		No		38400		38461		0.1%	642 bytes	optiboot_flash_at90can32_UART0_38400_8000000L_B5_BIGBOOT.hex
8000000L	UART0		B5		2		Yes		No		19200		19230		0.1%	642 bytes	optiboot_flash_at90can32_UART0_19200_8000000L_B5_BIGBOOT.hex
8000000L	UART0		B5		2		Yes		No		9600		9615		0.1%	642 bytes	optiboot_flash_at90can32_UART0_9600_8000000L_B5_BIGBOOT.hex
7372800L	UART0		B5		2		Yes		No		460800		460800		0.0%	642 bytes	optiboot_flash_at90can32_UART0_460800_7372800L_B5_BIGBOOT.hex
7372800L	UART0		B5		2		Yes		No		230400		230400		0.0%	642 bytes	optiboot_flash_at90can32_UART0_230400_7372800L_B5_BIGBOOT.hex
7372800L	UART0		B5		2		Yes		No		115200		115200		0.0%	642 bytes	optiboot_flash_at90can32_UART0_115200_7372800L_B5_BIGBOOT.hex
7372800L	UART0		B5		2		Yes		No		57600		57600		0.0%	642 bytes	optiboot_flash_at90can32_UART0_57600_7372800L_B5_BIGBOOT.hex
7372800L	UART0		B5		2		Yes		No		38400		38400		0.0%	642 bytes	optiboot_flash_at90can32_UART0_38400_7372800L_B5_BIGBOOT.hex
7372800L	UART0		B5		2		Yes		No		19200		19200		0.0%	642 bytes	optiboot_flash_at90can32_UART0_19200_7372800L_B5_BIGBOOT.hex
7372800L	UART0		B5		2		Yes		No		9600		9600		0.0%	642 bytes	optiboot_flash_at90can32_UART0_9600_7372800L_B5_BIGBOOT.hex
4000000L	UART0		B5		2		Yes		No		500000		500000		0.0%	640 bytes	optiboot_flash_at90can32_UART0_500000_4000000L_B5_BIGBOOT.hex
4000000L	UART0		B5		2		Yes		No		250000		250000		0.0%	642 bytes	optiboot_flash_at90can32_UART0_250000_4000000L_B5_BIGBOOT.hex
4000000L	UART0		B5		2		Yes		No		19200		19230		0.1%	642 bytes	optiboot_flash_at90can32_UART0_19200_4000000L_B5_BIGBOOT.hex
4000000L	UART0		B5		2		Yes		No		9600		9615		0.1%	642 bytes	optiboot_flash_at90can32_UART0_9600_4000000L_B5_BIGBOOT.hex
3686400L	UART0		B5		2		Yes		No		460800		460800		0.0%	640 bytes	optiboot_flash_at90can32_UART0_460800_3686400L_B5_BIGBOOT.hex
3686400L	UART0		B5		2		Yes		No		230400		230400		0.0%	642 bytes	optiboot_flash_at90can32_UART0_230400_3686400L_B5_BIGBOOT.hex
3686400L	UART0		B5		2		Yes		No		115200		115200		0.0%	642 bytes	optiboot_flash_at90can32_UART0_115200_3686400L_B5_BIGBOOT.hex
3686400L	UART0		B5		2		Yes		No		57600		57600		0.0%	642 bytes	optiboot_flash_at90can32_UART0_57600_3686400L_B5_BIGBOOT.hex
3686400L	UART0		B5		2		Yes		No		38400		38400		0.0%	642 bytes	optiboot_flash_at90can32_UART0_38400_3686400L_B5_BIGBOOT.hex
3686400L	UART0		B5		2		Yes		No		19200		19200		0.0%	642 bytes	optiboot_flash_at90can32_UART0_19200_3686400L_B5_BIGBOOT.hex
3686400L	UART0		B5		2		Yes		No		9600		9600		0.0%	642 bytes	optiboot_flash_at90can32_UART0_9600_3686400L_B5_BIGBOOT.hex
2000000L	UART0		B5		2		Yes		No		250000		250000		0.0%	640 bytes	optiboot_flash_at90can32_UART0_250000_2000000L_B5_BIGBOOT.hex
2000000L	UART0		B5		2		Yes		No		19200		19230		0.1%	642 bytes	optiboot_flash_at90can32_UART0_19200_2000000L_B5_BIGBOOT.hex
2000000L	UART0		B5		2		Yes		No		9600		9615		0.1%	642 bytes	optiboot_flash_at90can32_UART0_9600_2000000L_B5_BIGBOOT.hex
1843200L	UART0		B5		2		Yes		No		230400		230400		0.0%	640 bytes	optiboot_flash_at90can32_UART0_230400_1843200L_B5_BIGBOOT.hex
1843200L	UART0		B5		2		Yes		No		115200		115200		0.0%	642 bytes	optiboot_flash_at90can32_UART0_115200_1843200L_B5_BIGBOOT.hex
1843200L	UART0		B5		2		Yes		No		57600		57600		0.0%	642 bytes	optiboot_flash_at90can32_UART0_57600_1843200L_B5_BIGBOOT.hex
1843200L	UART0		B5		2		Yes		No		38400		38400		0.0%	640 bytes	optiboot_flash_at90can32_UART0_38400_1843200L_B5_BIGBOOT.hex
1843200L	UART0		B5		2		Yes		No		19200		19200		0.0%	642 bytes	optiboot_flash_at90can32_UART0_19200_1843200L_B5_BIGBOOT.hex
1843200L	UART0		B5		2		Yes		No		9600		9600		0.0%	642 bytes	optiboot_flash_at90can32_UART0_9600_1843200L_B5_BIGBOOT.hex
1000000L	UART0		B5		2		Yes		No		9600		9615		0.1%	642 bytes	optiboot_flash_at90can32_UART0_9600_1000000L_B5_BIGBOOT.hex

Optiboot_flash build output for at90can32 
https://github.com/MCUdude/optiboot_flash 
Build date and time: 04.11.2019 19:36 
Compiler: avr-gcc 7.3.0
 
F_CPU:		UART NUMBER:	LED PIN:	LED FLASHES:	EEPROM SUPPORT:	FLASH PG COPY:	DESIRED BAUD:	ACTUAL BAUD:	ERROR:	COMPILED SIZE:	OUTPUT FILE:
24000000L	UART1		B5		2		Yes		No		1000000		1000000		0.0%	640 bytes	optiboot_flash_at90can32_UART1_1000000_24000000L_B5_BIGBOOT.hex
24000000L	UART1		B5		2		Yes		No		500000		500000		0.0%	640 bytes	optiboot_flash_at90can32_UART1_500000_24000000L_B5_BIGBOOT.hex
24000000L	UART1		B5		2		Yes		No		250000		250000		0.0%	642 bytes	optiboot_flash_at90can32_UART1_250000_24000000L_B5_BIGBOOT.hex
24000000L	UART1		B5		2		Yes		No		230400		230769		0.1%	642 bytes	optiboot_flash_at90can32_UART1_230400_24000000L_B5_BIGBOOT.hex
24000000L	UART1		B5		2		Yes		No		115200		115384		0.1%	642 bytes	optiboot_flash_at90can32_UART1_115200_24000000L_B5_BIGBOOT.hex
24000000L	UART1		B5		2		Yes		No		57600		57692		0.1%	642 bytes	optiboot_flash_at90can32_UART1_57600_24000000L_B5_BIGBOOT.hex
24000000L	UART1		B5		2		Yes		No		38400		38461		0.1%	642 bytes	optiboot_flash_at90can32_UART1_38400_24000000L_B5_BIGBOOT.hex
24000000L	UART1		B5		2		Yes		No		19200		19230		0.1%	642 bytes	optiboot_flash_at90can32_UART1_19200_24000000L_B5_BIGBOOT.hex
22118400L	UART1		B5		2		Yes		No		460800		460800		0.0%	640 bytes	optiboot_flash_at90can32_UART1_460800_22118400L_B5_BIGBOOT.hex
22118400L	UART1		B5		2		Yes		No		230400		230400		0.0%	642 bytes	optiboot_flash_at90can32_UART1_230400_22118400L_B5_BIGBOOT.hex
22118400L	UART1		B5		2		Yes		No		115200		115200		0.0%	642 bytes	optiboot_flash_at90can32_UART1_115200_22118400L_B5_BIGBOOT.hex
22118400L	UART1		B5		2		Yes		No		57600		57600		0.0%	642 bytes	optiboot_flash_at90can32_UART1_57600_22118400L_B5_BIGBOOT.hex
22118400L	UART1		B5		2		Yes		No		38400		38400		0.0%	642 bytes	optiboot_flash_at90can32_UART1_38400_22118400L_B5_BIGBOOT.hex
22118400L	UART1		B5		2		Yes		No		19200		19200		0.0%	642 bytes	optiboot_flash_at90can32_UART1_19200_22118400L_B5_BIGBOOT.hex
20000000L	UART1		B5		2		Yes		No		500000		500000		0.0%	642 bytes	optiboot_flash_at90can32_UART1_500000_20000000L_B5_BIGBOOT.hex
20000000L	UART1		B5		2		Yes		No		250000		250000		0.0%	642 bytes	optiboot_flash_at90can32_UART1_250000_20000000L_B5_BIGBOOT.hex
20000000L	UART1		B5		2		Yes		No		115200		113636		-1.3%	642 bytes	optiboot_flash_at90can32_UART1_115200_20000000L_B5_BIGBOOT.hex
20000000L	UART1		B5		2		Yes		No		19200		19230		0.1%	642 bytes	optiboot_flash_at90can32_UART1_19200_20000000L_B5_BIGBOOT.hex
18432000L	UART1		B5		2		Yes		No		460800		460800		0.0%	642 bytes	optiboot_flash_at90can32_UART1_460800_18432000L_B5_BIGBOOT.hex
18432000L	UART1		B5		2		Yes		No		230400		230400		0.0%	642 bytes	optiboot_flash_at90can32_UART1_230400_18432000L_B5_BIGBOOT.hex
18432000L	UART1		B5		2		Yes		No		115200		115200		0.0%	642 bytes	optiboot_flash_at90can32_UART1_115200_18432000L_B5_BIGBOOT.hex
18432000L	UART1		B5		2		Yes		No		57600		57600		0.0%	642 bytes	optiboot_flash_at90can32_UART1_57600_18432000L_B5_BIGBOOT.hex
18432000L	UART1		B5		2		Yes		No		38400		38400		0.0%	642 bytes	optiboot_flash_at90can32_UART1_38400_18432000L_B5_BIGBOOT.hex
18432000L	UART1		B5		2		Yes		No		19200		19200		0.0%	642 bytes	optiboot_flash_at90can32_UART1_19200_18432000L_B5_BIGBOOT.hex
18432000L	UART1		B5		2		Yes		No		9600		9600		0.0%	642 bytes	optiboot_flash_at90can32_UART1_9600_18432000L_B5_BIGBOOT.hex
16000000L	UART1		B5		2		Yes		No		1000000		1000000		0.0%	642 bytes	optiboot_flash_at90can32_UART1_1000000_16000000L_B5_BIGBOOT.hex
16000000L	UART1		B5		2		Yes		No		500000		500000		0.0%	642 bytes	optiboot_flash_at90can32_UART1_500000_16000000L_B5_BIGBOOT.hex
16000000L	UART1		B5		2		Yes		No		250000		250000		0.0%	642 bytes	optiboot_flash_at90can32_UART1_250000_16000000L_B5_BIGBOOT.hex
16000000L	UART1		B5		2		Yes		No		115200		117647		2.1%	642 bytes	optiboot_flash_at90can32_UART1_115200_16000000L_B5_BIGBOOT.hex
16000000L	UART1		B5		2		Yes		No		38400		38461		0.1%	642 bytes	optiboot_flash_at90can32_UART1_38400_16000000L_B5_BIGBOOT.hex
16000000L	UART1		B5		2		Yes		No		19200		19230		0.1%	642 bytes	optiboot_flash_at90can32_UART1_19200_16000000L_B5_BIGBOOT.hex
16000000L	UART1		B5		2		Yes		No		9600		9615		0.1%	642 bytes	optiboot_flash_at90can32_UART1_9600_16000000L_B5_BIGBOOT.hex
14745600L	UART1		B5		2		Yes		No		460800		460800		0.0%	642 bytes	optiboot_flash_at90can32_UART1_460800_14745600L_B5_BIGBOOT.hex
14745600L	UART1		B5		2		Yes		No		230400		230400		0.0%	642 bytes	optiboot_flash_at90can32_UART1_230400_14745600L_B5_BIGBOOT.hex
14745600L	UART1		B5		2		Yes		No		115200		115200		0.0%	642 bytes	optiboot_flash_at90can32_UART1_115200_14745600L_B5_BIGBOOT.hex
14745600L	UART1		B5		2		Yes		No		57600		57600		0.0%	642 bytes	optiboot_flash_at90can32_UART1_57600_14745600L_B5_BIGBOOT.hex
14745600L	UART1		B5		2		Yes		No		38400		38400		0.0%	642 bytes	optiboot_flash_at90can32_UART1_38400_14745600L_B5_BIGBOOT.hex
14745600L	UART1		B5		2		Yes		No		19200		19200		0.0%	642 bytes	optiboot_flash_at90can32_UART1_19200_14745600L_B5_BIGBOOT.hex
14745600L	UART1		B5		2		Yes		No		9600		9600		0.0%	642 bytes	optiboot_flash_at90can32_UART1_9600_14745600L_B5_BIGBOOT.hex
12000000L	UART1		B5		2		Yes		No		500000		500000		0.0%	640 bytes	optiboot_flash_at90can32_UART1_500000_12000000L_B5_BIGBOOT.hex
12000000L	UART1		B5		2		Yes		No		250000		250000		0.0%	640 bytes	optiboot_flash_at90can32_UART1_250000_12000000L_B5_BIGBOOT.hex
12000000L	UART1		B5		2		Yes		No		57600		57692		0.1%	642 bytes	optiboot_flash_at90can32_UART1_57600_12000000L_B5_BIGBOOT.hex
12000000L	UART1		B5		2		Yes		No		19200		19230		0.1%	642 bytes	optiboot_flash_at90can32_UART1_19200_12000000L_B5_BIGBOOT.hex
12000000L	UART1		B5		2		Yes		No		9600		9615		0.1%	642 bytes	optiboot_flash_at90can32_UART1_9600_12000000L_B5_BIGBOOT.hex
11059200L	UART1		B5		2		Yes		No		460800		460800		0.0%	640 bytes	optiboot_flash_at90can32_UART1_460800_11059200L_B5_BIGBOOT.hex
11059200L	UART1		B5		2		Yes		No		230400		230400		0.0%	640 bytes	optiboot_flash_at90can32_UART1_230400_11059200L_B5_BIGBOOT.hex
11059200L	UART1		B5		2		Yes		No		115200		115200		0.0%	642 bytes	optiboot_flash_at90can32_UART1_115200_11059200L_B5_BIGBOOT.hex
11059200L	UART1		B5		2		Yes		No		57600		57600		0.0%	642 bytes	optiboot_flash_at90can32_UART1_57600_11059200L_B5_BIGBOOT.hex
11059200L	UART1		B5		2		Yes		No		38400		38400		0.0%	642 bytes	optiboot_flash_at90can32_UART1_38400_11059200L_B5_BIGBOOT.hex
11059200L	UART1		B5		2		Yes		No		19200		19200		0.0%	642 bytes	optiboot_flash_at90can32_UART1_19200_11059200L_B5_BIGBOOT.hex
11059200L	UART1		B5		2		Yes		No		9600		9600		0.0%	642 bytes	optiboot_flash_at90can32_UART1_9600_11059200L_B5_BIGBOOT.hex
8000000L	UART1		B5		2		Yes		No		1000000		1000000		0.0%	640 bytes	optiboot_flash_at90can32_UART1_1000000_8000000L_B5_BIGBOOT.hex
8000000L	UART1		B5		2		Yes		No		500000		500000		0.0%	642 bytes	optiboot_flash_at90can32_UART1_500000_8000000L_B5_BIGBOOT.hex
8000000L	UART1		B5		2		Yes		No		250000		250000		0.0%	642 bytes	optiboot_flash_at90can32_UART1_250000_8000000L_B5_BIGBOOT.hex
8000000L	UART1		B5		2		Yes		No		115200		111111		-3.5%	642 bytes	optiboot_flash_at90can32_UART1_115200_8000000L_B5_BIGBOOT.hex
8000000L	UART1		B5		2		Yes		No		57600		58823		2.1%	642 bytes	optiboot_flash_at90can32_UART1_57600_8000000L_B5_BIGBOOT.hex
8000000L	UART1		B5		2		Yes		No		38400		38461		0.1%	642 bytes	optiboot_flash_at90can32_UART1_38400_8000000L_B5_BIGBOOT.hex
8000000L	UART1		B5		2		Yes		No		19200		19230		0.1%	642 bytes	optiboot_flash_at90can32_UART1_19200_8000000L_B5_BIGBOOT.hex
8000000L	UART1		B5		2		Yes		No		9600		9615		0.1%	642 bytes	optiboot_flash_at90can32_UART1_9600_8000000L_B5_BIGBOOT.hex
7372800L	UART1		B5		2		Yes		No		460800		460800		0.0%	642 bytes	optiboot_flash_at90can32_UART1_460800_7372800L_B5_BIGBOOT.hex
7372800L	UART1		B5		2		Yes		No		230400		230400		0.0%	642 bytes	optiboot_flash_at90can32_UART1_230400_7372800L_B5_BIGBOOT.hex
7372800L	UART1		B5		2		Yes		No		115200		115200		0.0%	642 bytes	optiboot_flash_at90can32_UART1_115200_7372800L_B5_BIGBOOT.hex
7372800L	UART1		B5		2		Yes		No		57600		57600		0.0%	642 bytes	optiboot_flash_at90can32_UART1_57600_7372800L_B5_BIGBOOT.hex
7372800L	UART1		B5		2		Yes		No		38400		38400		0.0%	642 bytes	optiboot_flash_at90can32_UART1_38400_7372800L_B5_BIGBOOT.hex
7372800L	UART1		B5		2		Yes		No		19200		19200		0.0%	642 bytes	optiboot_flash_at90can32_UART1_19200_7372800L_B5_BIGBOOT.hex
7372800L	UART1		B5		2		Yes		No		9600		9600		0.0%	642 bytes	optiboot_flash_at90can32_UART1_9600_7372800L_B5_BIGBOOT.hex
4000000L	UART1		B5		2		Yes		No		500000		500000		0.0%	640 bytes	optiboot_flash_at90can32_UART1_500000_4000000L_B5_BIGBOOT.hex
4000000L	UART1		B5		2		Yes		No		250000		250000		0.0%	642 bytes	optiboot_flash_at90can32_UART1_250000_4000000L_B5_BIGBOOT.hex
4000000L	UART1		B5		2		Yes		No		19200		19230		0.1%	642 bytes	optiboot_flash_at90can32_UART1_19200_4000000L_B5_BIGBOOT.hex
4000000L	UART1		B5		2		Yes		No		9600		9615		0.1%	642 bytes	optiboot_flash_at90can32_UART1_9600_4000000L_B5_BIGBOOT.hex
3686400L	UART1		B5		2		Yes		No		460800		460800		0.0%	640 bytes	optiboot_flash_at90can32_UART1_460800_3686400L_B5_BIGBOOT.hex
3686400L	UART1		B5		2		Yes		No		230400		230400		0.0%	642 bytes	optiboot_flash_at90can32_UART1_230400_3686400L_B5_BIGBOOT.hex
3686400L	UART1		B5		2		Yes		No		115200		115200		0.0%	642 bytes	optiboot_flash_at90can32_UART1_115200_3686400L_B5_BIGBOOT.hex
3686400L	UART1		B5		2		Yes		No		57600		57600		0.0%	642 bytes	optiboot_flash_at90can32_UART1_57600_3686400L_B5_BIGBOOT.hex
3686400L	UART1		B5		2		Yes		No		38400		38400		0.0%	642 bytes	optiboot_flash_at90can32_UART1_38400_3686400L_B5_BIGBOOT.hex
3686400L	UART1		B5		2		Yes		No		19200		19200		0.0%	642 bytes	optiboot_flash_at90can32_UART1_19200_3686400L_B5_BIGBOOT.hex
3686400L	UART1		B5		2		Yes		No		9600		9600		0.0%	642 bytes	optiboot_flash_at90can32_UART1_9600_3686400L_B5_BIGBOOT.hex
2000000L	UART1		B5		2		Yes		No		250000		250000		0.0%	640 bytes	optiboot_flash_at90can32_UART1_250000_2000000L_B5_BIGBOOT.hex
2000000L	UART1		B5		2		Yes		No		19200		19230		0.1%	642 bytes	optiboot_flash_at90can32_UART1_19200_2000000L_B5_BIGBOOT.hex
2000000L	UART1		B5		2		Yes		No		9600		9615		0.1%	642 bytes	optiboot_flash_at90can32_UART1_9600_2000000L_B5_BIGBOOT.hex
1843200L	UART1		B5		2		Yes		No		230400		230400		0.0%	640 bytes	optiboot_flash_at90can32_UART1_230400_1843200L_B5_BIGBOOT.hex
1843200L	UART1		B5		2		Yes		No		115200		115200		0.0%	642 bytes	optiboot_flash_at90can32_UART1_115200_1843200L_B5_BIGBOOT.hex
1843200L	UART1		B5		2		Yes		No		57600		57600		0.0%	642 bytes	optiboot_flash_at90can32_UART1_57600_1843200L_B5_BIGBOOT.hex
1843200L	UART1		B5		2		Yes		No		38400		38400		0.0%	640 bytes	optiboot_flash_at90can32_UART1_38400_1843200L_B5_BIGBOOT.hex
1843200L	UART1		B5		2		Yes		No		19200		19200		0.0%	642 bytes	optiboot_flash_at90can32_UART1_19200_1843200L_B5_BIGBOOT.hex
1843200L	UART1		B5		2		Yes		No		9600		9600		0.0%	642 bytes	optiboot_flash_at90can32_UART1_9600_1843200L_B5_BIGBOOT.hex
1000000L	UART1		B5		2		Yes		No		9600		9615		0.1%	642 bytes	optiboot_flash_at90can32_UART1_9600_1000000L_B5_BIGBOOT.hex

Optiboot_flash build output for at90can32 
https://github.com/MCUdude/optiboot_flash 
Build date and time: 09.11.2019 21:25 
Compiler: avr-gcc 7.3.0
 
F_CPU:		UART NUMBER:	LED PIN:	LED FLASHES:	EEPROM SUPPORT:	FLASH PG COPY:	DESIRED BAUD:	ACTUAL BAUD:	ERROR:	COMPILED SIZE:	OUTPUT FILE:
12000000L	UART0		B5		2		Yes		No		115200		115384		0.1%	642 bytes	optiboot_flash_at90can32_UART0_115200_12000000L_B5_BIGBOOT.hex

Optiboot_flash build output for at90can32 
https://github.com/MCUdude/optiboot_flash 
Build date and time: 09.11.2019 21:25 
Compiler: avr-gcc 7.3.0
 
F_CPU:		UART NUMBER:	LED PIN:	LED FLASHES:	EEPROM SUPPORT:	FLASH PG COPY:	DESIRED BAUD:	ACTUAL BAUD:	ERROR:	COMPILED SIZE:	OUTPUT FILE:
12000000L	UART1		B5		2		Yes		No		115200		115384		0.1%	642 bytes	optiboot_flash_at90can32_UART1_115200_12000000L_B5_BIGBOOT.hex

Optiboot_flash build output for at90can32 
https://github.com/MCUdude/optiboot_flash 
Build date and time: 11.04.2020 15:34 
Compiler: avr-gcc 7.3.0
 
F_CPU:		UART NUMBER:	LED PIN:	LED FLASHES:	EEPROM SUPPORT:	FLASH PG COPY:	DESIRED BAUD:	ACTUAL BAUD:	ERROR:	COMPILED SIZE:	OUTPUT FILE:
24000000L	UART0		B5		2		Yes		No		1000000		1000000		0.0%	650 bytes	optiboot_flash_at90can32_UART0_1000000_24000000L_B5_BIGBOOT.hex
24000000L	UART0		B5		2		Yes		No		500000		500000		0.0%	650 bytes	optiboot_flash_at90can32_UART0_500000_24000000L_B5_BIGBOOT.hex
24000000L	UART0		B5		2		Yes		No		250000		250000		0.0%	652 bytes	optiboot_flash_at90can32_UART0_250000_24000000L_B5_BIGBOOT.hex
24000000L	UART0		B5		2		Yes		No		230400		230769		0.1%	652 bytes	optiboot_flash_at90can32_UART0_230400_24000000L_B5_BIGBOOT.hex
24000000L	UART0		B5		2		Yes		No		115200		115384		0.1%	652 bytes	optiboot_flash_at90can32_UART0_115200_24000000L_B5_BIGBOOT.hex
24000000L	UART0		B5		2		Yes		No		57600		57692		0.1%	652 bytes	optiboot_flash_at90can32_UART0_57600_24000000L_B5_BIGBOOT.hex
24000000L	UART0		B5		2		Yes		No		38400		38461		0.1%	652 bytes	optiboot_flash_at90can32_UART0_38400_24000000L_B5_BIGBOOT.hex
24000000L	UART0		B5		2		Yes		No		19200		19230		0.1%	652 bytes	optiboot_flash_at90can32_UART0_19200_24000000L_B5_BIGBOOT.hex
22118400L	UART0		B5		2		Yes		No		460800		460800		0.0%	650 bytes	optiboot_flash_at90can32_UART0_460800_22118400L_B5_BIGBOOT.hex
22118400L	UART0		B5		2		Yes		No		230400		230400		0.0%	652 bytes	optiboot_flash_at90can32_UART0_230400_22118400L_B5_BIGBOOT.hex
22118400L	UART0		B5		2		Yes		No		115200		115200		0.0%	652 bytes	optiboot_flash_at90can32_UART0_115200_22118400L_B5_BIGBOOT.hex
22118400L	UART0		B5		2		Yes		No		57600		57600		0.0%	652 bytes	optiboot_flash_at90can32_UART0_57600_22118400L_B5_BIGBOOT.hex
22118400L	UART0		B5		2		Yes		No		38400		38400		0.0%	652 bytes	optiboot_flash_at90can32_UART0_38400_22118400L_B5_BIGBOOT.hex
22118400L	UART0		B5		2		Yes		No		19200		19200		0.0%	652 bytes	optiboot_flash_at90can32_UART0_19200_22118400L_B5_BIGBOOT.hex
20000000L	UART0		B5		2		Yes		No		500000		500000		0.0%	652 bytes	optiboot_flash_at90can32_UART0_500000_20000000L_B5_BIGBOOT.hex
20000000L	UART0		B5		2		Yes		No		250000		250000		0.0%	652 bytes	optiboot_flash_at90can32_UART0_250000_20000000L_B5_BIGBOOT.hex
20000000L	UART0		B5		2		Yes		No		115200		113636		-1.3%	652 bytes	optiboot_flash_at90can32_UART0_115200_20000000L_B5_BIGBOOT.hex
20000000L	UART0		B5		2		Yes		No		19200		19230		0.1%	652 bytes	optiboot_flash_at90can32_UART0_19200_20000000L_B5_BIGBOOT.hex
18432000L	UART0		B5		2		Yes		No		460800		460800		0.0%	652 bytes	optiboot_flash_at90can32_UART0_460800_18432000L_B5_BIGBOOT.hex
18432000L	UART0		B5		2		Yes		No		230400		230400		0.0%	652 bytes	optiboot_flash_at90can32_UART0_230400_18432000L_B5_BIGBOOT.hex
18432000L	UART0		B5		2		Yes		No		115200		115200		0.0%	652 bytes	optiboot_flash_at90can32_UART0_115200_18432000L_B5_BIGBOOT.hex
18432000L	UART0		B5		2		Yes		No		57600		57600		0.0%	652 bytes	optiboot_flash_at90can32_UART0_57600_18432000L_B5_BIGBOOT.hex
18432000L	UART0		B5		2		Yes		No		38400		38400		0.0%	652 bytes	optiboot_flash_at90can32_UART0_38400_18432000L_B5_BIGBOOT.hex
18432000L	UART0		B5		2		Yes		No		19200		19200		0.0%	652 bytes	optiboot_flash_at90can32_UART0_19200_18432000L_B5_BIGBOOT.hex
18432000L	UART0		B5		2		Yes		No		9600		9600		0.0%	652 bytes	optiboot_flash_at90can32_UART0_9600_18432000L_B5_BIGBOOT.hex
16000000L	UART0		B5		2		Yes		No		1000000		1000000		0.0%	652 bytes	optiboot_flash_at90can32_UART0_1000000_16000000L_B5_BIGBOOT.hex
16000000L	UART0		B5		2		Yes		No		500000		500000		0.0%	652 bytes	optiboot_flash_at90can32_UART0_500000_16000000L_B5_BIGBOOT.hex
16000000L	UART0		B5		2		Yes		No		250000		250000		0.0%	652 bytes	optiboot_flash_at90can32_UART0_250000_16000000L_B5_BIGBOOT.hex
16000000L	UART0		B5		2		Yes		No		115200		117647		2.1%	652 bytes	optiboot_flash_at90can32_UART0_115200_16000000L_B5_BIGBOOT.hex
16000000L	UART0		B5		2		Yes		No		38400		38461		0.1%	652 bytes	optiboot_flash_at90can32_UART0_38400_16000000L_B5_BIGBOOT.hex
16000000L	UART0		B5		2		Yes		No		19200		19230		0.1%	652 bytes	optiboot_flash_at90can32_UART0_19200_16000000L_B5_BIGBOOT.hex
16000000L	UART0		B5		2		Yes		No		9600		9615		0.1%	652 bytes	optiboot_flash_at90can32_UART0_9600_16000000L_B5_BIGBOOT.hex
14745600L	UART0		B5		2		Yes		No		460800		460800		0.0%	652 bytes	optiboot_flash_at90can32_UART0_460800_14745600L_B5_BIGBOOT.hex
14745600L	UART0		B5		2		Yes		No		230400		230400		0.0%	652 bytes	optiboot_flash_at90can32_UART0_230400_14745600L_B5_BIGBOOT.hex
14745600L	UART0		B5		2		Yes		No		115200		115200		0.0%	652 bytes	optiboot_flash_at90can32_UART0_115200_14745600L_B5_BIGBOOT.hex
14745600L	UART0		B5		2		Yes		No		57600		57600		0.0%	652 bytes	optiboot_flash_at90can32_UART0_57600_14745600L_B5_BIGBOOT.hex
14745600L	UART0		B5		2		Yes		No		38400		38400		0.0%	652 bytes	optiboot_flash_at90can32_UART0_38400_14745600L_B5_BIGBOOT.hex
14745600L	UART0		B5		2		Yes		No		19200		19200		0.0%	652 bytes	optiboot_flash_at90can32_UART0_19200_14745600L_B5_BIGBOOT.hex
14745600L	UART0		B5		2		Yes		No		9600		9600		0.0%	652 bytes	optiboot_flash_at90can32_UART0_9600_14745600L_B5_BIGBOOT.hex
12000000L	UART0		B5		2		Yes		No		500000		500000		0.0%	650 bytes	optiboot_flash_at90can32_UART0_500000_12000000L_B5_BIGBOOT.hex
12000000L	UART0		B5		2		Yes		No		250000		250000		0.0%	650 bytes	optiboot_flash_at90can32_UART0_250000_12000000L_B5_BIGBOOT.hex
12000000L	UART0		B5		2		Yes		No		115200		115384		0.1%	652 bytes	optiboot_flash_at90can32_UART0_115200_12000000L_B5_BIGBOOT.hex
12000000L	UART0		B5		2		Yes		No		57600		57692		0.1%	652 bytes	optiboot_flash_at90can32_UART0_57600_12000000L_B5_BIGBOOT.hex
12000000L	UART0		B5		2		Yes		No		19200		19230		0.1%	652 bytes	optiboot_flash_at90can32_UART0_19200_12000000L_B5_BIGBOOT.hex
12000000L	UART0		B5		2		Yes		No		9600		9615		0.1%	652 bytes	optiboot_flash_at90can32_UART0_9600_12000000L_B5_BIGBOOT.hex
11059200L	UART0		B5		2		Yes		No		460800		460800		0.0%	650 bytes	optiboot_flash_at90can32_UART0_460800_11059200L_B5_BIGBOOT.hex
11059200L	UART0		B5		2		Yes		No		230400		230400		0.0%	650 bytes	optiboot_flash_at90can32_UART0_230400_11059200L_B5_BIGBOOT.hex
11059200L	UART0		B5		2		Yes		No		115200		115200		0.0%	652 bytes	optiboot_flash_at90can32_UART0_115200_11059200L_B5_BIGBOOT.hex
11059200L	UART0		B5		2		Yes		No		57600		57600		0.0%	652 bytes	optiboot_flash_at90can32_UART0_57600_11059200L_B5_BIGBOOT.hex
11059200L	UART0		B5		2		Yes		No		38400		38400		0.0%	652 bytes	optiboot_flash_at90can32_UART0_38400_11059200L_B5_BIGBOOT.hex
11059200L	UART0		B5		2		Yes		No		19200		19200		0.0%	652 bytes	optiboot_flash_at90can32_UART0_19200_11059200L_B5_BIGBOOT.hex
11059200L	UART0		B5		2		Yes		No		9600		9600		0.0%	652 bytes	optiboot_flash_at90can32_UART0_9600_11059200L_B5_BIGBOOT.hex
8000000L	UART0		B5		2		Yes		No		1000000		1000000		0.0%	650 bytes	optiboot_flash_at90can32_UART0_1000000_8000000L_B5_BIGBOOT.hex
8000000L	UART0		B5		2		Yes		No		500000		500000		0.0%	652 bytes	optiboot_flash_at90can32_UART0_500000_8000000L_B5_BIGBOOT.hex
8000000L	UART0		B5		2		Yes		No		250000		250000		0.0%	652 bytes	optiboot_flash_at90can32_UART0_250000_8000000L_B5_BIGBOOT.hex
8000000L	UART0		B5		2		Yes		No		115200		111111		-3.5%	652 bytes	optiboot_flash_at90can32_UART0_115200_8000000L_B5_BIGBOOT.hex
8000000L	UART0		B5		2		Yes		No		57600		58823		2.1%	652 bytes	optiboot_flash_at90can32_UART0_57600_8000000L_B5_BIGBOOT.hex
8000000L	UART0		B5		2		Yes		No		38400		38461		0.1%	652 bytes	optiboot_flash_at90can32_UART0_38400_8000000L_B5_BIGBOOT.hex
8000000L	UART0		B5		2		Yes		No		19200		19230		0.1%	652 bytes	optiboot_flash_at90can32_UART0_19200_8000000L_B5_BIGBOOT.hex
8000000L	UART0		B5		2		Yes		No		9600		9615		0.1%	652 bytes	optiboot_flash_at90can32_UART0_9600_8000000L_B5_BIGBOOT.hex
7372800L	UART0		B5		2		Yes		No		460800		460800		0.0%	652 bytes	optiboot_flash_at90can32_UART0_460800_7372800L_B5_BIGBOOT.hex
7372800L	UART0		B5		2		Yes		No		230400		230400		0.0%	652 bytes	optiboot_flash_at90can32_UART0_230400_7372800L_B5_BIGBOOT.hex
7372800L	UART0		B5		2		Yes		No		115200		115200		0.0%	652 bytes	optiboot_flash_at90can32_UART0_115200_7372800L_B5_BIGBOOT.hex
7372800L	UART0		B5		2		Yes		No		57600		57600		0.0%	652 bytes	optiboot_flash_at90can32_UART0_57600_7372800L_B5_BIGBOOT.hex
7372800L	UART0		B5		2		Yes		No		38400		38400		0.0%	652 bytes	optiboot_flash_at90can32_UART0_38400_7372800L_B5_BIGBOOT.hex
7372800L	UART0		B5		2		Yes		No		19200		19200		0.0%	652 bytes	optiboot_flash_at90can32_UART0_19200_7372800L_B5_BIGBOOT.hex
7372800L	UART0		B5		2		Yes		No		9600		9600		0.0%	652 bytes	optiboot_flash_at90can32_UART0_9600_7372800L_B5_BIGBOOT.hex
4000000L	UART0		B5		2		Yes		No		500000		500000		0.0%	650 bytes	optiboot_flash_at90can32_UART0_500000_4000000L_B5_BIGBOOT.hex
4000000L	UART0		B5		2		Yes		No		250000		250000		0.0%	652 bytes	optiboot_flash_at90can32_UART0_250000_4000000L_B5_BIGBOOT.hex
4000000L	UART0		B5		2		Yes		No		19200		19230		0.1%	652 bytes	optiboot_flash_at90can32_UART0_19200_4000000L_B5_BIGBOOT.hex
4000000L	UART0		B5		2		Yes		No		9600		9615		0.1%	652 bytes	optiboot_flash_at90can32_UART0_9600_4000000L_B5_BIGBOOT.hex
3686400L	UART0		B5		2		Yes		No		460800		460800		0.0%	650 bytes	optiboot_flash_at90can32_UART0_460800_3686400L_B5_BIGBOOT.hex
3686400L	UART0		B5		2		Yes		No		230400		230400		0.0%	652 bytes	optiboot_flash_at90can32_UART0_230400_3686400L_B5_BIGBOOT.hex
3686400L	UART0		B5		2		Yes		No		115200		115200		0.0%	652 bytes	optiboot_flash_at90can32_UART0_115200_3686400L_B5_BIGBOOT.hex
3686400L	UART0		B5		2		Yes		No		57600		57600		0.0%	652 bytes	optiboot_flash_at90can32_UART0_57600_3686400L_B5_BIGBOOT.hex
3686400L	UART0		B5		2		Yes		No		38400		38400		0.0%	652 bytes	optiboot_flash_at90can32_UART0_38400_3686400L_B5_BIGBOOT.hex
3686400L	UART0		B5		2		Yes		No		19200		19200		0.0%	652 bytes	optiboot_flash_at90can32_UART0_19200_3686400L_B5_BIGBOOT.hex
3686400L	UART0		B5		2		Yes		No		9600		9600		0.0%	652 bytes	optiboot_flash_at90can32_UART0_9600_3686400L_B5_BIGBOOT.hex
2000000L	UART0		B5		2		Yes		No		250000		250000		0.0%	650 bytes	optiboot_flash_at90can32_UART0_250000_2000000L_B5_BIGBOOT.hex
2000000L	UART0		B5		2		Yes		No		19200		19230		0.1%	652 bytes	optiboot_flash_at90can32_UART0_19200_2000000L_B5_BIGBOOT.hex
2000000L	UART0		B5		2		Yes		No		9600		9615		0.1%	652 bytes	optiboot_flash_at90can32_UART0_9600_2000000L_B5_BIGBOOT.hex
1843200L	UART0		B5		2		Yes		No		230400		230400		0.0%	650 bytes	optiboot_flash_at90can32_UART0_230400_1843200L_B5_BIGBOOT.hex
1843200L	UART0		B5		2		Yes		No		115200		115200		0.0%	652 bytes	optiboot_flash_at90can32_UART0_115200_1843200L_B5_BIGBOOT.hex
1843200L	UART0		B5		2		Yes		No		57600		57600		0.0%	652 bytes	optiboot_flash_at90can32_UART0_57600_1843200L_B5_BIGBOOT.hex
1843200L	UART0		B5		2		Yes		No		38400		38400		0.0%	650 bytes	optiboot_flash_at90can32_UART0_38400_1843200L_B5_BIGBOOT.hex
1843200L	UART0		B5		2		Yes		No		19200		19200		0.0%	652 bytes	optiboot_flash_at90can32_UART0_19200_1843200L_B5_BIGBOOT.hex
1843200L	UART0		B5		2		Yes		No		9600		9600		0.0%	652 bytes	optiboot_flash_at90can32_UART0_9600_1843200L_B5_BIGBOOT.hex
1000000L	UART0		B5		2		Yes		No		9600		9615		0.1%	652 bytes	optiboot_flash_at90can32_UART0_9600_1000000L_B5_BIGBOOT.hex

Optiboot_flash build output for at90can32 
https://github.com/MCUdude/optiboot_flash 
Build date and time: 11.04.2020 15:34 
Compiler: avr-gcc 7.3.0
 
F_CPU:		UART NUMBER:	LED PIN:	LED FLASHES:	EEPROM SUPPORT:	FLASH PG COPY:	DESIRED BAUD:	ACTUAL BAUD:	ERROR:	COMPILED SIZE:	OUTPUT FILE:
24000000L	UART1		B5		2		Yes		No		1000000		1000000		0.0%	650 bytes	optiboot_flash_at90can32_UART1_1000000_24000000L_B5_BIGBOOT.hex
24000000L	UART1		B5		2		Yes		No		500000		500000		0.0%	650 bytes	optiboot_flash_at90can32_UART1_500000_24000000L_B5_BIGBOOT.hex
24000000L	UART1		B5		2		Yes		No		250000		250000		0.0%	652 bytes	optiboot_flash_at90can32_UART1_250000_24000000L_B5_BIGBOOT.hex
24000000L	UART1		B5		2		Yes		No		230400		230769		0.1%	652 bytes	optiboot_flash_at90can32_UART1_230400_24000000L_B5_BIGBOOT.hex
24000000L	UART1		B5		2		Yes		No		115200		115384		0.1%	652 bytes	optiboot_flash_at90can32_UART1_115200_24000000L_B5_BIGBOOT.hex
24000000L	UART1		B5		2		Yes		No		57600		57692		0.1%	652 bytes	optiboot_flash_at90can32_UART1_57600_24000000L_B5_BIGBOOT.hex
24000000L	UART1		B5		2		Yes		No		38400		38461		0.1%	652 bytes	optiboot_flash_at90can32_UART1_38400_24000000L_B5_BIGBOOT.hex
24000000L	UART1		B5		2		Yes		No		19200		19230		0.1%	652 bytes	optiboot_flash_at90can32_UART1_19200_24000000L_B5_BIGBOOT.hex
22118400L	UART1		B5		2		Yes		No		460800		460800		0.0%	650 bytes	optiboot_flash_at90can32_UART1_460800_22118400L_B5_BIGBOOT.hex
22118400L	UART1		B5		2		Yes		No		230400		230400		0.0%	652 bytes	optiboot_flash_at90can32_UART1_230400_22118400L_B5_BIGBOOT.hex
22118400L	UART1		B5		2		Yes		No		115200		115200		0.0%	652 bytes	optiboot_flash_at90can32_UART1_115200_22118400L_B5_BIGBOOT.hex
22118400L	UART1		B5		2		Yes		No		57600		57600		0.0%	652 bytes	optiboot_flash_at90can32_UART1_57600_22118400L_B5_BIGBOOT.hex
22118400L	UART1		B5		2		Yes		No		38400		38400		0.0%	652 bytes	optiboot_flash_at90can32_UART1_38400_22118400L_B5_BIGBOOT.hex
22118400L	UART1		B5		2		Yes		No		19200		19200		0.0%	652 bytes	optiboot_flash_at90can32_UART1_19200_22118400L_B5_BIGBOOT.hex
20000000L	UART1		B5		2		Yes		No		500000		500000		0.0%	652 bytes	optiboot_flash_at90can32_UART1_500000_20000000L_B5_BIGBOOT.hex
20000000L	UART1		B5		2		Yes		No		250000		250000		0.0%	652 bytes	optiboot_flash_at90can32_UART1_250000_20000000L_B5_BIGBOOT.hex
20000000L	UART1		B5		2		Yes		No		115200		113636		-1.3%	652 bytes	optiboot_flash_at90can32_UART1_115200_20000000L_B5_BIGBOOT.hex
20000000L	UART1		B5		2		Yes		No		19200		19230		0.1%	652 bytes	optiboot_flash_at90can32_UART1_19200_20000000L_B5_BIGBOOT.hex
18432000L	UART1		B5		2		Yes		No		460800		460800		0.0%	652 bytes	optiboot_flash_at90can32_UART1_460800_18432000L_B5_BIGBOOT.hex
18432000L	UART1		B5		2		Yes		No		230400		230400		0.0%	652 bytes	optiboot_flash_at90can32_UART1_230400_18432000L_B5_BIGBOOT.hex
18432000L	UART1		B5		2		Yes		No		115200		115200		0.0%	652 bytes	optiboot_flash_at90can32_UART1_115200_18432000L_B5_BIGBOOT.hex
18432000L	UART1		B5		2		Yes		No		57600		57600		0.0%	652 bytes	optiboot_flash_at90can32_UART1_57600_18432000L_B5_BIGBOOT.hex
18432000L	UART1		B5		2		Yes		No		38400		38400		0.0%	652 bytes	optiboot_flash_at90can32_UART1_38400_18432000L_B5_BIGBOOT.hex
18432000L	UART1		B5		2		Yes		No		19200		19200		0.0%	652 bytes	optiboot_flash_at90can32_UART1_19200_18432000L_B5_BIGBOOT.hex
18432000L	UART1		B5		2		Yes		No		9600		9600		0.0%	652 bytes	optiboot_flash_at90can32_UART1_9600_18432000L_B5_BIGBOOT.hex
16000000L	UART1		B5		2		Yes		No		1000000		1000000		0.0%	652 bytes	optiboot_flash_at90can32_UART1_1000000_16000000L_B5_BIGBOOT.hex
16000000L	UART1		B5		2		Yes		No		500000		500000		0.0%	652 bytes	optiboot_flash_at90can32_UART1_500000_16000000L_B5_BIGBOOT.hex
16000000L	UART1		B5		2		Yes		No		250000		250000		0.0%	652 bytes	optiboot_flash_at90can32_UART1_250000_16000000L_B5_BIGBOOT.hex
16000000L	UART1		B5		2		Yes		No		115200		117647		2.1%	652 bytes	optiboot_flash_at90can32_UART1_115200_16000000L_B5_BIGBOOT.hex
16000000L	UART1		B5		2		Yes		No		38400		38461		0.1%	652 bytes	optiboot_flash_at90can32_UART1_38400_16000000L_B5_BIGBOOT.hex
16000000L	UART1		B5		2		Yes		No		19200		19230		0.1%	652 bytes	optiboot_flash_at90can32_UART1_19200_16000000L_B5_BIGBOOT.hex
16000000L	UART1		B5		2		Yes		No		9600		9615		0.1%	652 bytes	optiboot_flash_at90can32_UART1_9600_16000000L_B5_BIGBOOT.hex
14745600L	UART1		B5		2		Yes		No		460800		460800		0.0%	652 bytes	optiboot_flash_at90can32_UART1_460800_14745600L_B5_BIGBOOT.hex
14745600L	UART1		B5		2		Yes		No		230400		230400		0.0%	652 bytes	optiboot_flash_at90can32_UART1_230400_14745600L_B5_BIGBOOT.hex
14745600L	UART1		B5		2		Yes		No		115200		115200		0.0%	652 bytes	optiboot_flash_at90can32_UART1_115200_14745600L_B5_BIGBOOT.hex
14745600L	UART1		B5		2		Yes		No		57600		57600		0.0%	652 bytes	optiboot_flash_at90can32_UART1_57600_14745600L_B5_BIGBOOT.hex
14745600L	UART1		B5		2		Yes		No		38400		38400		0.0%	652 bytes	optiboot_flash_at90can32_UART1_38400_14745600L_B5_BIGBOOT.hex
14745600L	UART1		B5		2		Yes		No		19200		19200		0.0%	652 bytes	optiboot_flash_at90can32_UART1_19200_14745600L_B5_BIGBOOT.hex
14745600L	UART1		B5		2		Yes		No		9600		9600		0.0%	652 bytes	optiboot_flash_at90can32_UART1_9600_14745600L_B5_BIGBOOT.hex
12000000L	UART1		B5		2		Yes		No		500000		500000		0.0%	650 bytes	optiboot_flash_at90can32_UART1_500000_12000000L_B5_BIGBOOT.hex
12000000L	UART1		B5		2		Yes		No		250000		250000		0.0%	650 bytes	optiboot_flash_at90can32_UART1_250000_12000000L_B5_BIGBOOT.hex
12000000L	UART1		B5		2		Yes		No		115200		115384		0.1%	652 bytes	optiboot_flash_at90can32_UART1_115200_12000000L_B5_BIGBOOT.hex
12000000L	UART1		B5		2		Yes		No		57600		57692		0.1%	652 bytes	optiboot_flash_at90can32_UART1_57600_12000000L_B5_BIGBOOT.hex
12000000L	UART1		B5		2		Yes		No		19200		19230		0.1%	652 bytes	optiboot_flash_at90can32_UART1_19200_12000000L_B5_BIGBOOT.hex
12000000L	UART1		B5		2		Yes		No		9600		9615		0.1%	652 bytes	optiboot_flash_at90can32_UART1_9600_12000000L_B5_BIGBOOT.hex
11059200L	UART1		B5		2		Yes		No		460800		460800		0.0%	650 bytes	optiboot_flash_at90can32_UART1_460800_11059200L_B5_BIGBOOT.hex
11059200L	UART1		B5		2		Yes		No		230400		230400		0.0%	650 bytes	optiboot_flash_at90can32_UART1_230400_11059200L_B5_BIGBOOT.hex
11059200L	UART1		B5		2		Yes		No		115200		115200		0.0%	652 bytes	optiboot_flash_at90can32_UART1_115200_11059200L_B5_BIGBOOT.hex
11059200L	UART1		B5		2		Yes		No		57600		57600		0.0%	652 bytes	optiboot_flash_at90can32_UART1_57600_11059200L_B5_BIGBOOT.hex
11059200L	UART1		B5		2		Yes		No		38400		38400		0.0%	652 bytes	optiboot_flash_at90can32_UART1_38400_11059200L_B5_BIGBOOT.hex
11059200L	UART1		B5		2		Yes		No		19200		19200		0.0%	652 bytes	optiboot_flash_at90can32_UART1_19200_11059200L_B5_BIGBOOT.hex
11059200L	UART1		B5		2		Yes		No		9600		9600		0.0%	652 bytes	optiboot_flash_at90can32_UART1_9600_11059200L_B5_BIGBOOT.hex
8000000L	UART1		B5		2		Yes		No		1000000		1000000		0.0%	650 bytes	optiboot_flash_at90can32_UART1_1000000_8000000L_B5_BIGBOOT.hex
8000000L	UART1		B5		2		Yes		No		500000		500000		0.0%	652 bytes	optiboot_flash_at90can32_UART1_500000_8000000L_B5_BIGBOOT.hex
8000000L	UART1		B5		2		Yes		No		250000		250000		0.0%	652 bytes	optiboot_flash_at90can32_UART1_250000_8000000L_B5_BIGBOOT.hex
8000000L	UART1		B5		2		Yes		No		115200		111111		-3.5%	652 bytes	optiboot_flash_at90can32_UART1_115200_8000000L_B5_BIGBOOT.hex
8000000L	UART1		B5		2		Yes		No		57600		58823		2.1%	652 bytes	optiboot_flash_at90can32_UART1_57600_8000000L_B5_BIGBOOT.hex
8000000L	UART1		B5		2		Yes		No		38400		38461		0.1%	652 bytes	optiboot_flash_at90can32_UART1_38400_8000000L_B5_BIGBOOT.hex
8000000L	UART1		B5		2		Yes		No		19200		19230		0.1%	652 bytes	optiboot_flash_at90can32_UART1_19200_8000000L_B5_BIGBOOT.hex
8000000L	UART1		B5		2		Yes		No		9600		9615		0.1%	652 bytes	optiboot_flash_at90can32_UART1_9600_8000000L_B5_BIGBOOT.hex
7372800L	UART1		B5		2		Yes		No		460800		460800		0.0%	652 bytes	optiboot_flash_at90can32_UART1_460800_7372800L_B5_BIGBOOT.hex
7372800L	UART1		B5		2		Yes		No		230400		230400		0.0%	652 bytes	optiboot_flash_at90can32_UART1_230400_7372800L_B5_BIGBOOT.hex
7372800L	UART1		B5		2		Yes		No		115200		115200		0.0%	652 bytes	optiboot_flash_at90can32_UART1_115200_7372800L_B5_BIGBOOT.hex
7372800L	UART1		B5		2		Yes		No		57600		57600		0.0%	652 bytes	optiboot_flash_at90can32_UART1_57600_7372800L_B5_BIGBOOT.hex
7372800L	UART1		B5		2		Yes		No		38400		38400		0.0%	652 bytes	optiboot_flash_at90can32_UART1_38400_7372800L_B5_BIGBOOT.hex
7372800L	UART1		B5		2		Yes		No		19200		19200		0.0%	652 bytes	optiboot_flash_at90can32_UART1_19200_7372800L_B5_BIGBOOT.hex
7372800L	UART1		B5		2		Yes		No		9600		9600		0.0%	652 bytes	optiboot_flash_at90can32_UART1_9600_7372800L_B5_BIGBOOT.hex
4000000L	UART1		B5		2		Yes		No		500000		500000		0.0%	650 bytes	optiboot_flash_at90can32_UART1_500000_4000000L_B5_BIGBOOT.hex
4000000L	UART1		B5		2		Yes		No		250000		250000		0.0%	652 bytes	optiboot_flash_at90can32_UART1_250000_4000000L_B5_BIGBOOT.hex
4000000L	UART1		B5		2		Yes		No		19200		19230		0.1%	652 bytes	optiboot_flash_at90can32_UART1_19200_4000000L_B5_BIGBOOT.hex
4000000L	UART1		B5		2		Yes		No		9600		9615		0.1%	652 bytes	optiboot_flash_at90can32_UART1_9600_4000000L_B5_BIGBOOT.hex
3686400L	UART1		B5		2		Yes		No		460800		460800		0.0%	650 bytes	optiboot_flash_at90can32_UART1_460800_3686400L_B5_BIGBOOT.hex
3686400L	UART1		B5		2		Yes		No		230400		230400		0.0%	652 bytes	optiboot_flash_at90can32_UART1_230400_3686400L_B5_BIGBOOT.hex
3686400L	UART1		B5		2		Yes		No		115200		115200		0.0%	652 bytes	optiboot_flash_at90can32_UART1_115200_3686400L_B5_BIGBOOT.hex
3686400L	UART1		B5		2		Yes		No		57600		57600		0.0%	652 bytes	optiboot_flash_at90can32_UART1_57600_3686400L_B5_BIGBOOT.hex
3686400L	UART1		B5		2		Yes		No		38400		38400		0.0%	652 bytes	optiboot_flash_at90can32_UART1_38400_3686400L_B5_BIGBOOT.hex
3686400L	UART1		B5		2		Yes		No		19200		19200		0.0%	652 bytes	optiboot_flash_at90can32_UART1_19200_3686400L_B5_BIGBOOT.hex
3686400L	UART1		B5		2		Yes		No		9600		9600		0.0%	652 bytes	optiboot_flash_at90can32_UART1_9600_3686400L_B5_BIGBOOT.hex
2000000L	UART1		B5		2		Yes		No		250000		250000		0.0%	650 bytes	optiboot_flash_at90can32_UART1_250000_2000000L_B5_BIGBOOT.hex
2000000L	UART1		B5		2		Yes		No		19200		19230		0.1%	652 bytes	optiboot_flash_at90can32_UART1_19200_2000000L_B5_BIGBOOT.hex
2000000L	UART1		B5		2		Yes		No		9600		9615		0.1%	652 bytes	optiboot_flash_at90can32_UART1_9600_2000000L_B5_BIGBOOT.hex
1843200L	UART1		B5		2		Yes		No		230400		230400		0.0%	650 bytes	optiboot_flash_at90can32_UART1_230400_1843200L_B5_BIGBOOT.hex
1843200L	UART1		B5		2		Yes		No		115200		115200		0.0%	652 bytes	optiboot_flash_at90can32_UART1_115200_1843200L_B5_BIGBOOT.hex
1843200L	UART1		B5		2		Yes		No		57600		57600		0.0%	652 bytes	optiboot_flash_at90can32_UART1_57600_1843200L_B5_BIGBOOT.hex
1843200L	UART1		B5		2		Yes		No		38400		38400		0.0%	650 bytes	optiboot_flash_at90can32_UART1_38400_1843200L_B5_BIGBOOT.hex
1843200L	UART1		B5		2		Yes		No		19200		19200		0.0%	652 bytes	optiboot_flash_at90can32_UART1_19200_1843200L_B5_BIGBOOT.hex
1843200L	UART1		B5		2		Yes		No		9600		9600		0.0%	652 bytes	optiboot_flash_at90can32_UART1_9600_1843200L_B5_BIGBOOT.hex
1000000L	UART1		B5		2		Yes		No		9600		9615		0.1%	652 bytes	optiboot_flash_at90can32_UART1_9600_1000000L_B5_BIGBOOT.hex

Optiboot_flash build output for at90can32 
https://github.com/MCUdude/optiboot_flash 
Build date and time: 27.05.2020 07:53 
Compiler: avr-gcc 7.3.0
 
F_CPU:		UART NUMBER:	LED PIN:	LED FLASHES:	EEPROM SUPPORT:	FLASH PG COPY:	DESIRED BAUD:	ACTUAL BAUD:	ERROR:	COMPILED SIZE:	OUTPUT FILE:
1000000L	UART0		B5		2		Yes		No		9600		9615		0.1%	642 bytes	optiboot_flash_at90can32_UART0_9600_1000000L_B5_BIGBOOT.hex

Optiboot_flash build output for at90can32 
https://github.com/MCUdude/optiboot_flash 
Build date and time: 27.05.2020 07:53 
Compiler: avr-gcc 7.3.0
 
F_CPU:		UART NUMBER:	LED PIN:	LED FLASHES:	EEPROM SUPPORT:	FLASH PG COPY:	DESIRED BAUD:	ACTUAL BAUD:	ERROR:	COMPILED SIZE:	OUTPUT FILE:
1000000L	UART1		B5		2		Yes		No		9600		9615		0.1%	642 bytes	optiboot_flash_at90can32_UART1_9600_1000000L_B5_BIGBOOT.hex

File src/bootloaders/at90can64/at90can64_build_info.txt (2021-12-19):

Optiboot_flash build output for at90can64 
https://github.com/MCUdude/optiboot_flash 
Build date and time: 15.05.2019 23:28 
Compiler: avr-gcc 5.4.0
 
F_CPU:		UART NUMBER:	LED PIN:	LED FLASHES:	EEPROM SUPPORT:	FLASH PG COPY:	DESIRED BAUD:	ACTUAL BAUD:	ERROR:	COMPILED SIZE:	OUTPUT FILE:
24000000L	UART0		B5		2		Yes		No		1000000		1000000		0.0%	636 bytes	optiboot_flash_at90can64_UART0_1000000_24000000L_BIGBOOT.hex
24000000L	UART0		B5		2		Yes		No		500000		500000		0.0%	636 bytes	optiboot_flash_at90can64_UART0_500000_24000000L_BIGBOOT.hex
24000000L	UART0		B5		2		Yes		No		250000		250000		0.0%	638 bytes	optiboot_flash_at90can64_UART0_250000_24000000L_BIGBOOT.hex
24000000L	UART0		B5		2		Yes		No		230400		230769		0.1%	638 bytes	optiboot_flash_at90can64_UART0_230400_24000000L_BIGBOOT.hex
24000000L	UART0		B5		2		Yes		No		115200		115384		0.1%	638 bytes	optiboot_flash_at90can64_UART0_115200_24000000L_BIGBOOT.hex
24000000L	UART0		B5		2		Yes		No		57600		57692		0.1%	638 bytes	optiboot_flash_at90can64_UART0_57600_24000000L_BIGBOOT.hex
24000000L	UART0		B5		2		Yes		No		38400		38461		0.1%	638 bytes	optiboot_flash_at90can64_UART0_38400_24000000L_BIGBOOT.hex
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

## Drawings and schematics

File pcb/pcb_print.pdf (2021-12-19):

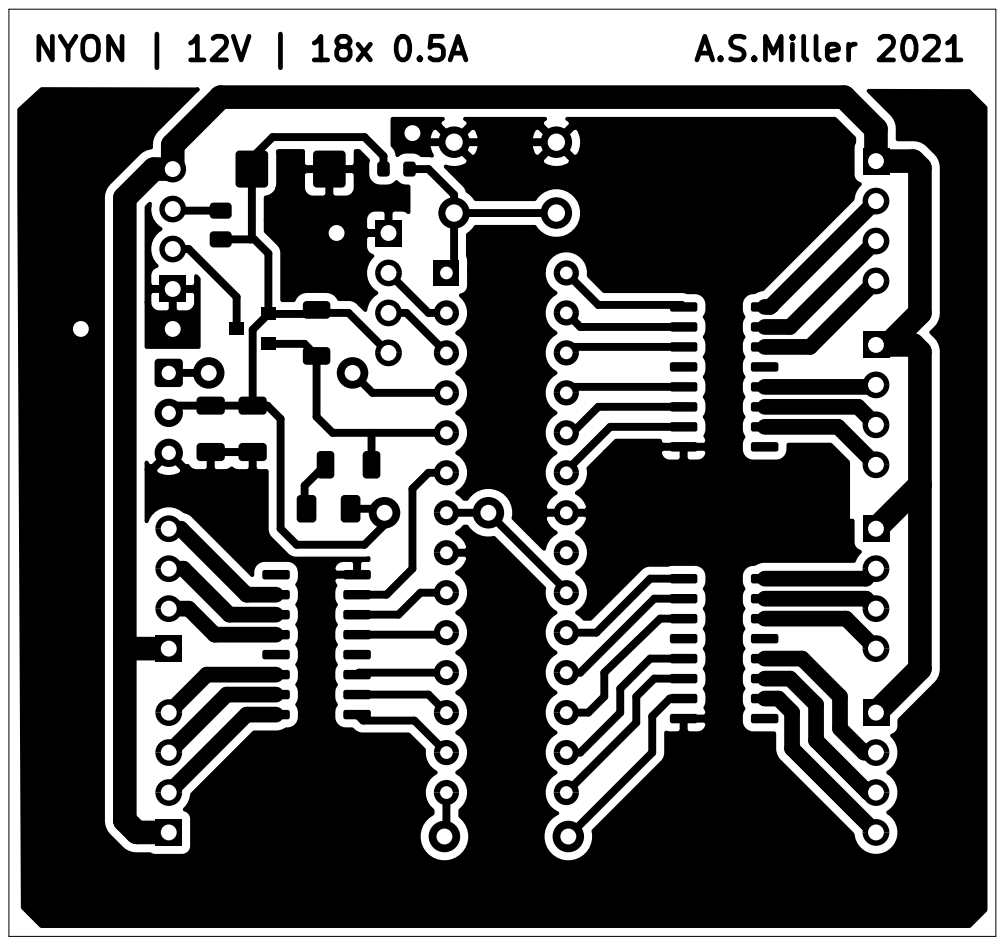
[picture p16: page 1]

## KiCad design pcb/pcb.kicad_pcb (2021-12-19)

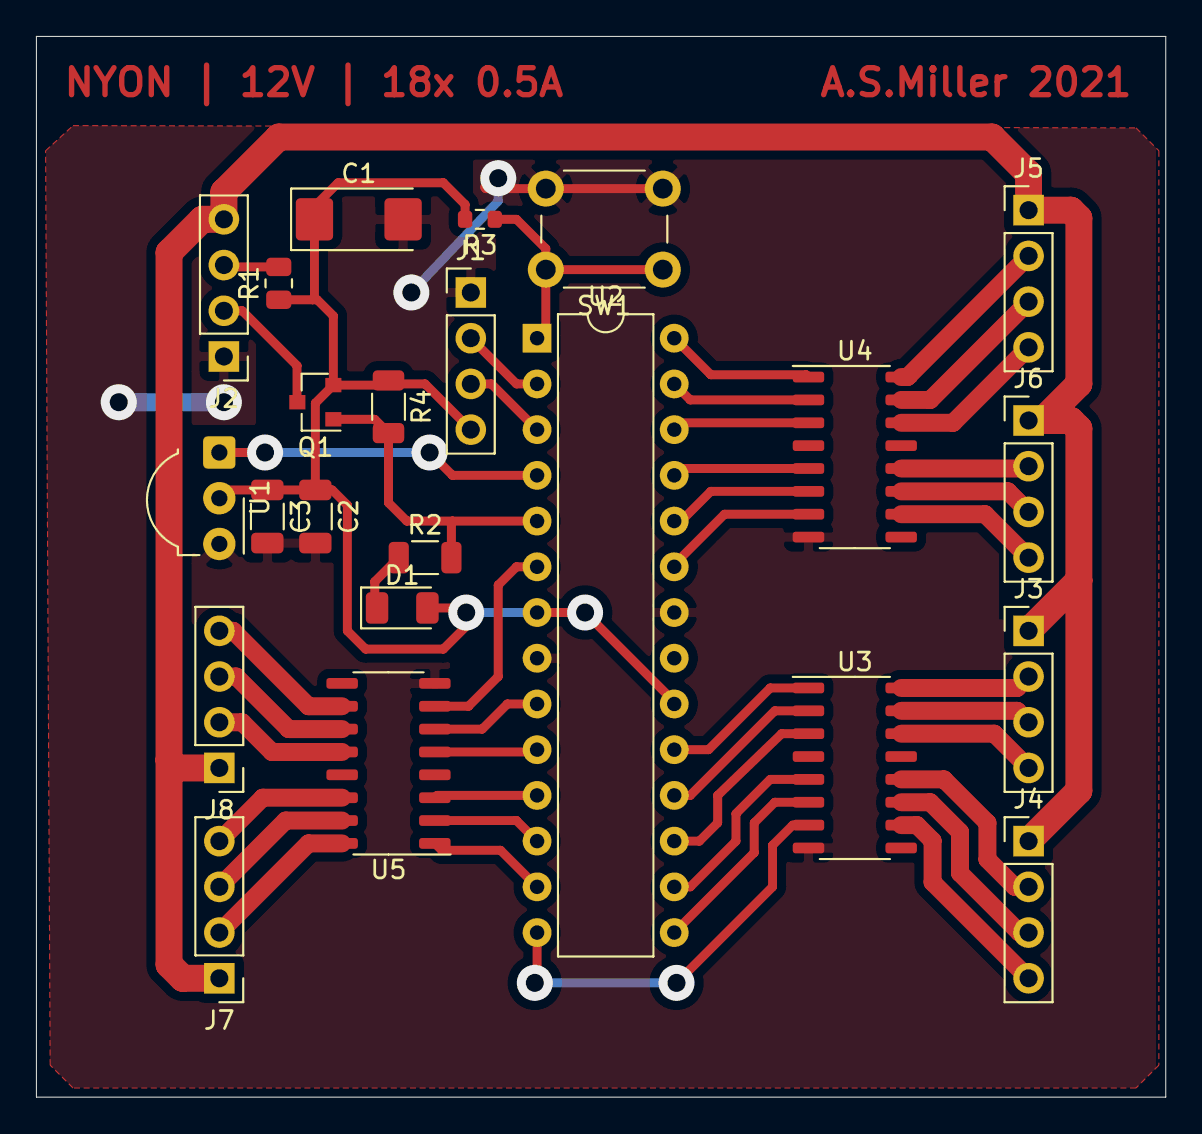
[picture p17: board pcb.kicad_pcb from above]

Board: 2 copper layers, 62.7 x 58.9 mm, 23 parts (0 on the bottom side), 47 nets.

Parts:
C1: 470uF; CP_EIA-6032-20_AVX-F
C2, C3: CP; C_1206_3216Metric
D1: LED; LED_1206_3216Metric
J1, J2, J3, J4, J5, J6, J7, J8: Conn_01x04_Female; PinHeader_1x04_P2.54mm_Vertical
Q1: Q_PMOS_GSD; SOT-23
R1: 4.7; R_0805_2012Metric
R2: 1.8k; R_1206_3216Metric
R3: 10k; R_0603_1608Metric
R4: 1k; R_1206_3216Metric
SW1: SW_SPST; SW_PUSH_6mm_H4.3mm
U1: TSOP21xx; Vishay_MOLD-3Pin
U2: ATmega168PA-PU; DIP-28_W7.62mm
U3, U4, U5: ULN2003; SO-16_3.9x9.9mm_P1.27mm

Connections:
5VDC: C1.1, C2.1, C3.1, D1.2, J1.4, Q1.2, R1.1, R3.2, R4.1, U1.2, U2.7, U2.20
+5V: J2.3, R1.2
+12V: J2.4, J3.1, J4.1, J5.1, J6.1, J7.1, J8.1
GND: C1.2, C2.2, C3.2, J1.1, J2.1, SW1.2, U1.3, U2.8, U2.22, U3.8, U4.8, U5.8
IR: U1.1, U2.4
unnamed: D1.1, R2.1
unnamed: J3.2, U3.16
unnamed: J3.3, U3.15
unnamed: J3.4, U3.14
unnamed: J4.2, U3.12
unnamed: J4.3, U3.11
unnamed: J4.4, U3.10
unnamed: J5.2, U4.16
unnamed: J5.3, U4.15
unnamed: J5.4, U4.14
unnamed: J6.2, U4.12
unnamed: J6.3, U4.11
unnamed: J6.4, U4.10
unnamed: J7.2, U5.16
unnamed: J7.3, U5.15
unnamed: J7.4, U5.14
unnamed: J8.2, U5.12
unnamed: J8.3, U5.11
unnamed: J8.4, U5.10
unnamed: U2.6, U5.7
unnamed: U2.9, U5.6
unnamed: U2.10, U5.5
unnamed: U2.11, U5.3
unnamed: U2.12, U5.2
unnamed: U2.13, U5.1
unnamed: U2.14, U3.7
unnamed: U2.15, U3.6
unnamed: U2.16, U3.5
unnamed: U2.17, U3.3
unnamed: U2.18, U3.2
unnamed: U2.19, U3.1
unnamed: U2.23, U4.7
unnamed: U2.24, U4.6
unnamed: U2.25, U4.5
unnamed: U2.26, U4.3
unnamed: U2.27, U4.2
unnamed: U2.28, U4.1
PWR: J2.2, Q1.3
PWR_EN: Q1.1, R2.2, R4.2, U2.5
RST: R3.1, SW1.1, U2.1
RXD: J1.3, U2.3
TXD: J1.2, U2.2

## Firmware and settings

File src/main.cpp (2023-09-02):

#include <avr/io.h>
#include <avr/interrupt.h>
#include "ir_receiver.h"
#include "ir_buttons.h"
#include "fast_timer.h"
#include "color.h"

//device address
#define DEV_ADDR 0x00
//dimming to 50%
#define DEV_DIMM

#define FLAG_MODIFIER 0x80
#define FLAG_INDEX 0x0F

//software pwm function
static void softpwm();
//color calculator
static void coloriser(bool reset = 0);
//ir remote driver
static void receiver();
//power supply manager
void powermanager();

/*
Making color ports local
is not viable with the current
program structure.
*/

//color ports to write to
color24 p1; //TEXT 
color24 p2; //GARNISH
color24 p3; //GLASS
color24 p4; //FLAMINGO
color24 p5; //LEAVES
color24 p6; //STUMP

uint8_t PWR_ON = 0xFF;
void (*mode_exe)(uint16_t, uint8_t, color24*);
uint16_t animlen = 0;
uint8_t FLAGS = 0x00;

void setup()
{
	//setting correct pin modes
	DDRB = 0b11111111;
	DDRC = 0b11111111;
	DDRD = 0b11111010;
	//ir receiver setup
	init_receiver();
	//start timing
	tm_init();
	//prepare power supply
	powermanager();
	//set default animation
	mode_exe = &neon_scheme;
	//reset the timer
	tm_reset();
}

int main()
{
	//setup routine
	setup();
	//program loop
	while(1)
	{	
		
		if(PWR_ON) 
		{
			//pwm driving task
			softpwm();
		}
		//runs every 25ms
		if(tm_ms() > 25)
		{
			//reset timing
			tm_reset();
			//ir control task
			receiver();
			//color calculation task
			if(PWR_ON) coloriser();
		}
	}
	return 0;
}

void powermanager()
{
	if(PWR_ON)
	{
		//disable the device
		PWR_ON = 0x00;
		PORTB = 0x00;
		PORTC = 0x00;
		PORTD = 0x08;
	}
	else
	{
		//enable the device
		PWR_ON = 0xFF;
		PORTD = 0x00;
		//halt program, wait for capactitors
		//to charge up and provide stable power
		tm_halt(250);
	}
}

void softpwm()
{
	//software counters
	static uint8_t tm_val = 0;
	static uint8_t tm_half = 0;
	//value used as output compare
	uint8_t tmr = 0;
	#ifdef DEV_DIMM
	//swap between 255 and tmr_val for dimming
	tmr = ~(tm_val&tm_half);
	#else
	tmr = tm_val;
	#endif
	PORTB =
	(tmr<p6.b) | (tmr<p6.r) << 1 | (tmr<p6.g) << 2 |      //STUMP
	(tmr<p1.b) << 3 | (tmr<p1.r) << 4 | (tmr<p1.g) << 5 | //LOUNGE
	(tmr<p4.r) << 6 | (tmr<p4.g) << 7;		      //FLAMINGO (R,G)
	PORTC =
	(tmr<p2.b) | (tmr<p2.r) << 1 | (tmr<p2.g) << 2 |      //GARNISH
	(tmr<p3.b) << 3 | (tmr<p3.r) << 4 | (tmr<p3.g) << 5;  //GLASS
	PORTD =
	(1<<2) | (tmr<p4.b) << 4 |		              //FLAMINGO (B)
	(tmr<p5.b) << 5 | (tmr<p5.r) << 6 | (tmr<p5.g) << 7;  //LEAVES
	//incrementing and overflow counting
	if(tm_val == 0xFF) tm_half ^= 0xFF;
	tm_val++;
}

void coloriser(bool reset)
{
	//animation scroller
	static uint16_t animtimer = 0x00;
	if(reset)
	{
		animtimer = 0x00;
		return;
	}	
	animtimer >= animlen ? animtimer = 0 : animtimer++;

	//apply colors to the outputs
	if(FLAGS & FLAG_MODIFIER) {
		color24 temp;
		static_color(FLAGS & FLAG_INDEX, &temp);

		p1 = temp;
		p2 = temp;
		p3 = temp;
		p4 = temp;
		p5 = temp;
		p6 = temp;

		return;
	}

	mode_exe(animtimer, channel6, &p6);
	mode_exe(animtimer, channel5, &p5);
	mode_exe(animtimer, channel4, &p4);
	mode_exe(animtimer, channel3, &p3);
	mode_exe(animtimer, channel2, &p2);
	mode_exe(animtimer, channel1, &p1);
}

void set_color_index(uint8_t index, uint8_t *flags)
{
	uint8_t temp = *flags;
	temp &=~ FLAG_INDEX;
	temp |= index;
	*flags = temp;
}

void receiver()
{
	//ir communication tasks
	struct IR_Packet recvd;
	//check for new packets
	cli();
	uint8_t recvs = check_new_packet(&recvd);
	sei();
	//if nothing is received, quit function
	if(!recvs) return;
	//check address first
	if(recvd.addr != DEV_ADDR) return;
	//check if power is even on
	if(!PWR_ON && recvd.command != POWR_B) return;
	uint8_t modifier = FLAGS & FLAG_MODIFIER;
	//interpret which action to take
	switch(recvd.command)
	{
		case POWR_B:
			//power switch
			if(recvd.repeat) break;
			powermanager();
			break;
		case MENU_B:
			if(recvd.repeat) break;
			FLAGS ^= FLAG_MODIFIER;
			break;
		case NUM0_B:
			//static neon scheme
			if(modifier) {
				set_color_index(0, &FLAGS);
			} else {
				mode_exe = &neon_scheme;
			}
			break;
		case LTRC_B:
			//blinking neon parts
			if(!modifier) {
				animlen = 380;
				mode_exe = &neon_blink;
			}
			break;
		case NUM1_B:
			//hsv rainbow monolithic
			if(modifier) {
				set_color_index(1, &FLAGS);
			} else {
				animlen = 399;
				mode_exe = &hsv_sweep;
			}
			break;
		case NUM2_B:
			//hsv rainbow river
			if(modifier) {
				set_color_index(2, &FLAGS);
			} else {
				animlen = 399;
				mode_exe = &hsv_river;
			}
			break;
		case NUM3_B:
			//hsv rainbow volcano
			if(modifier) {
				set_color_index(3, &FLAGS);
			} else {
				animlen = 399;
				mode_exe = &hsv_volcano;
			}
			break;
		case NUM4_B:
			//pink-cyan
			if(modifier) {
				set_color_index(4, &FLAGS);
			} else {
				animlen = 220;
				mode_exe = &miami_sheen;
			}
			break;
		case NUM5_B:
			//purple-green
			if(modifier) {
				set_color_index(5, &FLAGS);
			} else {
				animlen = 220;
				mode_exe = &toxic_sheen;
			}
			break;
		case NUM6_B:
			//yellow-cyan
			if(modifier) {
				set_color_index(6, &FLAGS);
			} else {
				animlen = 220;
				mode_exe = &cyber_sheen;
			}
			break;
		case NUM7_B:
			//pong multicolor
			if(modifier) {
				set_color_index(7, &FLAGS);
			} else {
				animlen = 560;
				mode_exe = &pong_multicolor;
			}
			break;
		case NUM8_B:
			//pong magma
			if(modifier) {
				set_color_index(8, &FLAGS);
			} else {
				animlen = 140;
				mode_exe = &pong_magma;
			}
			break;
		case NUM9_B:
			//pong white
			if(modifier) {
				set_color_index(9, &FLAGS);
			} else {
				animlen = 140;
				mode_exe = &pong_white;
			}
			break;
		default:
			return;
	}
	//reset animation cycle
	if(recvd.command != MENU_B) coloriser(true);
}

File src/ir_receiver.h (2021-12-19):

/*
 * IR_Receiver.h
 *
 * Created: 25.04.2017 1:22:03
 *  Author: Sergei Biletnikov
 */ 


#ifndef IR_RECEIVER_H_
#define IR_RECEIVER_H_

// port for connecting IR receiver
#define IRR_PORT PORTD
#define IRR_DDR DDRD
#define IRR_PIN PD2
#define IRR_PIN_PORT PIND
// init IR receiver pin port
#define init_IRR_PIN()  \
IRR_DDR&=~(1<<IRR_PIN); \
IRR_PORT|=(1<<IRR_PIN); \
EICRA|=(1<<ISC00); \
EIMSK|=(1<<INT0);
//
#define NEC_MAX_PACKET_BIT_NUMBER 32

//uncomment this to use a led to indicate when IR packet received, it blinks shortly for 100 ms
//#define IR_STATUS_LED

// Status led initialization, if it is defined
#ifdef IR_STATUS_LED
#define IR_STATUS_LED_PORT PORTB
#define IR_STATUS_LED_DDR DDRB
#define IR_STATUS_LED_PIN PB1
#define IR_STATUS_LED_ON IR_STATUS_LED_PORT|=(1<<IR_STATUS_LED_PIN)
#define IR_STATUS_LED_OFF IR_STATUS_LED_PORT&=~(1<<IR_STATUS_LED_PIN)
#define IR_STATUS_LED_TOGGLE IR_STATUS_LED_PORT^=(1<<IR_STATUS_LED_PIN)
#endif // IR_STATUS_LED


// Packet of data
struct IR_Packet
{
	uint16_t addr; // address, for standard NEC it is only one byte address (the value in the lowest byte), for extended protocol the address takes 2 bytes
	uint8_t command; // command 
	uint8_t repeat; // 0 if the packet is not repeat	
};

// init receiver
extern void init_receiver();

// check if new data packet received
// 0 - no, otherwise yes
// received_packet is a pointer to the IR_Packet structure to receive the data
// the packet updated only if the function result is not 0
extern uint8_t check_new_packet(struct IR_Packet * received_packet);

#endif /* IR_RECEIVER_H_ */
